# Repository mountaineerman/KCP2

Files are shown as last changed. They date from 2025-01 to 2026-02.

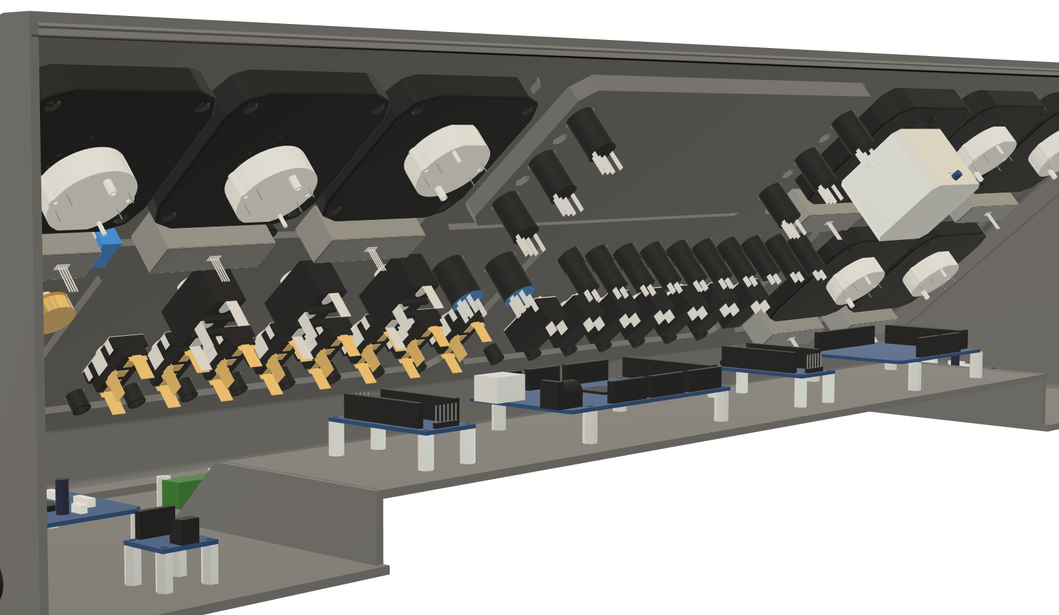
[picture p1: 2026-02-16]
KCP2-physical/Photos/ElectronicsMounted.PNG

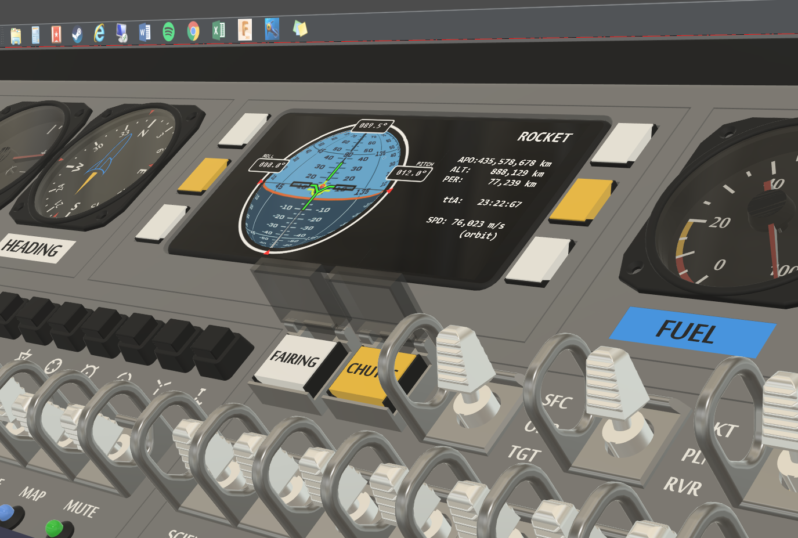
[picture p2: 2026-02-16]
KCP2-physical/Photos/ModuleHredesign.PNG

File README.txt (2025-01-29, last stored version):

Fly:
1. Connect Control Panel to 12V power.
2. Power on Control Panel.
3. Connect Control Panel to computer.
4. Run uber_launch_KCP2_play.cmd (or uber_launch_KCP2_dev.cmd)
5. Launch Flight.
6. Start RPC Server (do once):
	Open kRPC settings
	Select "Add server"
	Keep default settings (TBC)
	Select "Start"
7. If doing development, launch KKIM via F5 from VS Code.

If Control Panel (KMega/KNano) is not correctly programmed, run: re-program_control_panel.cmd

Re-generate KKIM JAR file:
1. Open KKIM in VS Code.
2. Check branch is correct in Git Bash.
3. In the Explorer on the left side, expand JAVA PROJECTS.
4. Beside JAVA PROJECTS, select "Export Jar..." button.
	a. Select main class: Main (mountaineerman.kcp2.kkim.main.Main).
	b. Leave default elements selected.
5. Move/rename: C:\dev\KCP2\KCP2.jar to C:\dev\KCP2\KKIM\KKIM.jar

Graceful shutdown: (center-right glass cockpit button)

Optional: Open ckan.exe & apply mod updates

Logging in to GitHub: use Personal Access Token

KMega Diagnostic Mode (KKIM not used):
1. Connect Control Panel to 12V power.
2. Power on Control Panel.
3. Connect Control Panel to computer.
4. Open Arduino IDE.
5. Open Tools > Serial Monitor.
6. On Control Panel, select Diagnostic Mode button (center-left).

(1) TROUBLESHOOTING ===================================================================================================================================================================================

(A) DEVELOPMENT =======================================================================================================================================================================================

Symptoms:
When trying to program the Arduino board, get message: "the selected serial port does not exist or your board is not connected"
Fix:
In Arduino IDE, select the port to activate it.

Symptoms:
1. When trying to program the Arduino board, get errors: "stk500v2_ReceiveMessage(): timeout"
2. Inspecting Arduino IDE > Tools > Port only shows COM1, instead of COM3.
Fix:
Check USB cable connecting KMega to computer is plugged in and in "ON" position.

Symptoms:
1. When trying to program the Arduino board, get errors: "stk500v2_ReceiveMessage(): timeout"
2. Inspecting Arduino IDE > Tools > Port shows "COM3 (Arduino Mega or Mega 2560)".
Cause 1:
The code is caught in a tight loop, which is preventing the bootloader from connecting.
Fix 1:
Select the "Upload" button. Right before bootloader gets to orange text, hit the RST (reset) mom switch.
Cause 2:
https://forum.arduino.cc/t/avrdude-stk500v2_receivemessage-timeout-sometimes-random/586515
It is necessary to reset the ATmega2560 microcontroller on the Arduino Mega in order to activate the bootloader, which handles the upload. The bootloader only runs for a short time waiting for the computer to start the upload. Since the Arduino IDE spends some time compiling the sketch before actually starting the upload, you have to get the timing right, otherwise the bootloader will have already timed out and exited to the sketch previously loaded on the board before the computer even starts the upload. There is a circuit on the Mega that causes this reset to happen automatically at just the right time. What is connected to the Reset pin can disrupt the automatic circuit.
Fix 2a (temporary):
Disconnected the reset wire to Arduino Mega. The Mega started being programmable reliably.
Fix 2b (TBC):
Remove the 5V and Blue LED from the Reset circuit.

Symptoms: (Delete after settingsFilename absolute path is replaced with relative path)
Changes to config.properties are not being seen by the system
Fix:
Check KKIMProp:settingsFilename is pointing to the correct file.

(B) RUNTIME: ==========================================================================================================================================================================================

Symptoms:
-COMMS LED is flashing
-KKIM ok.
-Control Panel not displaying any information from KSP
-Control Panel not able to control any values in KSP
Cause:
KMega is not receiving control packets from KKIM.
Fix:
Double-check the COM port in KMega configuration.h and KKIM config.properties, and they match what Arduino IDE is detecting.

Symptoms:
Control Panel can control the in-game controls, but there is "jitter". For example, if brake is active on the panel, it flickers between on/off in-game. Similar for throttle.
Fix:
Perhaps some garbage coming through on a port that was not properly closed. Restarting Eclipse and KSP, plus power cycling the panel resolved it.

Symptoms:
-Most lights on.
-Arduino Mega does not "start up".
-Arduino Mega does not respond to Reset signal.
-Programming via Arduino IDE succeeds, but Arduino does not restart.
Cause:
A prototyping sketch was loaded. Everything was working as it should have.

Symptoms:
During "full sweep" of a stepper motor, it "bounces" off an edge and stops in the middle instead of in the CCW position.
Cause:
Initial miscalibration combined with "resonant speed".
Fix:
Do full sweep of motor at a slower speed (300 steps/second) using KMega diagnostic mode.

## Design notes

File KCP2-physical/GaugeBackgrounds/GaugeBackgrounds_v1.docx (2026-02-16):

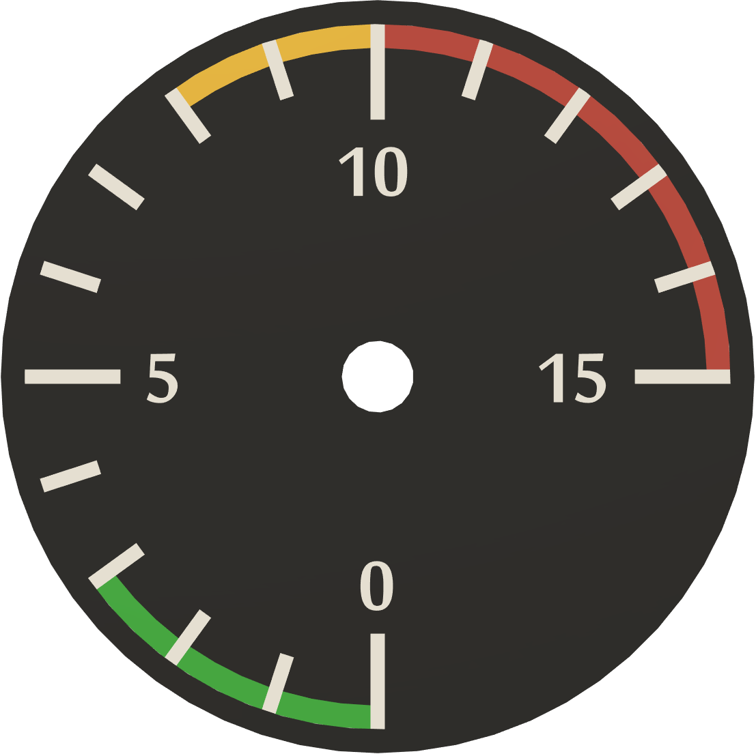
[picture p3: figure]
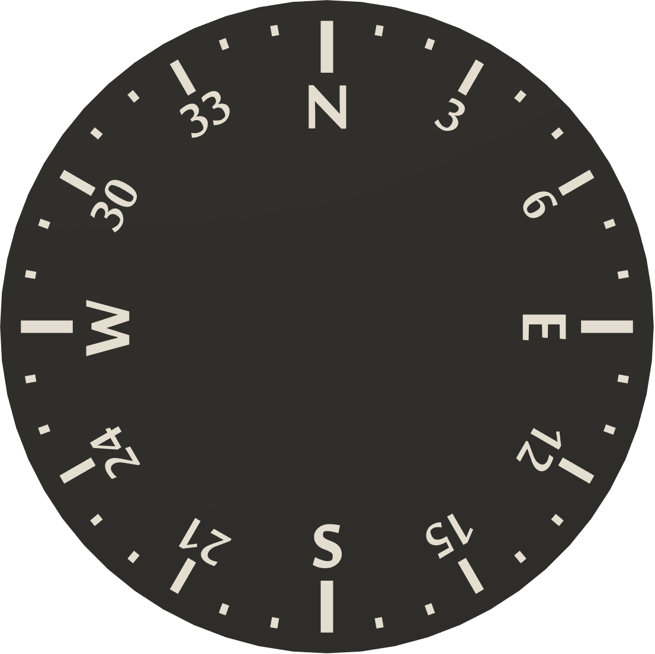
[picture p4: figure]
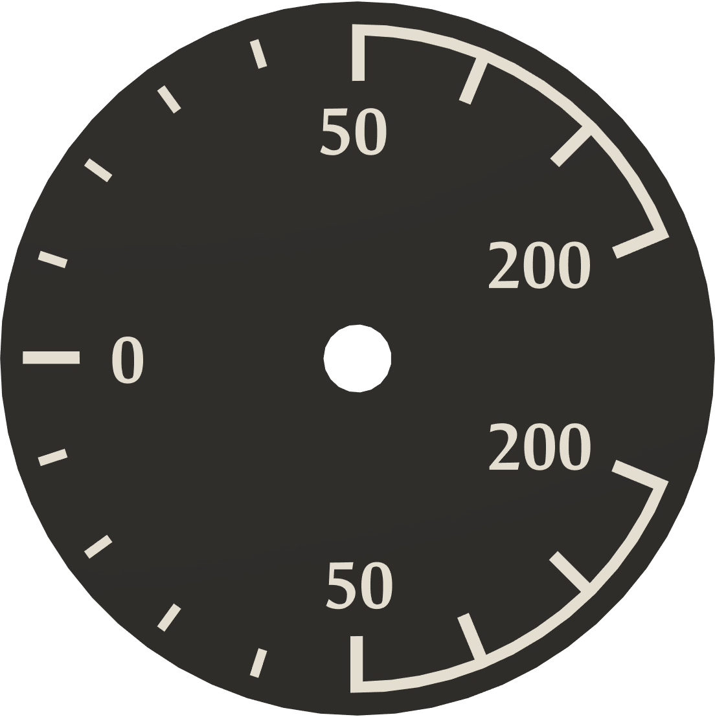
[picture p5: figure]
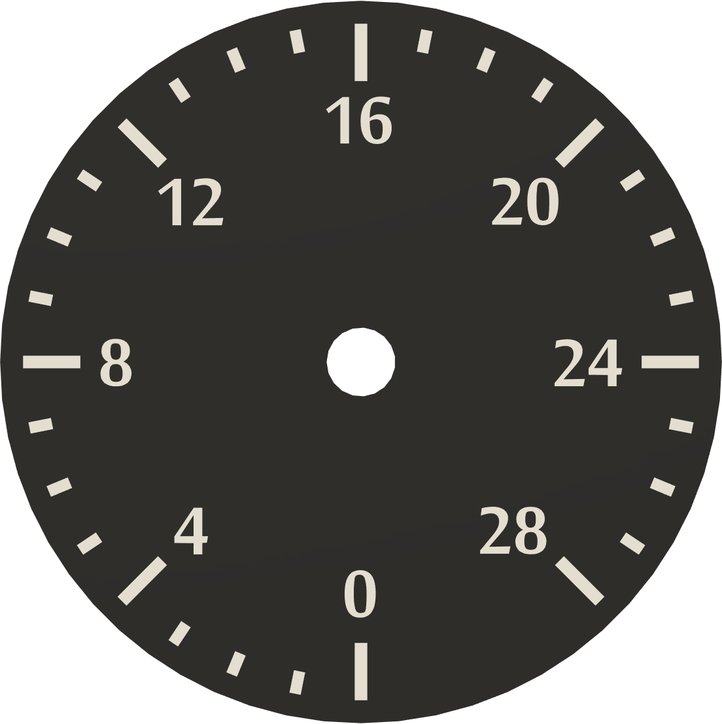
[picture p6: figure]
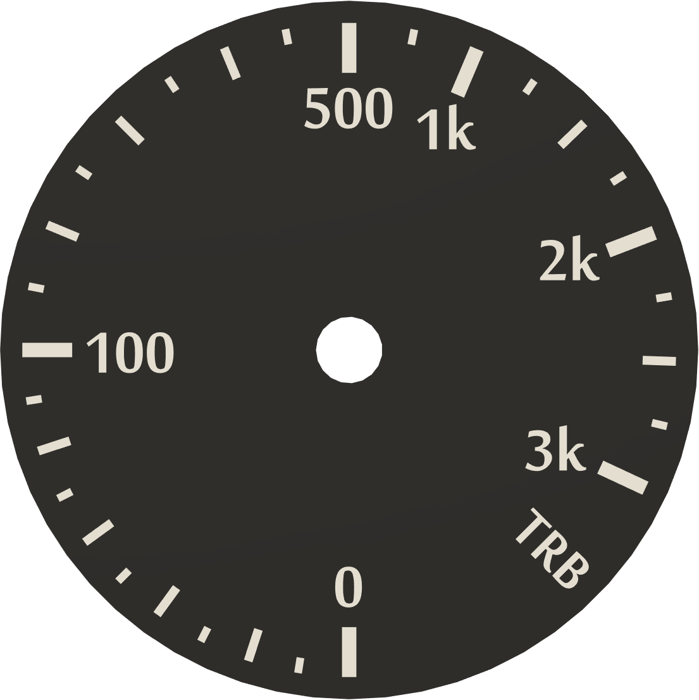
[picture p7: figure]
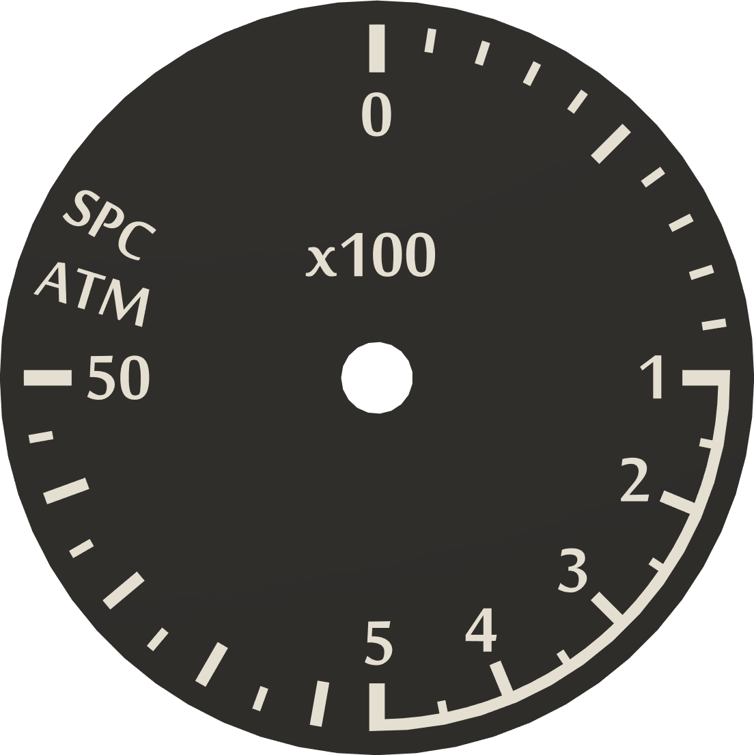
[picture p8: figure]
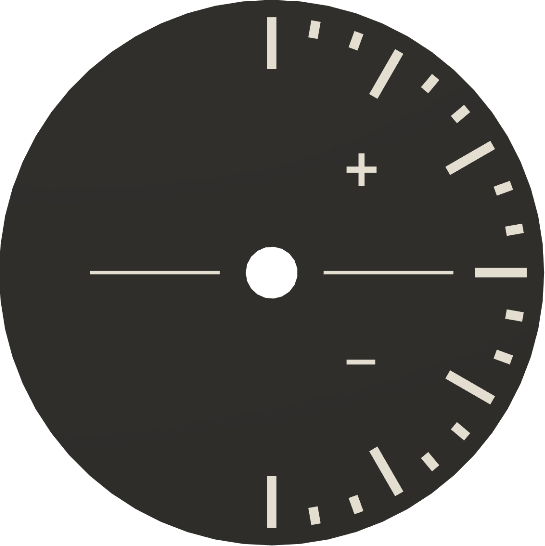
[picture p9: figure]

Note: hole 6mm* Backplate diameter: 63 mm Optimum viewing size: 95%

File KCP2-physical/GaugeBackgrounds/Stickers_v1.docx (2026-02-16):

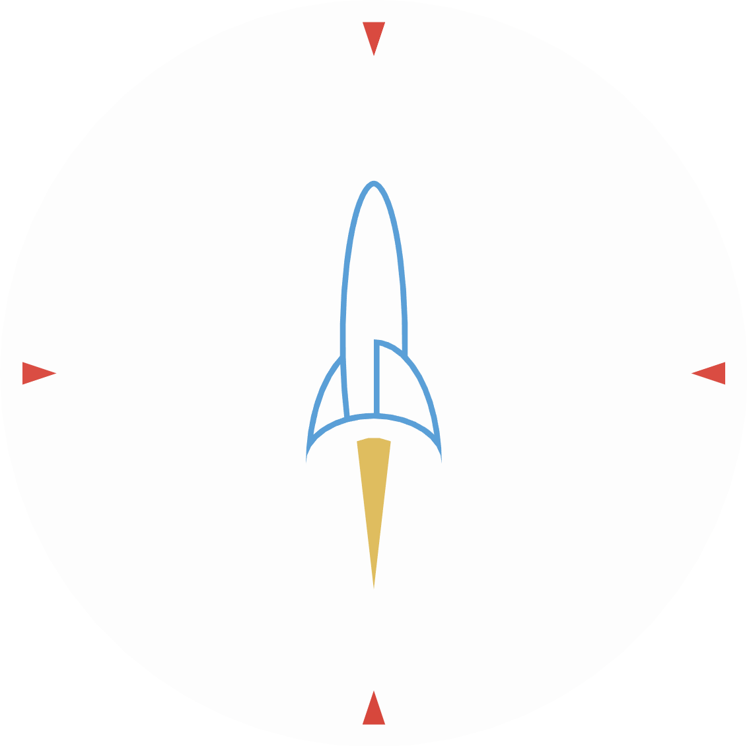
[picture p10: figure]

CHUTE

20x14

FRNG

21x15

CHUTE

FRNG

22x16

CHUTE

FRNG

EasyDriver

LED1

LED2

LED3

LED4

Mega

MUX

Nano

vid6606-1

vid6606-2

vid6606-3

Rocket sticker diameter: 66 mm (v9) Button dimensions: 21 x 15 mm

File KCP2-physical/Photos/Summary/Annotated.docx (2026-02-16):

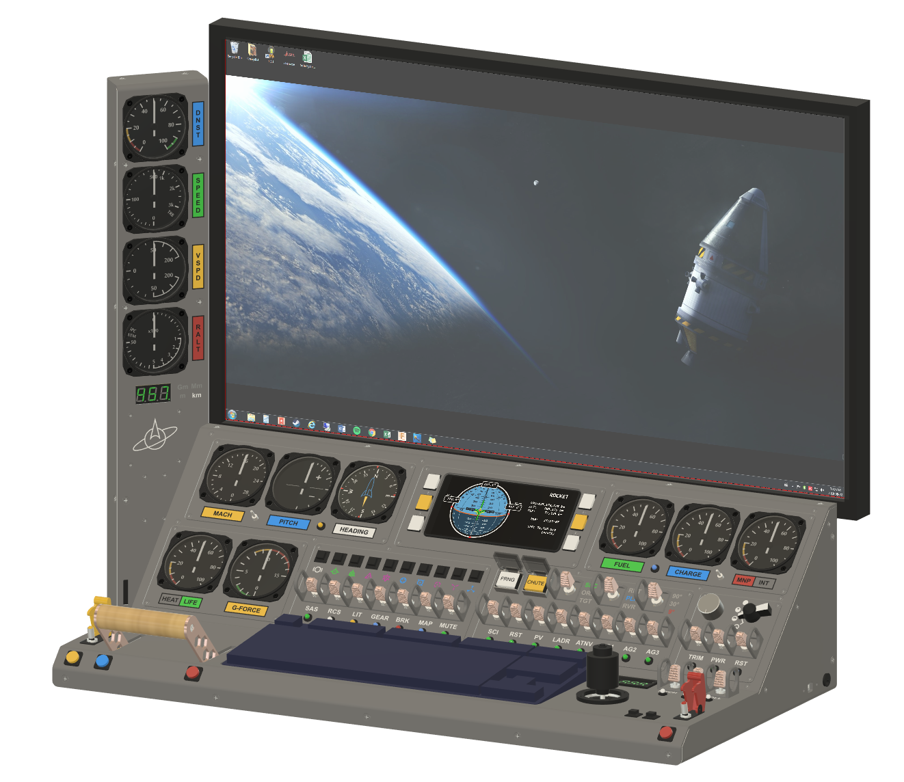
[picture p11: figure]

Gauge Tower

Panel Casing

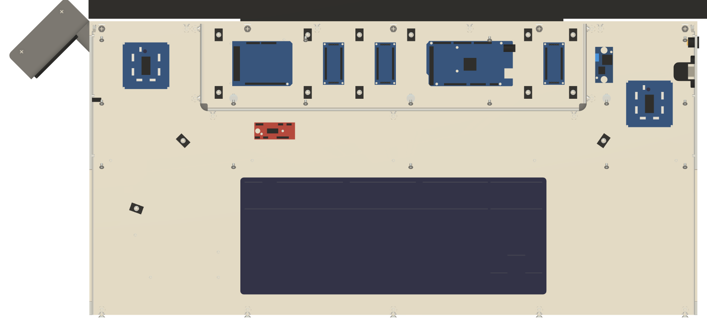
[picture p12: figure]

Arduino Mega

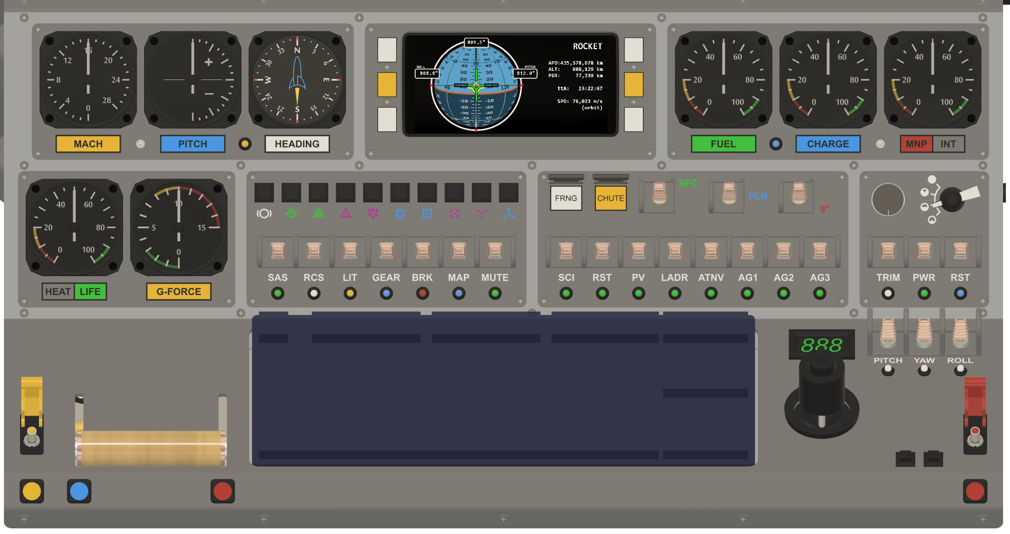
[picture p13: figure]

Module F

Module E

Module D

Module C

Module B

Module A

Module G

Module H

Module I

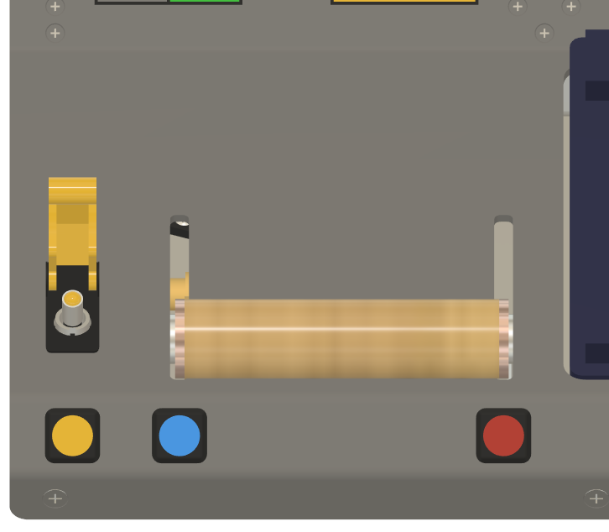
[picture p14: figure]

Brake Momentary Pushbutton

Throttle Toggle Pushbutton

Staging Momentary Pushbutton

Throttle Handlebar

Staging Missile Switch

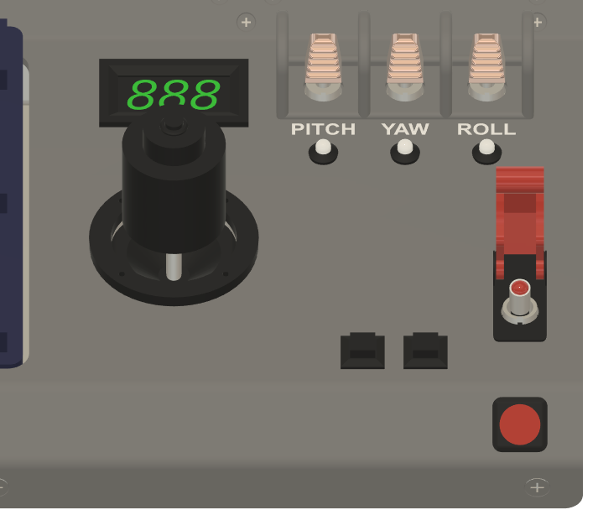
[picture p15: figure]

Trim Controls
(toggle switches)

Abort Missile Switch

Abort Momentary Pushbutton

Time Warp >>

Voltmeter

Time Warp <<

Joystick
(3 axis
+ button)

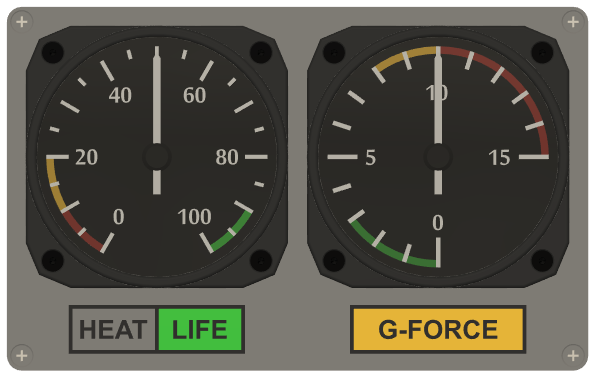
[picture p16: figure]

Geared Analog Stepper Gauges (315° range)

Backlit Lightboxes

(Life Support)

(Max Heat)

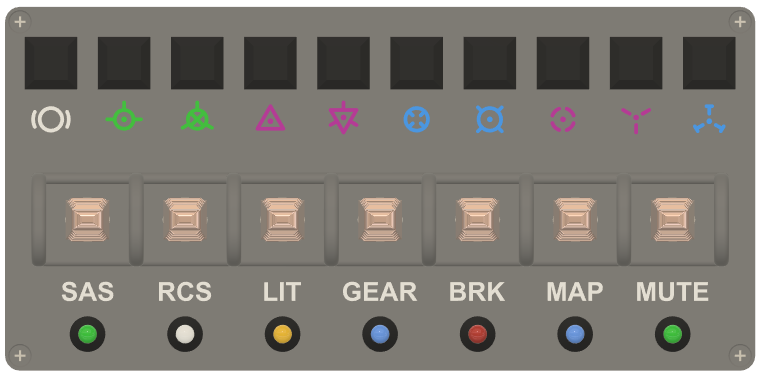
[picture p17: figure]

Backlit

(Hold) (Retrograde) (Anti-normal) (Radial Out) (Anti-Target)

(Prograde) (Normal) (Radial In) (Target) (Maneuver)

Auto-pilot

Toggle Switches

(Stability (Reaction (Lights) (Landing (Brake) (Ship/Map (Phone
Assist Control Gear) view) Speaker)
System) System)

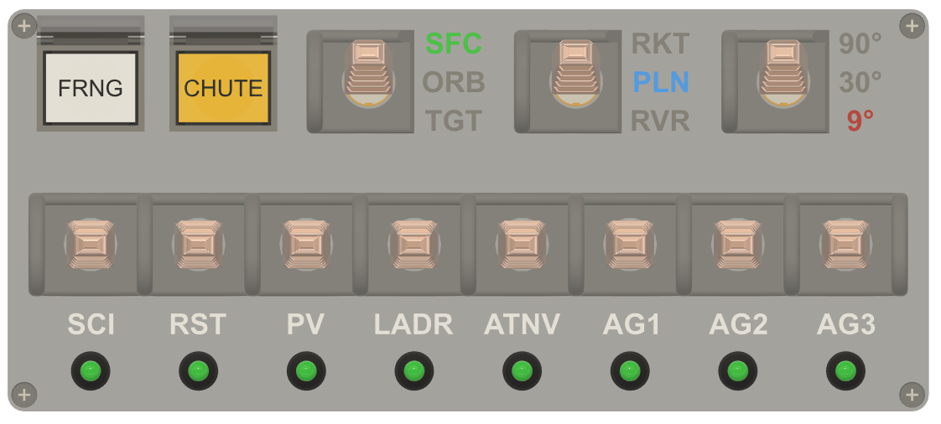
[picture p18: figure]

Covered
Push
Buttons

(Science (Reset (Solar (Ladder) (Auto- (Action (Action (Action
Experiments) Sci.) Panels) Navigation) Group1) Group2) Group3)

Momentary Toggle Switches

3-position Toggle Switches

Speed Reference Maneuver Mode
(Surface) (Rocket)
(Orbit) (Plane)
(Target) (Rover) Pitch Precision

Fairing

Parachute

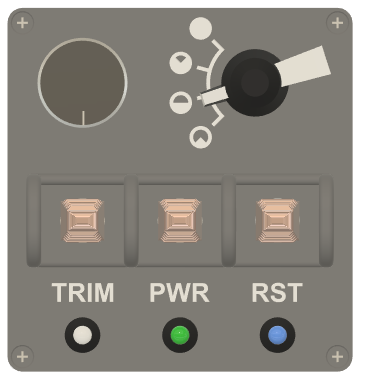
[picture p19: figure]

Trim
Master
Control

Control Panel Master Power
Switch

Arduino Mega Reset

Control Sensitivity
(4-position)

Multi-purpose Potentiometer

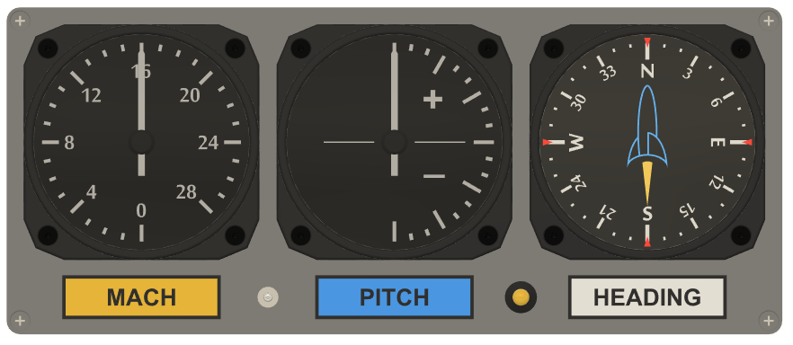
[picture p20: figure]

HEAT/LIFE Toggle Switch

Vehicle Pitch
(90°/30°/9°)

Vehicle Compass Heading

Panel-Computer Communications LED

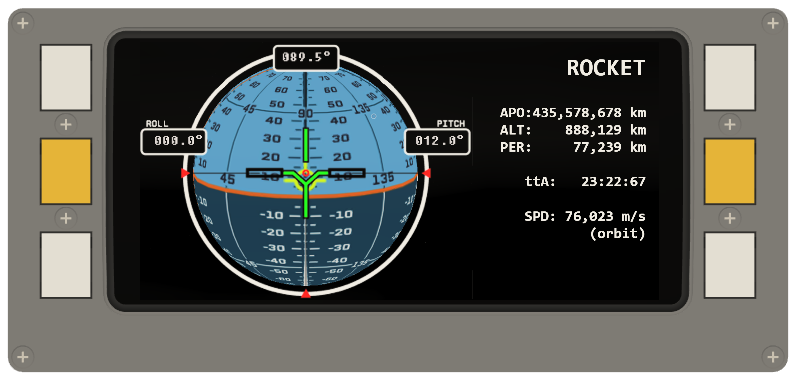
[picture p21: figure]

TR: Top Right

CR: Center Right

BR: Bottom Right

TL: Top Left

CL: Center Left

BL: Bottom Left

Glass Cockpit Momentary Pushbuttons

Phone

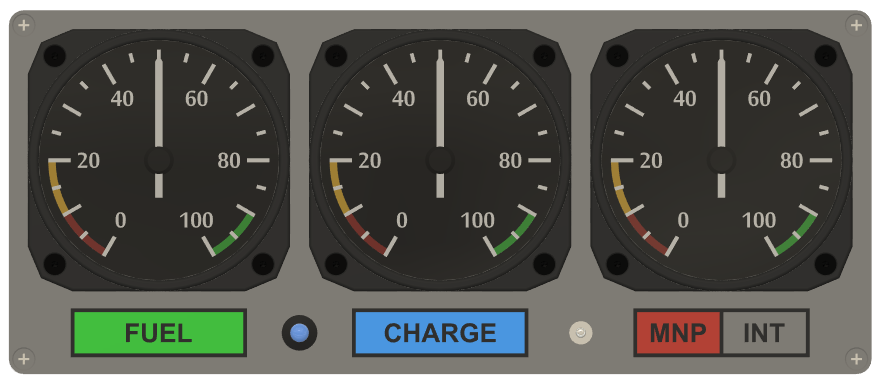
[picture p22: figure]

MNP/INT
Toggle Switch

Intake Air

Monopropellant

Electricity Reserve

Charge
Rate-Of-Change RGB LED

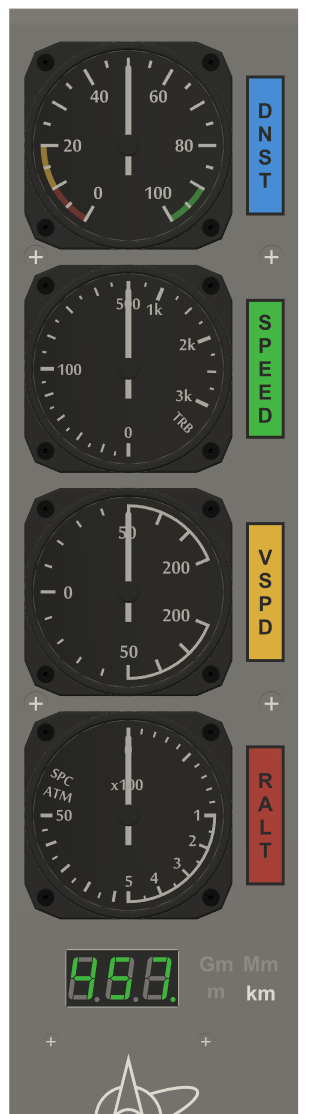
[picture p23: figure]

Altitude

Vehicle Radar Altitude (m)

Vehicle Vertical Speed (m/s)

Vehicle Speed (m/s)

Air
Density

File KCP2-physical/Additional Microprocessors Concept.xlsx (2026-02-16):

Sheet: Pin updates
Driver Board | Gauge | Module | Pin | Mega Pin (old) | Mega Pin (new) | NGH A Pin | NGH B Pin
EasyDriver | Heading | G | SLP | 44 | - | D2 | -
 |  |  | MS1 | 45 | - | D3 | -
 |  |  | MS2 | 46 | - | D4 | -
 |  |  | STEP | 47 | - | D5 | -
 |  |  | DIR | 48 | - | D6 | -
VID6606 #1 (Main Left?) | Heat/Life Support | C | Frequency | 22 | - | D7 | -
 |  |  | Direction | 23 | - | D8 | -
 | G-Force | C | Frequency | 24 | - | D9 | -
 |  |  | Direction | 25 | - | D10 | -
 | Mach | G | Frequency | 26 | - | D11 | -
 |  |  | Direction | 27 | - | D12 | -
 | Pitch | G | Frequency | 28 | - | A0 (D14) | -
 |  |  | Direction | 29 | - | A1 (D15) | -
VID6606 #2 (Main Right?) | Fuel | I | Frequency | 30 | - | A2 (D16) | -
 |  |  | Direction | 31 | - | A3 (D17) | -
 | Charge | I | Frequency | 32 | - | - | D2
 |  |  | Direction | 33 | - | - | D3
 | Monopropellant /Intake | I | Frequency | 34 | - | - | D4
 |  |  | Direction | 35 | - | - | D5
VID6606 #3 (Gauge Tower) | Air Density | GT | Frequency | 36 | - | - | D6
 |  |  | Direction | 37 | - | - | D7
 | Speed | GT | Frequency | 38 | - | - | D8
 |  |  | Direction | 39 | - | - | D9
 | Vertical Speed | GT | Frequency | 40 | - | - | D10
 |  |  | Direction | 41 | - | - | D11
 | Radar Altitude | GT | Frequency | 42 | - | - | A0 (D14)
 |  |  | Direction | 43 | - | - | A1 (D15)
 |  | H | PIN_GLASS_COCKPIT_CR_SWITCH | 16 (TX2) | 22 | - | -
 |  | H | PIN_GLASS_COCKPIT_BR_SWITCH | 17 (RX2) | 23 | - | -
 |  | H | PIN_GLASS_COCKPIT_BL_SWITCH | 14 (TX3) | 24 | - | -
 |  | H | PIN_GLASS_COCKPIT_TR_SWITCH | 15 (RX3) | 25 | - | -
 |  | Case | "NGH A" - RX | - | 16 (TX2) | RX0 | -
 |  | Case | "NGH A" - TX | - | 17 (RX2) | TX1 | -
 |  | Case | "NGH B" - RX | - | 14 (TX3) | - | RX0
 |  | Case | "NGH B" - TX | - | 15 (RX3) | - | TX1
 |  |  |  |  | Pins Required: | 0 | 0 | Nano has 22 pins!

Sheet: Timing Budgets
Arduino Mega: standardOperatingMode | 0
 | Send input packet (periodic) | 0
 |  | refreshInputStatus
 |  | assembleInputRefreshPacket
 |  | sendInputRefreshPacket
 | ingestDataFromSerialBufferToPacketBuffer (regular)
 | ingestOutputRefreshPacket (periodic) | 0
 |  | getOutputRefreshPacket
 |  | unpackOutputRefreshPacketIntoModel
 |  | writeLEDStatusToLEDDriverBoards
 |  | assembleAltitudePacket
 |  | sendAltitudePacket
 |  | assembleGaugePacket1
 |  | sendGaugePacket1
 |  | assembleGaugePacket2
 |  | sendGaugePacket2
 | runStepperIfNecessary (Heading only)
Gauge Arduino #1 (& #2): standardOperatingMode | 0
 | ingestDataFromSerialBufferToPacketBuffer (regular)
 | ingestGaugePacket (periodic) | 0
 |  | getOutputRefreshPacket
 |  | unpackOutputRefreshPacketIntoModel

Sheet: Mega vs Nano
 | Mega (2560 rev3) | Nano
Pins | 54 | 22
PWM Pins | 15 | 6
Analong Input Pins | 16 | 8
SRAM | 8 kB | 2 kB
EEPROM | 4 kB | 1 kB
Clock Speed | 16 MHz | 16 MHz

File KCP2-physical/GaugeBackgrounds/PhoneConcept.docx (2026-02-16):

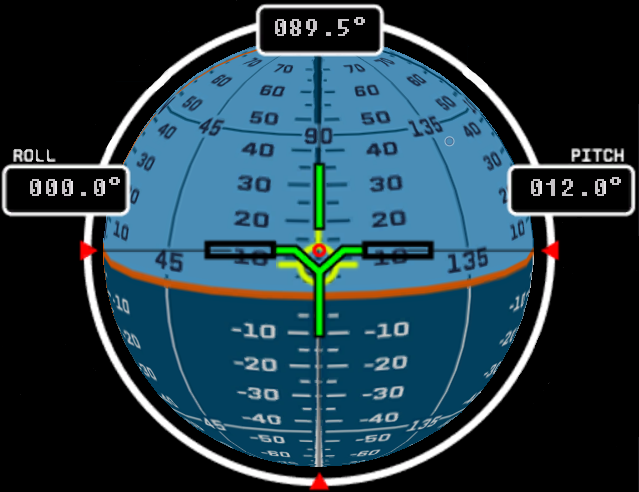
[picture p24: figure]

ROCKET

APO:435,578,678 km

ALT: 888,129 km

PER: 77,239 km

ttA: 23:22:67

SPD: 76,023 m/s

(orbit)

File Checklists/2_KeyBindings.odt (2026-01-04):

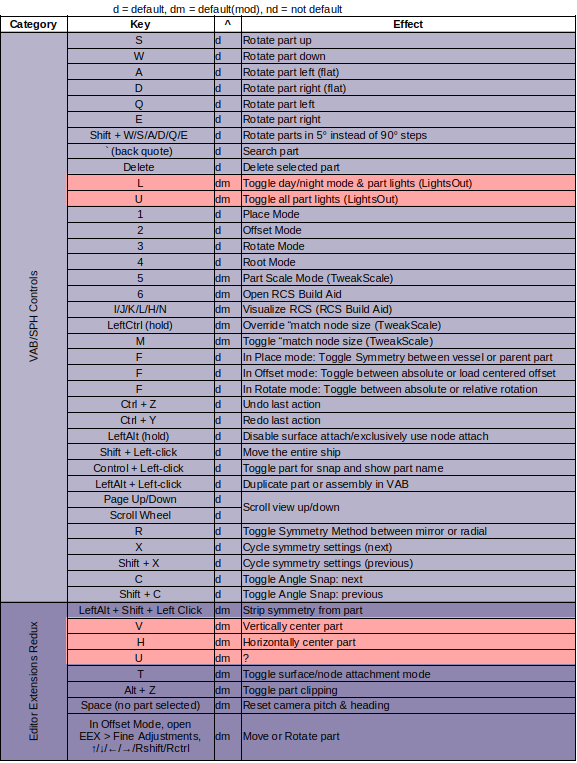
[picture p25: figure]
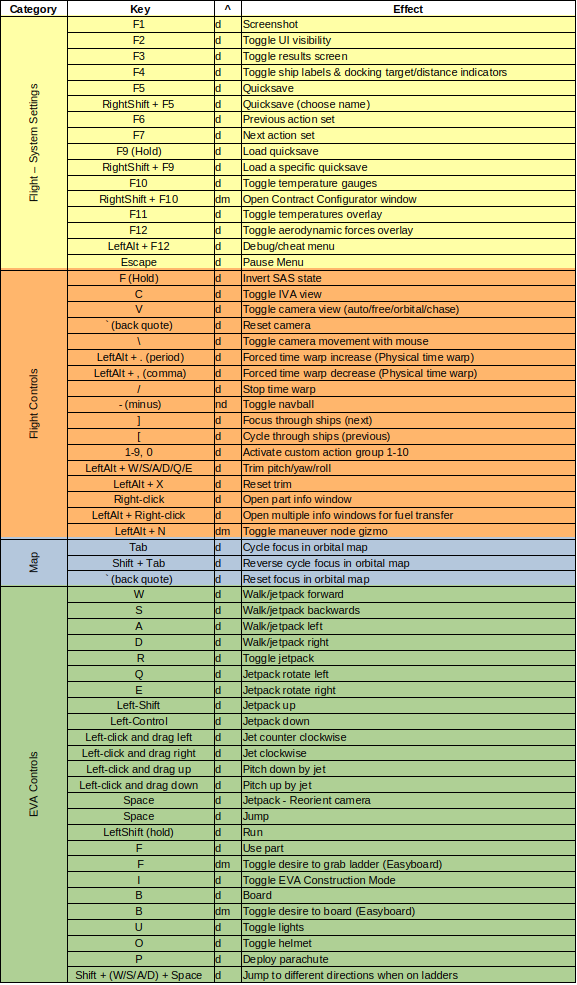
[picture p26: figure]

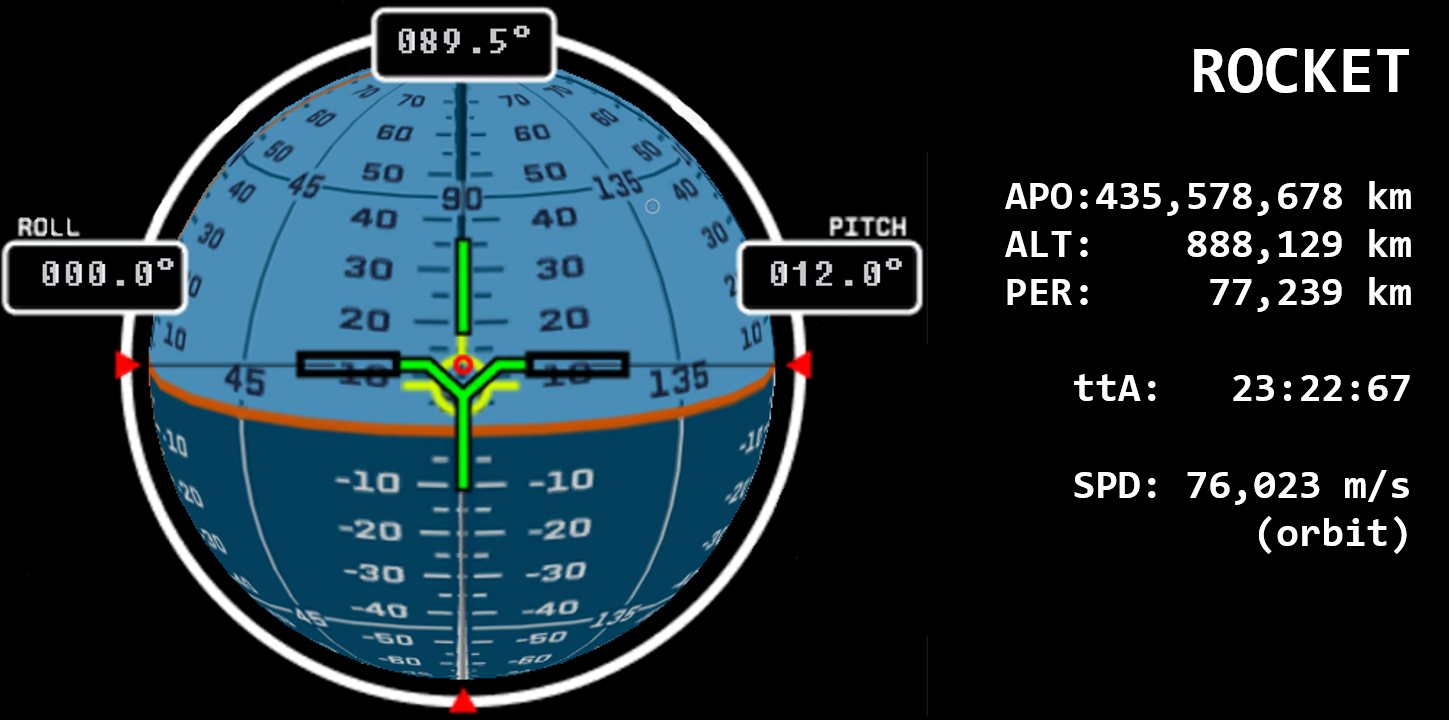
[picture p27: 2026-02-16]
KCP2-physical/GaugeBackgrounds/NavballPhoneConcept.PNG

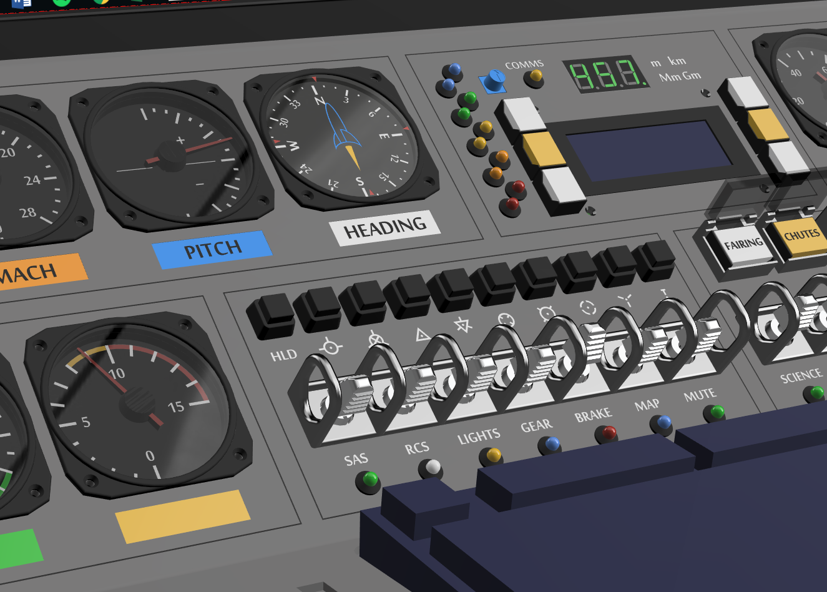
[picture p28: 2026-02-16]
KCP2-physical/Photos/Capture.PNG

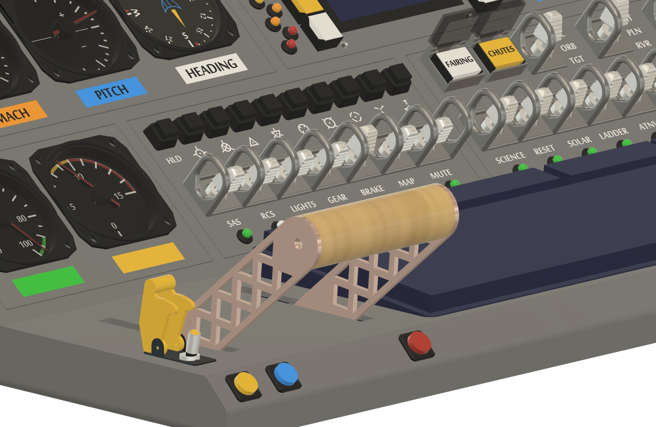
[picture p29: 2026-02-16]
KCP2-physical/Photos/PrelimThrottleHandle.PNG

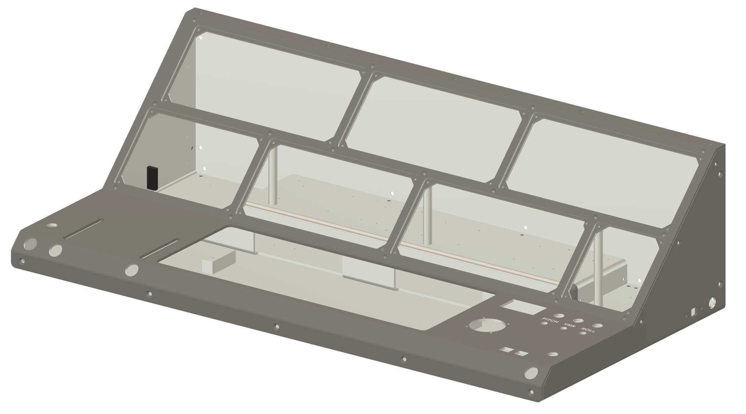
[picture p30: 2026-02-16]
KCP2-physical/Photos/PanelCasing.PNG

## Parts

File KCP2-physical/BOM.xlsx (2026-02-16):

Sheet: Bill of Materials
Module | Part | # | CA | US | CAD | USD | Total (CAD) | Note
All | Panel Casing & Module Plates | 0 | Metal Alloy Fabrication |  | $1881.94 |  | $0.00 | (For Sum)
A | Small Gear (16T, 1/4" bore) | 1 |  | Sparkfun (https://www.sparkfun.com/products/12158) |  | $12.99 | $17.02
A | Large Gear (32T, 1/4" bore) | 1 |  | Sparkfun (https://www.sparkfun.com/products/12476) |  | $12.99 | $17.02
A | Missile Switch (lit, yellow) | 1 | Elmwood (https://elmwoodelectronics.ca/products/illuminated-toggle-switch-with-cover-yellow) | Adafruit (https://www.adafruit.com/product/3219) | $4.99 |  | $4.99 | Staging
A | Pushbutton (lit, yellow, mom) | 1 | Elmwood (https://elmwoodelectronics.ca/products/16mm-illuminated-pushbutton-yellow-momentary) | Adafruit (https://www.adafruit.com/product/1441) | $3.79 |  | $3.79 | Staging
A | Potentiometer (10 kohm) | 1 | Elmwood (https://elmwoodelectronics.ca/products/panel-mount-10k-potentiometer-breadboard-friendly) | Adafruit (https://www.adafruit.com/product/562) | $3.49 |  | $3.49
A | Pushbutton (lit, blue, latching) | 1 | Elmwood (https://elmwoodelectronics.ca/products/16mm-illuminated-pushbutton-blue-latching-on-off-switch) | Adafruit (https://www.adafruit.com/product/1476) | $4.59 |  | $4.59 | Throttle
A | Pushbutton (lit, red, mom) | 1 | Elmwood (https://elmwoodelectronics.ca/products/16mm-illuminated-pushbutton-red-momentary) | Adafruit (https://www.adafruit.com/product/1439) | $3.79 |  | $3.79 | Brake
A | Rubber washers | 4 | Lowes |  | $1.31 |  | $5.23 | Throttle
A | 1" x 48" wooden dowel | 1 | Lowes |  | $7.34 |  | $7.34 | Throttle
A | Throttle Handlebar | 2 | Metal Alloy Fabrication |  | $23.84 |  | $47.67
A | Throttle Mounting Bracket | 1 | Metal Alloy Fabrication |  | $57.54 |  | $57.54
B | Missile Switch (lit, red) | 1 | Elmwood (https://elmwoodelectronics.ca/products/illuminated-toggle-switch-with-cover-red) | Adafruit (https://www.adafruit.com/product/3218) | $4.99 |  | $4.99 | Abort
B | Pushbutton (lit, red, mom) | 1 | Elmwood (https://elmwoodelectronics.ca/products/16mm-illuminated-pushbutton-red-momentary) | Adafruit (https://www.adafruit.com/product/1439) | $3.79 |  | $3.79 | Abort
B | 4-Axis Joystick | 1 |  | Ebay (https://www.ebay.ca/itm/282456733701) |  | $13.59 | $17.80
B | Panel Voltmeter | 1 | Elmwood (https://elmwoodelectronics.ca/products/panel-volt-meter) | Adafruit (https://www.adafruit.com/product/575) | $11.99 |  | $11.99
B | Pushbutton (black, mom) | 2 | Digikey (https://www.digikey.ca/en/products/detail/e-switch/PS1057ABLK/46305) |  | $2.44 |  | $4.88 | Time Warp
B | Toggle Switch | 3 | Elmwood (https://elmwoodelectronics.ca/products/9276) | Sparkfun (https://www.sparkfun.com/products/9276) | $2.99 |  | $8.97 | Pitch/Yaw/Roll
B | 5mm LED (white) | 3 | Elmwood (https://elmwoodelectronics.ca/products/100-led-assortment) |  | $0.09 |  | $0.27 | Pitch/Yaw/Roll
B | 5mm LED Holder | 3 |  | Adafruit (https://www.adafruit.com/product/2174) | $0.19 |  | $0.57
C | x27.168 stepper motor | 2 | Elmwood (https://elmwoodelectronics.ca/products/automotive-gauge-stepper-motor) | Adafruit (https://www.adafruit.com/product/2424) | $13.19 |  | $26.38
C | Rectangular RGB LED | 3 | Elmwood (https://elmwoodelectronics.ca/products/diffused-rectangular-5mm-rgb-leds-pack-of-10) | Adafruit (https://www.adafruit.com/product/2739) | $0.90 |  | $2.70
C | Module C Acrylic Plate | 1 | Metal Alloy Fabrication |  | $74.39 |  | $74.39
D | 5mm LED (yellow) | 1 | Elmwood (https://elmwoodelectronics.ca/products/100-led-assortment) |  | $0.09 |  | $0.09 | Lights
D | 5mm LED (green) | 2 | Elmwood (https://elmwoodelectronics.ca/products/100-led-assortment) |  | $0.09 |  | $0.18 | SAS, Mute
D | 5mm LED (white) | 2 | Elmwood (https://elmwoodelectronics.ca/products/100-led-assortment) |  | $0.09 |  | $0.18 | RCS, AUTOPILOT-HOLD
D | 5mm LED (red) | 1 | Elmwood (https://elmwoodelectronics.ca/products/100-led-assortment) |  | $0.09 |  | $0.09 | Brake
D | 5mm LED (blue) | 2 | Elmwood (https://elmwoodelectronics.ca/products/100-led-assortment) |  | $0.09 |  | $0.18 | Gear, Map
D | 5mm LED Holder | 7 |  | Adafruit (https://www.adafruit.com/product/2174) | $0.19 |  | $1.33
D | Toggle Switch | 7 | Elmwood (https://elmwoodelectronics.ca/products/9276) | Sparkfun (https://www.sparkfun.com/products/9276) | $2.99 |  | $20.93
D | Pushbutton (black, mom) | 10 | Digikey (https://www.digikey.ca/en/products/detail/e-switch/PS1057ABLK/46305) |  | $2.44 |  | $24.40 | Autopilot
D | Rectangular RGB LED | 9 | Elmwood (https://elmwoodelectronics.ca/products/diffused-rectangular-5mm-rgb-leds-pack-of-10) | Adafruit (https://www.adafruit.com/product/2739) | $0.90 |  | $8.09 | Autopilot Reticules (Hold, Prograde, Retrograde, Normal, Anti-Normal, Radial In, Radial Out, Target Prograde, Target Retrograde, Maneuver)
D | Module D Acrylic Plate | 1 | Metal Alloy Fabrication |  | $88.08 |  | $88.08
E | 5mm LED (blue) | 3 | Elmwood (https://elmwoodelectronics.ca/products/100-led-assortment) |  | $0.09 |  | $0.27 | 3POS Lights
E | 5mm LED (red) | 3 | Elmwood (https://elmwoodelectronics.ca/products/100-led-assortment) |  | $0.09 |  | $0.27 | 3POS Lights
E | 5mm LED (green) | 11 | Elmwood (https://elmwoodelectronics.ca/products/100-led-assortment) |  | $0.09 |  | $0.99 | 3POS Lights, Action Groups
E | 5mm LED Holder | 11 |  | Adafruit (https://www.adafruit.com/product/2174) | $0.19 |  | $2.09
E | Toggle Switch - Momentary | 8 | Digikey (https://www.digikey.ca/product-detail/en/electroswitch/7162C/451-1166-ND/2679549) |  | $6.01 |  | $48.06
E | Toggle Switch - SP3T | 3 | Ebay (https://www.ebay.ca/itm/12V-Metal-Toggle-Flick-Switch-ON-OFF-ON-Car-Boat-Dash-Light-3-Position-SP3T-/361502103461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) |  | $1.79 |  | $5.37
E | Pushbutton Cover | 2 | Ebay (https://www.ebay.ca/itm/310827399171) |  | $1.09 |  | $2.17
E | Pushbutton (lit, yellow, rectangular-large) | 1 | Ebay (https://vod.ebay.ca/vod/FetchOrderDetails?transid=885606284025&itemid=382086328207&qu=2&ul_noapp=true) |  | $3.04 |  | $3.04 | Chute
E | Pushbutton (lit, white, rectangular-large) | 1 | Ebay (https://vod.ebay.ca/vod/FetchOrderDetails?transid=885606284025&itemid=382086328207&qu=2&ul_noapp=true) |  | $3.04 |  | $3.04 | Fairing
E | Module E Acrylic Plate | 1 | Metal Alloy Fabrication |  | $88.59 |  | $88.59
F | 5mm LED (green) | 1 | Elmwood (https://elmwoodelectronics.ca/products/100-led-assortment) |  | $0.09 |  | $0.09 | Power
F | 5mm LED (blue) | 1 | Elmwood (https://elmwoodelectronics.ca/products/100-led-assortment) |  | $0.09 |  | $0.09 | Reset
F | 5mm LED (white) | 1 | Elmwood (https://elmwoodelectronics.ca/products/100-led-assortment) |  | $0.09 |  | $0.09
F | 5mm LED Holder | 3 |  | Adafruit (https://www.adafruit.com/product/2174) | $0.19 |  | $0.57
F | 3mm LED (white) | 4 |  |  | $0.00 |  | $0.00 | 4POS Twist Switch Lights
F | Toggle Switch | 2 | Elmwood (https://elmwoodelectronics.ca/products/9276) | Sparkfun (https://www.sparkfun.com/products/9276) | $2.99 |  | $5.98 | Power
F | Toggle Switch - Momentary | 1 | Digikey (https://www.digikey.ca/product-detail/en/electroswitch/7162C/451-1166-ND/2679549) |  | $6.01 |  | $6.01 | Reset
F | Potentiometer (10 kohm) | 1 | Elmwood (https://elmwoodelectronics.ca/products/panel-mount-10k-potentiometer-breadboard-friendly) | Adafruit (https://www.adafruit.com/product/562) | $3.49 |  | $3.49
F | Potentiometer Knob | 1 | Elmwood (https://elmwoodelectronics.ca/products/10002) |  | $3.99 |  | $3.99 | Fits 1/4" shaft
F | INA169 DC Current Sensor | 1 | Elmwood (https://elmwoodelectronics.ca/products/ina169-analog-dc-current-sensor-breakout-60v-5a-max) | Adafruit (https://www.adafruit.com/product/1164) | $13.99 |  | $13.99
F | 4POS Twist Switch | 1 |  |  | $0.00 |  | $0.00
F | Module F Acrylic Plate | 1 | Metal Alloy Fabrication |  | $70.99 |  | $70.99
G | x27.168 stepper motor | 2 | Elmwood (https://elmwoodelectronics.ca/products/automotive-gauge-stepper-motor) | Adafruit (https://www.adafruit.com/product/2424) | $13.19 |  | $26.38
G | 5mm LED (yellow) | 1 | Elmwood (https://elmwoodelectronics.ca/products/100-led-assortment) |  | $0.09 |  | $0.09 | COMMS
G | 5mm LED Holder | 1 |  | Adafruit (https://www.adafruit.com/product/2174) | $0.19 |  | $0.19
G | Toggle Switch - Mini | 1 |  |  | $0.00 |  | $0.00 | HEAT/LIFE
G | Rectangular RGB LED | 3 | Elmwood (https://elmwoodelectronics.ca/products/diffused-rectangular-5mm-rgb-leds-pack-of-10) | Adafruit (https://www.adafruit.com/product/2739) | $0.90 |  | $2.70
G | NEMA17 Motor | 1 | Elmwood (https://elmwoodelectronics.ca/products/9238) | Sparkfun (https://www.sparkfun.com/products/9238) | $22.99 |  | $22.99 | Heading Motor (360° rotation)
G | Module G Acrylic Plate | 1 | Metal Alloy Fabrication |  | $76.30 |  | $76.30
H | Pushbutton (lit, yellow, rectangular-small) | 2 | Ebay (https://www.ebay.ca/myb/PurchaseHistory?_trksid=p2055359.m2034.l3391) |  | $2.75 |  | $5.49 | Glass Cockpit Button
H | Pushbutton (lit, white, rectangular-small) | 4 | Ebay (https://www.ebay.ca/myb/PurchaseHistory?_trksid=p2055359.m2034.l3391) |  | $2.75 |  | $10.98 | Glass Cockpit Button
H | Module H Acrylic Plate | 1 | Metal Alloy Fabrication |  | $75.82 |  | $75.82
I | Toggle Switch - Mini | 1 |  |  | $0.00 |  | $0.00 | MNPR/INTK
I | 5mm RGB LED | 1 |  | Adafruit (https://www.adafruit.com/product/159) | $2.00 |  | $2.00 | FUEL rate-of-change
I | 5mm LED Holder | 1 |  | Adafruit (https://www.adafruit.com/product/2174) | $0.19 |  | $0.19
I | x27.168 stepper motor | 3 | Elmwood (https://elmwoodelectronics.ca/products/automotive-gauge-stepper-motor) | Adafruit (https://www.adafruit.com/product/2424) | $13.19 |  | $39.57
I | Rectangular RGB LED | 4 | Elmwood (https://elmwoodelectronics.ca/products/diffused-rectangular-5mm-rgb-leds-pack-of-10) | Adafruit (https://www.adafruit.com/product/2739) | $0.90 |  | $3.60
I | Module I Acrylic Plate | 1 | Metal Alloy Fabrication |  | $77.88 |  | $77.88
U | Panel Mount 2.1mm Barrel Jack | 1 | Elmwood (https://elmwoodelectronics.ca/products/panel-mount-2-1mm-dc-barrel-jack) | Adafruit (https://www.adafruit.com/product/610) | $4.99 |  | $4.99
U | 2.1mm Barrel Connector | 1 | Elmwood (https://elmwoodelectronics.ca/products/5_5-2_1mm-barrel-connector-dc-power-plug) | Adafruit (https://www.adafruit.com/product/3310) | $2.99 |  | $2.99
U | Panel Mount USB Type B | 1 | Elmwood (https://elmwoodelectronics.ca/products/panel-mount-usb-cable-b-male-to-b-female) | Adafruit (https://www.adafruit.com/product/907) | $5.99 |  | $5.99
U | VID6606 stepper driver board | 2 |  | Tindie (https://www.tindie.com/products/propwashsim/vid6606-4x-stepper-driver-board/) |  | $19.50 | $51.09
U | EasyDriver Stepper Driver | 1 | Elmwood (https://elmwoodelectronics.ca/products/12779) | Sparkfun (https://www.sparkfun.com/products/12779) | $21.99 |  | $21.99
U | Arduino Mega 2560 R3 |  |  | Sparkfun (https://www.sparkfun.com/products/11061) |  |  | $0.00
U | Arduino Nano | 3 |  | Sparkfun (https://www.sparkfun.com/arduino-nano-every.html) |  | $13.70 | $53.84
U | Mini Heat Sink (10 pack, with thermal tape) | 1 | Elmwood (https://elmwoodelectronics.ca/products/aluminum-smt-heat-sinks-10-pack-0-25x0-25-x-0-15-tall) | Adafruit (https://www.adafruit.com/product/1515) | $7.99 |  | $7.99
U | DC-DC Converter (12V to 5V) | 1 | Amazon (https://www.amazon.ca/Erayco-LM2596-Converter-3-0-40V-1-5-35V/dp/B07JNQFV7F?rnid=5690384011&rps=1) |  | $2.00 |  | $2.00 | 12 Vdc > 5Vdc, 3A
U | Mux Shield II | 1 | Elmwood (https://elmwoodelectronics.ca/products/11723) |  | $44.89 |  | $44.89
U | 24 LED driver board | 3 | Elmwood (https://elmwoodelectronics.ca/products/adafruit-24-channel-12-bit-pwm-led-driver-spi-interface) | Adafruit (https://www.adafruit.com/product/1429) | $20.99 |  | $62.97
U | 3A Fuse | 1 | Digikey (https://www.digikey.ca/en/products/detail/bel-fuse-inc/5MF-3-R/1009038) |  | $0.30 |  | $0.30
U | Fuse Holder | 1 | Digikey (https://www.digikey.ca/en/products/detail/würth-elektronik/696211001102/7244564) |  | $2.33 |  | $2.33
U | Keyboard Pillar | 4 |  | Shapeways |  | $7.91 | $41.45
GT | x27.168 stepper motor | 4 | Elmwood (https://elmwoodelectronics.ca/products/automotive-gauge-stepper-motor) | Adafruit (https://www.adafruit.com/product/2424) | $13.19 |  | $52.76
GT | Rectangular RGB LED | 4 | Elmwood (https://elmwoodelectronics.ca/products/diffused-rectangular-5mm-rgb-leds-pack-of-10) | Adafruit (https://www.adafruit.com/product/2739) | $0.90 |  | $3.60
GT | VID6606 stepper driver board | 1 |  | Tindie (https://www.tindie.com/products/propwashsim/vid6606-4x-stepper-driver-board/) |  | $19.50 | $25.55
GT | 3 Digit 7-SEG Display | 1 | Digikey (https://www.digikey.ca/product-detail/en/kingbright/BA56-12GWA/754-1656-5-ND/3084327) |  | $7.24 |  | $7.24
GT | 5mm LED (white) | 4 | Elmwood (https://elmwoodelectronics.ca/products/100-led-assortment) |  | $0.09 |  | $0.36
GT | 24 LED driver board | 1 | Elmwood (https://elmwoodelectronics.ca/products/adafruit-24-channel-12-bit-pwm-led-driver-spi-interface) | Adafruit (https://www.adafruit.com/product/1429) | $20.99 |  | $20.99
GT | Magnet | 4 | Elmwood (https://elmwoodelectronics.ca/products/8890) |  | $1.99 |  | $7.96
GT | Gauge Tower - Front Panel | 1 | Metal Alloy Fabrication |  | $148.45 |  | $148.45
GT | Gauge Tower - Back Panel | 1 | Metal Alloy Fabrication |  | $70.51 |  | $70.51
GT | Gauge Tower - Acrylic Panel | 1 | Metal Alloy Fabrication |  | $75.51 |  | $75.51
All | Analog Gauge - Needle | 12 |  | Shapeways |  | $5.30 | $83.32
All | Computer-Arduino Cable (Standard USB A-B) | 1 |  |  |  |  | $0.00
All | AC-DC Wall Plug Converter/Power Supply | 1 | Digikey (https://www.digikey.ca/product-detail/en/globtek-inc/WR9HE3000CCP-F(R6B)/1939-1464-ND/8598267) |  | $23.09 |  | $23.09 | 120Vac > 12Vdc, 3A
All | Hookup Wire (22AWG, solid core) | 1 | Elmwood (https://elmwoodelectronics.ca/products/11367) |  | $25.99 |  | $25.99
All | Hookup Wire (22AWG, solid core) | 2 | Digikey (https://www.digikey.ca/en/products/detail/sparkfun-electronics/PRT-11367/5956251) |  | $22.57 |  | $45.14
All | Connectors (large single row) | 3 | Elmwood (https://elmwoodelectronics.ca/products/large-single-row-housing-pack-for-diy-jumper-cables) | Adafruit (https://www.adafruit.com/product/3146) | $4.99 |  | $14.97
All | Connectors (small double row) | 3 | Elmwood (https://elmwoodelectronics.ca/products/small-dual-row-wire-housing-pack-for-diy-jumper-cables) | Adafruit (https://www.adafruit.com/product/3143) | $3.99 |  | $11.97
All | Connectors (large double row) | 2 | Elmwood (https://elmwoodelectronics.ca/products/large-dual-row-wire-housing-pack-for-diy-jumper-cables) | Adafruit (https://www.adafruit.com/product/3144) | $5.99 |  | $11.98
All | Ribbon Cable (10 wire, 15ft, 28AWG) | 2 | Elmwood (https://elmwoodelectronics.ca/products/10647) | Sparkfun | $7.99 |  | $15.98
All | Ribbon Cable (6 wire, 15ft, 28AWG) | 2 | Elmwood (https://elmwoodelectronics.ca/products/10646) | Sparkfun | $4.99 |  | $9.98
All | Raw Male-Female Jumper Wires | 8 | Elmwood (https://elmwoodelectronics.ca/products/premium-male-female-raw-jumper-wires-40-x-6) |  | $4.99 |  | $39.92
All | Stranded Wire: 24 AWG, Red,Black,Green | 4 |  | Pololu (https://www.pololu.com/account/view_salesorder/1J335359?s=fa90adff) |  | $4.75 | $24.89
All | Stranded Wire: 24 AWG, Blue,White,Yellow | 3 |  |  |  | $5.75 | $22.60
All | Male Crimp Pins (x100) | 6 |  | Pololu (https://www.pololu.com/product/1931) |  | $7.95 | $62.49
All | Female Crimp Pins (x100) | 6 |  | Pololu (https://www.pololu.com/product/1930) |  | $5.95 | $46.77
All | 1x4 Crimp Connector Housing (x10) | 6 |  | Pololu (https://www.pololu.com/account/view_salesorder/1J335359?s=fa90adff) |  | $0.59 | $4.64
All | 1x1 Crimp Connector Housing (x25) | 10 |  | Pololu (https://www.pololu.com/account/view_salesorder/1J335359?s=fa90adff) |  | $0.53 | $6.94
All | 1x2 Crimp Connector Housing (x25) | 2 |  | Pololu (https://www.pololu.com/account/view_salesorder/1J335359?s=fa90adff) |  | $0.69 | $1.81
All | Crimping Tool | 1 |  | Pololu (https://www.pololu.com/product/1929) |  | $29.95 | $39.23
All | 3x8 Female Header | 2 |  | Pololu (https://www.pololu.com/account/view_salesorder/1J335359?s=fa90adff) |  | $1.49 | $3.90
All | Female/Male Headers | 1 | Amazon |  | $23.86 |  | $23.86
All | Wire Strippers | 1 | Amazon |  | $11.74 |  | $11.74
All | Paint (matte grey) | 2 | Home Depot |  | $10.05 |  | $20.09
All | Paint (frosted glass) | 1 | Home Depot |  | $12.29 |  | $12.29
All | Short Column | 2 | Metal Alloy Fabrication |  | $43.00 |  | $86.00
All | Long Column | 1 | Metal Alloy Fabrication |  | $77.02 |  | $77.02
All | Casing - Top Plate | 1 | Metal Alloy Fabrication |  | $210.56 |  | $210.56
All | Casing - Mounting Plate | 1 | Metal Alloy Fabrication |  | $144.26 |  | $144.26
All | Casing - Dodge Plate | 1 | Metal Alloy Fabrication |  | $94.92 |  | $94.92
All | Casing - Bottom Plate | 1 | Metal Alloy Fabrication |  | $142.76 |  | $142.76
All | Casing - Back Plate | 1 | Metal Alloy Fabrication |  | $67.12 |  | $67.12
All | Analog Gauge - Screen | 12 | Metal Alloy Fabrication |  | $7.17 |  | $86.06
Ship | Tindie | 1 |  |  |  | $22.00 | $28.82 | (Ship+Tax)
Ship | Pololu | 1 |  | Pololu |  | $58.31 | $76.39 | (Ship+Tax)
Ship | Fastenal | 1 |  |  | $171.46 |  | $171.46 | (Ship+Tax+Parts)
Ship | Elmwood | 1 |  |  | $26.55 |  | $26.55 | (Ship+Tax)
Ship | Adafruit (2020-10-31) | 1 |  |  |  | $21.40 | $28.03
Ship | Sparkfun (2020-10-31) | 1 |  |  |  | $5.42 | $7.10 | (Ship+Tax)
Ship | Digikey (2021-05-17) | 1 |  |  | $9.00 |  | $9.00
Ship | Shapeways (2021-05-09) | 0 |  |  |  | $14.99 | $0.00 | (Promo code waived shipping)
Ship | Digikey (2021-11-17) | 1 |  |  | $10.26 |  | $10.26
Ship | Pololu (2021-11-23) | 1 |  |  | $53.20 |  | $53.20
Misc | Fusion 360 Subscription | 1 |  |  | $89.60 |  | $89.60
Misc | 3D Printing | 1 |  |  | $100.00 |  | $100.00
Misc | Analog Gauge Backgrounds - Printing | 1 |  |  | $5.60 |  | $5.60
Misc | Stickers - Printing | 1 |  |  | $16.80 |  | $16.80
Misc | Home Depot - Paint, Brushes, Filler | 1 |  |  | $60.05 |  | $60.05
Misc | Filler spray paint | 1 | Home Depot |  | $15.00 |  | $15.00
Misc | Fast Drying Urethane Spray Paint (3D printing smoothing agent) | 1 | Lowes |  | $16.26 |  | $16.26
 |  |  |  |  |  |  | $3978.22
1.31 | Exchange Rate (1 USD = X CAD)

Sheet: Fasteners
 |  |  |  |  |  |  |  |  | mm |  |  | Inches
Description | SKU | Head | Price/100 | Min # | Quantity | Cost | Thread | Head Angle | A | B | C | A2 | B2 | C2
Fastenal:
Stepper gauge assembly screw (https://www.fastenal.com/products/details/24160) | 24160 |  | 4.88 | 48 | 100 | 4.88 | #3-48 | 80-84° | 5.05 | 2.51 | 15.88 | 0.199 | 0.099 | 0.625
Stepper gauge assembly nut (https://www.fastenal.com/products/details/36008) | 36008 |  | 8.12 | 48 | 100 | 8.12 | #3-48 |  | - | 4.57 | 1.68 | - | 0.18 | 0.066
Stepper motor mounting screw (https://www.fastenal.com/products/details/0170305) | 0170305 |  | 54.99 | 22 | 35 | 19.25 | #0-80 | flat | 2.87 | 1.35 | 19.05 | 0.113 | 0.053 | 0.75
NEMA17 motor mounting screw (https://www.fastenal.com/products/details/XM2510010A20000) | XM2510010A20000 |  | 6.42 | 4 | 6 | 0.39 | M3x0.5 | 90-92° | 5.50 |  | 10.00
Standoff (https://www.fastenal.com/products/details/0145976) | 0145976 |  | 34 | 38 | 60 | 20.40 | #4-40 |  | 4.76 | - | 12.70 | 0.1875 | - | 0.5
Standoff top screw (https://www.fastenal.com/products/details/83041) | 83041 |  | 4.46 | 38 | 100 | 4.46 | #4-40 | flat | 4.65 |  | 4.76 | 0.183 |  | 0.1875
Standoff under screw (https://www.fastenal.com/products/details/29375) | 29375 |  | 4.23 | 38 | 100 | 4.23 | #4-40 | 80-82° | 5.38 |  | 9.65 | 0.212 |  | 0.38
Shipping + Tax |  |  |  |  |  | 9.18
Fastenal:
Handle Screw (https://www.fastenal.ca/sku/29446) | 29446 | Cross | 7 | 2 | 40 | 2.80 | #8-32 | 80-82° |  |  | 25.40 |  |  | 1
Throttle threaded rod (https://www.fastenal.ca/sku/47057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) | 47057 |  | 299 | 1 | 1 | 2.99 | 1/4"-20 |  |  | 6.35 | 3 ft |  | 0.25
1/4" Jam Nut (https://www.fastenal.ca/sku/36201?attributeName_0=Dia%2FThread+Size&attributeValue_0=1%2F4%22-20) | 36201 |  | 7 | 8 | 30 | 2.10 | 1/4"-20 |  |  |  | 3.96 |  |  | 0.156
1/4" Washer (https://www.fastenal.ca/sku/33078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) | 33078 |  | 6 | 12 | 30 | 1.80 | 1/4"
Cable tie mount screw (https://www.fastenal.ca/sku/91185?attributeName_0=Head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) | 91185 | Cross | 8 | 16 | 50 | 4.00 | M3x0.5 | flat |  |  | 4
#8-32 Nut (https://www.fastenal.ca/sku/0148194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) | 0148194 |  | 6 | 37 | 100 | 6.00 | #8-32 |  |  |  | 3.30 |  |  | 0.13
"Bracket" Screw (1/4") (https://www.fastenal.ca/sku/72640?attributeName_0=Length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) | 72640 | Cross | 6 | 37 | 100 | 6.00 | #8-32 | 80-82° |  |  | 6.35 |  |  | 0.25
"Bracket" Screw (5/16") (https://www.fastenal.ca/sku/72637?attributeName_0=Length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) | 72637 | Cross | 6 | 37 | 100 | 6.00 | #8-32 | 80-82° |  |  | 7.94 |  |  | 0.31
Plate-plate assembly screw (https://www.fastenal.ca/sku/91285?attributeName_0=Length&attributeValue_0=6mm&showAll=__Dia%2FThread+Size__) | 91285 | Cross | 2 | 60 | 150 | 3.00 | M3x0.5 | 90-92° |  |  | 6.00
Long M3 Screw (https://www.fastenal.ca/sku/XM2510016A20000?attributeName_0=Length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) | XM2510016A20000 | Cross | 6 | 18 | 100 | 6.00 | M3x0.5 | 90-92° |  |  | 16
M3 Nut (https://www.fastenal.ca/sku/MN2510000A40000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) | MN2510000A40000 |  | 3 | 4 | 100 | 3.00 | M3x0.5 |  |  |  | 2.4
Shipping + Tax |  |  |  |  |  | 5.48
Digikey:
Zip tie mount (https://www.digikey.ca/product-detail/en/phoenix-contact/3240703/277-16294-ND/4461928) | n/a |  | 9.69 | 15 | 100 | 9.69
611 Right Angle Bracket (https://www.digikey.ca/product-detail/en/keystone-electronics/611/36-611-ND/631427) |  |  | 50.08 | 35 | 50 | 25.04 | #8-32
Shipping + Tax |  |  |  |  |  | 16.66
Total (USD) |  |  |  |  |  | 171.46
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

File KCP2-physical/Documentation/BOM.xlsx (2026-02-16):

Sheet: Bill of Materials
Module | Part | # | CA | US | CAD | USD | Total (CAD) | Note
All | Panel Casing & Module Plates | 0 | Metal Alloy Fabrication |  | $1881.94 |  | $0.00 | (For Sum)
A | Small Gear (16T, 1/4" bore) | 1 |  | Sparkfun (https://www.sparkfun.com/products/12158) |  | $12.99 | $17.02
A | Large Gear (32T, 1/4" bore) | 1 |  | Sparkfun (https://www.sparkfun.com/products/12476) |  | $12.99 | $17.02
A | Missile Switch (lit, yellow) | 1 | Elmwood (https://elmwoodelectronics.ca/products/illuminated-toggle-switch-with-cover-yellow) | Adafruit (https://www.adafruit.com/product/3219) | $4.99 |  | $4.99 | Staging
A | Pushbutton (lit, yellow, mom) | 1 | Elmwood (https://elmwoodelectronics.ca/products/16mm-illuminated-pushbutton-yellow-momentary) | Adafruit (https://www.adafruit.com/product/1441) | $3.79 |  | $3.79 | Staging
A | Potentiometer (10 kohm) | 1 | Elmwood (https://elmwoodelectronics.ca/products/panel-mount-10k-potentiometer-breadboard-friendly) | Adafruit (https://www.adafruit.com/product/562) | $3.49 |  | $3.49
A | Pushbutton (lit, blue, latching) | 1 | Elmwood (https://elmwoodelectronics.ca/products/16mm-illuminated-pushbutton-blue-latching-on-off-switch) | Adafruit (https://www.adafruit.com/product/1476) | $4.59 |  | $4.59 | Throttle
A | Pushbutton (lit, red, mom) | 1 | Elmwood (https://elmwoodelectronics.ca/products/16mm-illuminated-pushbutton-red-momentary) | Adafruit (https://www.adafruit.com/product/1439) | $3.79 |  | $3.79 | Brake
A | Rubber washers | 4 | Lowes |  | $1.31 |  | $5.23 | Throttle
A | 1" x 48" wooden dowel | 1 | Lowes |  | $7.34 |  | $7.34 | Throttle
A | Throttle Handlebar | 2 | Metal Alloy Fabrication |  | $23.84 |  | $47.67
A | Throttle Mounting Bracket | 1 | Metal Alloy Fabrication |  | $57.54 |  | $57.54
B | Missile Switch (lit, red) | 1 | Elmwood (https://elmwoodelectronics.ca/products/illuminated-toggle-switch-with-cover-red) | Adafruit (https://www.adafruit.com/product/3218) | $4.99 |  | $4.99 | Abort
B | Pushbutton (lit, red, mom) | 1 | Elmwood (https://elmwoodelectronics.ca/products/16mm-illuminated-pushbutton-red-momentary) | Adafruit (https://www.adafruit.com/product/1439) | $3.79 |  | $3.79 | Abort
B | 4-Axis Joystick | 1 |  | Ebay (https://www.ebay.ca/itm/282456733701) |  | $13.59 | $17.80
B | Panel Voltmeter | 1 | Elmwood (https://elmwoodelectronics.ca/products/panel-volt-meter) | Adafruit (https://www.adafruit.com/product/575) | $11.99 |  | $11.99
B | Pushbutton (black, mom) | 2 | Digikey (https://www.digikey.ca/en/products/detail/e-switch/PS1057ABLK/46305) |  | $2.44 |  | $4.88 | Time Warp
B | Toggle Switch | 3 | Elmwood (https://elmwoodelectronics.ca/products/9276) | Sparkfun (https://www.sparkfun.com/products/9276) | $2.99 |  | $8.97 | Pitch/Yaw/Roll
B | 5mm LED (white) | 3 | Elmwood (https://elmwoodelectronics.ca/products/100-led-assortment) |  | $0.09 |  | $0.27 | Pitch/Yaw/Roll
B | 5mm LED Holder | 3 |  | Adafruit (https://www.adafruit.com/product/2174) | $0.19 |  | $0.57
C | x27.168 stepper motor | 2 | Elmwood (https://elmwoodelectronics.ca/products/automotive-gauge-stepper-motor) | Adafruit (https://www.adafruit.com/product/2424) | $13.19 |  | $26.38
C | Rectangular RGB LED | 3 | Elmwood (https://elmwoodelectronics.ca/products/diffused-rectangular-5mm-rgb-leds-pack-of-10) | Adafruit (https://www.adafruit.com/product/2739) | $0.90 |  | $2.70
C | Module C Acrylic Plate | 1 | Metal Alloy Fabrication |  | $74.39 |  | $74.39
D | 5mm LED (yellow) | 1 | Elmwood (https://elmwoodelectronics.ca/products/100-led-assortment) |  | $0.09 |  | $0.09 | Lights
D | 5mm LED (green) | 2 | Elmwood (https://elmwoodelectronics.ca/products/100-led-assortment) |  | $0.09 |  | $0.18 | SAS, Mute
D | 5mm LED (white) | 2 | Elmwood (https://elmwoodelectronics.ca/products/100-led-assortment) |  | $0.09 |  | $0.18 | RCS, AUTOPILOT-HOLD
D | 5mm LED (red) | 1 | Elmwood (https://elmwoodelectronics.ca/products/100-led-assortment) |  | $0.09 |  | $0.09 | Brake
D | 5mm LED (blue) | 2 | Elmwood (https://elmwoodelectronics.ca/products/100-led-assortment) |  | $0.09 |  | $0.18 | Gear, Map
D | 5mm LED Holder | 7 |  | Adafruit (https://www.adafruit.com/product/2174) | $0.19 |  | $1.33
D | Toggle Switch | 7 | Elmwood (https://elmwoodelectronics.ca/products/9276) | Sparkfun (https://www.sparkfun.com/products/9276) | $2.99 |  | $20.93
D | Pushbutton (black, mom) | 10 | Digikey (https://www.digikey.ca/en/products/detail/e-switch/PS1057ABLK/46305) |  | $2.44 |  | $24.40 | Autopilot
D | Rectangular RGB LED | 9 | Elmwood (https://elmwoodelectronics.ca/products/diffused-rectangular-5mm-rgb-leds-pack-of-10) | Adafruit (https://www.adafruit.com/product/2739) | $0.90 |  | $8.09 | Autopilot Reticules (Hold, Prograde, Retrograde, Normal, Anti-Normal, Radial In, Radial Out, Target Prograde, Target Retrograde, Maneuver)
D | Module D Acrylic Plate | 1 | Metal Alloy Fabrication |  | $88.08 |  | $88.08
E | 5mm LED (blue) | 3 | Elmwood (https://elmwoodelectronics.ca/products/100-led-assortment) |  | $0.09 |  | $0.27 | 3POS Lights
E | 5mm LED (red) | 3 | Elmwood (https://elmwoodelectronics.ca/products/100-led-assortment) |  | $0.09 |  | $0.27 | 3POS Lights
E | 5mm LED (green) | 11 | Elmwood (https://elmwoodelectronics.ca/products/100-led-assortment) |  | $0.09 |  | $0.99 | 3POS Lights, Action Groups
E | 5mm LED Holder | 11 |  | Adafruit (https://www.adafruit.com/product/2174) | $0.19 |  | $2.09
E | Toggle Switch - Momentary | 8 | Digikey (https://www.digikey.ca/product-detail/en/electroswitch/7162C/451-1166-ND/2679549) |  | $6.01 |  | $48.06
E | Toggle Switch - SP3T | 3 | Ebay (https://www.ebay.ca/itm/12V-Metal-Toggle-Flick-Switch-ON-OFF-ON-Car-Boat-Dash-Light-3-Position-SP3T-/361502103461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) |  | $1.79 |  | $5.37
E | Pushbutton Cover | 2 | Ebay (https://www.ebay.ca/itm/310827399171) |  | $1.09 |  | $2.17
E | Pushbutton (lit, yellow, rectangular-large) | 1 | Ebay (https://vod.ebay.ca/vod/FetchOrderDetails?transid=885606284025&itemid=382086328207&qu=2&ul_noapp=true) |  | $3.04 |  | $3.04 | Chute
E | Pushbutton (lit, white, rectangular-large) | 1 | Ebay (https://vod.ebay.ca/vod/FetchOrderDetails?transid=885606284025&itemid=382086328207&qu=2&ul_noapp=true) |  | $3.04 |  | $3.04 | Fairing
E | Module E Acrylic Plate | 1 | Metal Alloy Fabrication |  | $88.59 |  | $88.59
F | 5mm LED (green) | 1 | Elmwood (https://elmwoodelectronics.ca/products/100-led-assortment) |  | $0.09 |  | $0.09 | Power
F | 5mm LED (blue) | 1 | Elmwood (https://elmwoodelectronics.ca/products/100-led-assortment) |  | $0.09 |  | $0.09 | Reset
F | 5mm LED (white) | 1 | Elmwood (https://elmwoodelectronics.ca/products/100-led-assortment) |  | $0.09 |  | $0.09
F | 5mm LED Holder | 3 |  | Adafruit (https://www.adafruit.com/product/2174) | $0.19 |  | $0.57
F | 3mm LED (white) | 4 |  |  | $0.00 |  | $0.00 | 4POS Twist Switch Lights
F | Toggle Switch | 2 | Elmwood (https://elmwoodelectronics.ca/products/9276) | Sparkfun (https://www.sparkfun.com/products/9276) | $2.99 |  | $5.98 | Power
F | Toggle Switch - Momentary | 1 | Digikey (https://www.digikey.ca/product-detail/en/electroswitch/7162C/451-1166-ND/2679549) |  | $6.01 |  | $6.01 | Reset
F | Potentiometer (10 kohm) | 1 | Elmwood (https://elmwoodelectronics.ca/products/panel-mount-10k-potentiometer-breadboard-friendly) | Adafruit (https://www.adafruit.com/product/562) | $3.49 |  | $3.49
F | Potentiometer Knob | 1 | Elmwood (https://elmwoodelectronics.ca/products/10002) |  | $3.99 |  | $3.99 | Fits 1/4" shaft
F | INA169 DC Current Sensor | 1 | Elmwood (https://elmwoodelectronics.ca/products/ina169-analog-dc-current-sensor-breakout-60v-5a-max) | Adafruit (https://www.adafruit.com/product/1164) | $13.99 |  | $13.99
F | 4POS Twist Switch | 1 |  |  | $0.00 |  | $0.00
F | Module F Acrylic Plate | 1 | Metal Alloy Fabrication |  | $70.99 |  | $70.99
G | x27.168 stepper motor | 2 | Elmwood (https://elmwoodelectronics.ca/products/automotive-gauge-stepper-motor) | Adafruit (https://www.adafruit.com/product/2424) | $13.19 |  | $26.38
G | 5mm LED (yellow) | 1 | Elmwood (https://elmwoodelectronics.ca/products/100-led-assortment) |  | $0.09 |  | $0.09 | COMMS
G | 5mm LED Holder | 1 |  | Adafruit (https://www.adafruit.com/product/2174) | $0.19 |  | $0.19
G | Toggle Switch - Mini | 1 |  |  | $0.00 |  | $0.00 | HEAT/LIFE
G | Rectangular RGB LED | 3 | Elmwood (https://elmwoodelectronics.ca/products/diffused-rectangular-5mm-rgb-leds-pack-of-10) | Adafruit (https://www.adafruit.com/product/2739) | $0.90 |  | $2.70
G | NEMA17 Motor | 1 | Elmwood (https://elmwoodelectronics.ca/products/9238) | Sparkfun (https://www.sparkfun.com/products/9238) | $22.99 |  | $22.99 | Heading Motor (360° rotation)
G | Module G Acrylic Plate | 1 | Metal Alloy Fabrication |  | $76.30 |  | $76.30
H | Pushbutton (lit, yellow, rectangular-small) | 2 | Ebay (https://www.ebay.ca/myb/PurchaseHistory?_trksid=p2055359.m2034.l3391) |  | $2.75 |  | $5.49 | Glass Cockpit Button
H | Pushbutton (lit, white, rectangular-small) | 4 | Ebay (https://www.ebay.ca/myb/PurchaseHistory?_trksid=p2055359.m2034.l3391) |  | $2.75 |  | $10.98 | Glass Cockpit Button
H | Module H Acrylic Plate | 1 | Metal Alloy Fabrication |  | $75.82 |  | $75.82
I | Toggle Switch - Mini | 1 |  |  | $0.00 |  | $0.00 | MNPR/INTK
I | 5mm RGB LED | 1 |  | Adafruit (https://www.adafruit.com/product/159) | $2.00 |  | $2.00 | FUEL rate-of-change
I | 5mm LED Holder | 1 |  | Adafruit (https://www.adafruit.com/product/2174) | $0.19 |  | $0.19
I | x27.168 stepper motor | 3 | Elmwood (https://elmwoodelectronics.ca/products/automotive-gauge-stepper-motor) | Adafruit (https://www.adafruit.com/product/2424) | $13.19 |  | $39.57
I | Rectangular RGB LED | 4 | Elmwood (https://elmwoodelectronics.ca/products/diffused-rectangular-5mm-rgb-leds-pack-of-10) | Adafruit (https://www.adafruit.com/product/2739) | $0.90 |  | $3.60
I | Module I Acrylic Plate | 1 | Metal Alloy Fabrication |  | $77.88 |  | $77.88
U | Panel Mount 2.1mm Barrel Jack | 1 | Elmwood (https://elmwoodelectronics.ca/products/panel-mount-2-1mm-dc-barrel-jack) | Adafruit (https://www.adafruit.com/product/610) | $4.99 |  | $4.99
U | 2.1mm Barrel Connector | 1 | Elmwood (https://elmwoodelectronics.ca/products/5_5-2_1mm-barrel-connector-dc-power-plug) | Adafruit (https://www.adafruit.com/product/3310) | $2.99 |  | $2.99
U | Panel Mount USB Type B | 1 | Elmwood (https://elmwoodelectronics.ca/products/panel-mount-usb-cable-b-male-to-b-female) | Adafruit (https://www.adafruit.com/product/907) | $5.99 |  | $5.99
U | VID6606 stepper driver board | 2 |  | Tindie (https://www.tindie.com/products/propwashsim/vid6606-4x-stepper-driver-board/) |  | $19.50 | $51.09
U | EasyDriver Stepper Driver | 1 | Elmwood (https://elmwoodelectronics.ca/products/12779) | Sparkfun (https://www.sparkfun.com/products/12779) | $21.99 |  | $21.99
U | Arduino Mega 2560 R3 |  |  | Sparkfun (https://www.sparkfun.com/products/11061) |  |  | $0.00
U | Arduino Nano | 3 |  | Sparkfun (https://www.sparkfun.com/arduino-nano-every.html) |  | $13.70 | $53.84
U | Mini Heat Sink (10 pack, with thermal tape) | 1 | Elmwood (https://elmwoodelectronics.ca/products/aluminum-smt-heat-sinks-10-pack-0-25x0-25-x-0-15-tall) | Adafruit (https://www.adafruit.com/product/1515) | $7.99 |  | $7.99
U | DC-DC Converter (12V to 5V) | 1 | Amazon (https://www.amazon.ca/Erayco-LM2596-Converter-3-0-40V-1-5-35V/dp/B07JNQFV7F?rnid=5690384011&rps=1) |  | $2.00 |  | $2.00 | 12 Vdc > 5Vdc, 3A
U | Mux Shield II | 1 | Elmwood (https://elmwoodelectronics.ca/products/11723) |  | $44.89 |  | $44.89
U | 24 LED driver board | 3 | Elmwood (https://elmwoodelectronics.ca/products/adafruit-24-channel-12-bit-pwm-led-driver-spi-interface) | Adafruit (https://www.adafruit.com/product/1429) | $20.99 |  | $62.97
U | 3A Fuse | 1 | Digikey (https://www.digikey.ca/en/products/detail/bel-fuse-inc/5MF-3-R/1009038) |  | $0.30 |  | $0.30
U | Fuse Holder | 1 | Digikey (https://www.digikey.ca/en/products/detail/w%C3%BCrth-elektronik/696211001102/7244564) |  | $2.33 |  | $2.33
U | Keyboard Pillar | 4 |  | Shapeways |  | $7.91 | $41.45
GT | x27.168 stepper motor | 4 | Elmwood (https://elmwoodelectronics.ca/products/automotive-gauge-stepper-motor) | Adafruit (https://www.adafruit.com/product/2424) | $13.19 |  | $52.76
GT | Rectangular RGB LED | 4 | Elmwood (https://elmwoodelectronics.ca/products/diffused-rectangular-5mm-rgb-leds-pack-of-10) | Adafruit (https://www.adafruit.com/product/2739) | $0.90 |  | $3.60
GT | VID6606 stepper driver board | 1 |  | Tindie (https://www.tindie.com/products/propwashsim/vid6606-4x-stepper-driver-board/) |  | $19.50 | $25.55
GT | 3 Digit 7-SEG Display | 1 | Digikey (https://www.digikey.ca/product-detail/en/kingbright/BA56-12GWA/754-1656-5-ND/3084327) |  | $7.24 |  | $7.24
GT | 5mm LED (white) | 4 | Elmwood (https://elmwoodelectronics.ca/products/100-led-assortment) |  | $0.09 |  | $0.36
GT | 24 LED driver board | 1 | Elmwood (https://elmwoodelectronics.ca/products/adafruit-24-channel-12-bit-pwm-led-driver-spi-interface) | Adafruit (https://www.adafruit.com/product/1429) | $20.99 |  | $20.99
GT | Magnet | 4 | Elmwood (https://elmwoodelectronics.ca/products/8890) |  | $1.99 |  | $7.96
GT | Gauge Tower - Front Panel | 1 | Metal Alloy Fabrication |  | $148.45 |  | $148.45
GT | Gauge Tower - Back Panel | 1 | Metal Alloy Fabrication |  | $70.51 |  | $70.51
GT | Gauge Tower - Acrylic Panel | 1 | Metal Alloy Fabrication |  | $75.51 |  | $75.51
All | Analog Gauge - Needle | 12 |  | Shapeways |  | $5.30 | $83.32
All | Computer-Arduino Cable (Standard USB A-B) | 1 |  |  |  |  | $0.00
All | AC-DC Wall Plug Converter/Power Supply | 1 | Digikey (https://www.digikey.ca/product-detail/en/globtek-inc/WR9HE3000CCP-F(R6B)/1939-1464-ND/8598267) |  | $23.09 |  | $23.09 | 120Vac > 12Vdc, 3A
All | Hookup Wire (22AWG, solid core) | 1 | Elmwood (https://elmwoodelectronics.ca/products/11367) |  | $25.99 |  | $25.99
All | Hookup Wire (22AWG, solid core) | 2 | Digikey (https://www.digikey.ca/en/products/detail/sparkfun-electronics/PRT-11367/5956251) |  | $22.57 |  | $45.14
All | Connectors (large single row) | 3 | Elmwood (https://elmwoodelectronics.ca/products/large-single-row-housing-pack-for-diy-jumper-cables) | Adafruit (https://www.adafruit.com/product/3146) | $4.99 |  | $14.97
All | Connectors (small double row) | 3 | Elmwood (https://elmwoodelectronics.ca/products/small-dual-row-wire-housing-pack-for-diy-jumper-cables) | Adafruit (https://www.adafruit.com/product/3143) | $3.99 |  | $11.97
All | Connectors (large double row) | 2 | Elmwood (https://elmwoodelectronics.ca/products/large-dual-row-wire-housing-pack-for-diy-jumper-cables) | Adafruit (https://www.adafruit.com/product/3144) | $5.99 |  | $11.98
All | Ribbon Cable (10 wire, 15ft, 28AWG) | 2 | Elmwood (https://elmwoodelectronics.ca/products/10647) | Sparkfun | $7.99 |  | $15.98
All | Ribbon Cable (6 wire, 15ft, 28AWG) | 2 | Elmwood (https://elmwoodelectronics.ca/products/10646) | Sparkfun | $4.99 |  | $9.98
All | Raw Male-Female Jumper Wires | 8 | Elmwood (https://elmwoodelectronics.ca/products/premium-male-female-raw-jumper-wires-40-x-6) |  | $4.99 |  | $39.92
All | Stranded Wire: 24 AWG, Red,Black,Green | 4 |  | Pololu (https://www.pololu.com/account/view_salesorder/1J335359?s=fa90adff) |  | $4.75 | $24.89
All | Stranded Wire: 24 AWG, Blue,White,Yellow | 3 |  |  |  | $5.75 | $22.60
All | Male Crimp Pins (x100) | 6 |  | Pololu (https://www.pololu.com/product/1931) |  | $7.95 | $62.49
All | Female Crimp Pins (x100) | 6 |  | Pololu (https://www.pololu.com/product/1930) |  | $5.95 | $46.77
All | 1x4 Crimp Connector Housing (x10) | 6 |  | Pololu |  | $0.59 | $4.64
All | 1x1 Crimp Connector Housing (x25) | 10 |  | Pololu |  | $0.53 | $6.94
All | 1x2 Crimp Connector Housing (x25) | 2 |  | Pololu |  | $0.69 | $1.81
All | Crimping Tool | 1 |  | Pololu (https://www.pololu.com/product/1929) |  | $29.95 | $39.23
All | 3x8 Female Header | 2 |  | Pololu |  | $1.49 | $3.90
All | Female/Male Headers | 1 | Amazon |  | $23.86 |  | $23.86
All | Wire Strippers | 1 | Amazon |  | $11.74 |  | $11.74
All | Paint (matte grey) | 2 | Home Depot |  | $10.05 |  | $20.09
All | Paint (frosted glass) | 1 | Home Depot |  | $12.29 |  | $12.29
All | Short Column | 2 | Metal Alloy Fabrication |  | $43.00 |  | $86.00
All | Long Column | 1 | Metal Alloy Fabrication |  | $77.02 |  | $77.02
All | Casing - Top Plate | 1 | Metal Alloy Fabrication |  | $210.56 |  | $210.56
All | Casing - Mounting Plate | 1 | Metal Alloy Fabrication |  | $144.26 |  | $144.26
All | Casing - Dodge Plate | 1 | Metal Alloy Fabrication |  | $94.92 |  | $94.92
All | Casing - Bottom Plate | 1 | Metal Alloy Fabrication |  | $142.76 |  | $142.76
All | Casing - Back Plate | 1 | Metal Alloy Fabrication |  | $67.12 |  | $67.12
All | Analog Gauge - Screen | 12 | Metal Alloy Fabrication |  | $7.17 |  | $86.06
Ship | Tindie | 1 |  |  |  | $22.00 | $28.82 | (Ship+Tax)
Ship | Pololu | 1 |  | Pololu |  | $58.31 | $76.39 | (Ship+Tax)
Ship | Fastenal | 1 |  |  | $171.46 |  | $171.46 | (Ship+Tax+Parts)
Ship | Elmwood | 1 |  |  | $26.55 |  | $26.55 | (Ship+Tax)
Ship | Adafruit (2020-10-31) | 1 |  |  |  | $21.40 | $28.03
Ship | Sparkfun (2020-10-31) | 1 |  |  |  | $5.42 | $7.10 | (Ship+Tax)
Ship | Digikey (2021-05-17) | 1 |  |  | $9.00 |  | $9.00
Ship | Shapeways (2021-05-09) | 0 |  |  |  | $14.99 | $0.00 | (Promo code waived shipping)
Ship | Digikey (2021-11-17) | 1 |  |  | $10.26 |  | $10.26
Ship | Pololu (2021-11-23) | 1 |  |  | $53.20 |  | $53.20
Misc | Fusion 360 Subscription | 1 |  |  | $89.60 |  | $89.60
Misc | 3D Printing | 1 |  |  | $100.00 |  | $100.00
Misc | Analog Gauge Backgrounds - Printing | 1 |  |  | $5.60 |  | $5.60
Misc | Stickers - Printing | 1 |  |  | $16.80 |  | $16.80
Misc | Home Depot - Paint, Brushes, Filler | 1 |  |  | $60.05 |  | $60.05
Misc | Filler spray paint | 1 | Home Depot |  | $15.00 |  | $15.00
Misc | Fast Drying Urethane Spray Paint (3D printing smoothing agent) | 1 | Lowes |  | $16.26 |  | $16.26
 |  |  |  |  |  |  | $3978.22
1.31 | Exchange Rate (1 USD = X CAD)

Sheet: Fasteners
 |  |  |  |  |  |  |  |  | mm |  |  | Inches
Description | SKU | Head | Price/100 | Min # | Quantity | Cost | Thread | Head Angle | A | B | C | A2 | B2 | C2
Fastenal:
Stepper gauge assembly screw (https://www.fastenal.com/products/details/24160) | 24160 |  | 4.88 | 48 | 100 | 4.88 | #3-48 | 80-84° | 5.05 | 2.51 | 15.88 | 0.199 | 0.099 | 0.625
Stepper gauge assembly nut (https://www.fastenal.com/products/details/36008) | 36008 |  | 8.12 | 48 | 100 | 8.12 | #3-48 |  | - | 4.57 | 1.68 | - | 0.18 | 0.066
Stepper motor mounting screw (https://www.fastenal.com/products/details/0170305) | 0170305 |  | 54.99 | 22 | 35 | 19.25 | #0-80 | flat | 2.87 | 1.35 | 19.05 | 0.113 | 0.053 | 0.75
NEMA17 motor mounting screw (https://www.fastenal.com/products/details/XM2510010A20000) | XM2510010A20000 |  | 6.42 | 4 | 6 | 0.39 | M3x0.5 | 90-92° | 5.50 |  | 10.00
Standoff (https://www.fastenal.com/products/details/0145976) | 0145976 |  | 34 | 38 | 60 | 20.40 | #4-40 |  | 4.76 | - | 12.70 | 0.1875 | - | 0.5
Standoff top screw (https://www.fastenal.com/products/details/83041) | 83041 |  | 4.46 | 38 | 100 | 4.46 | #4-40 | flat | 4.65 |  | 4.76 | 0.183 |  | 0.1875
Standoff under screw (https://www.fastenal.com/products/details/29375) | 29375 |  | 4.23 | 38 | 100 | 4.23 | #4-40 | 80-82° | 5.38 |  | 9.65 | 0.212 |  | 0.38
Shipping + Tax |  |  |  |  |  | 9.18
Fastenal:
Handle Screw (https://www.fastenal.ca/sku/29446) | 29446 | Cross | 7 | 2 | 40 | 2.80 | #8-32 | 80-82° |  |  | 25.40 |  |  | 1
Throttle threaded rod (https://www.fastenal.ca/sku/47057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) | 47057 |  | 299 | 1 | 1 | 2.99 | 1/4"-20 |  |  | 6.35 | 3 ft |  | 0.25
1/4" Jam Nut (https://www.fastenal.ca/sku/36201?attributeName_0=Dia%2FThread+Size&attributeValue_0=1%2F4%22-20) | 36201 |  | 7 | 8 | 30 | 2.10 | 1/4"-20 |  |  |  | 3.96 |  |  | 0.156
1/4" Washer (https://www.fastenal.ca/sku/33078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) | 33078 |  | 6 | 12 | 30 | 1.80 | 1/4"
Cable tie mount screw (https://www.fastenal.ca/sku/91185?attributeName_0=Head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) | 91185 | Cross | 8 | 16 | 50 | 4.00 | M3x0.5 | flat |  |  | 4
#8-32 Nut (https://www.fastenal.ca/sku/0148194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) | 0148194 |  | 6 | 37 | 100 | 6.00 | #8-32 |  |  |  | 3.30 |  |  | 0.13
"Bracket" Screw (1/4") (https://www.fastenal.ca/sku/72640?attributeName_0=Length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) | 72640 | Cross | 6 | 37 | 100 | 6.00 | #8-32 | 80-82° |  |  | 6.35 |  |  | 0.25
"Bracket" Screw (5/16") (https://www.fastenal.ca/sku/72637?attributeName_0=Length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) | 72637 | Cross | 6 | 37 | 100 | 6.00 | #8-32 | 80-82° |  |  | 7.94 |  |  | 0.31
Plate-plate assembly screw (https://www.fastenal.ca/sku/91285?attributeName_0=Length&attributeValue_0=6mm&showAll=__Dia%2FThread+Size__) | 91285 | Cross | 2 | 60 | 150 | 3.00 | M3x0.5 | 90-92° |  |  | 6.00
Long M3 Screw (https://www.fastenal.ca/sku/XM2510016A20000?attributeName_0=Length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) | XM2510016A20000 | Cross | 6 | 18 | 100 | 6.00 | M3x0.5 | 90-92° |  |  | 16
M3 Nut (https://www.fastenal.ca/sku/MN2510000A40000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) | MN2510000A40000 |  | 3 | 4 | 100 | 3.00 | M3x0.5 |  |  |  | 2.4
Shipping + Tax |  |  |  |  |  | 5.48
Digikey:
Zip tie mount (https://www.digikey.ca/product-detail/en/phoenix-contact/3240703/277-16294-ND/4461928) | n/a |  | 9.69 | 15 | 100 | 9.69
611 Right Angle Bracket (https://www.digikey.ca/product-detail/en/keystone-electronics/611/36-611-ND/631427) |  |  | 50.08 | 35 | 50 | 25.04 | #8-32
Shipping + Tax |  |  |  |  |  | 16.66
Total (USD) |  |  |  |  |  | 171.46
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

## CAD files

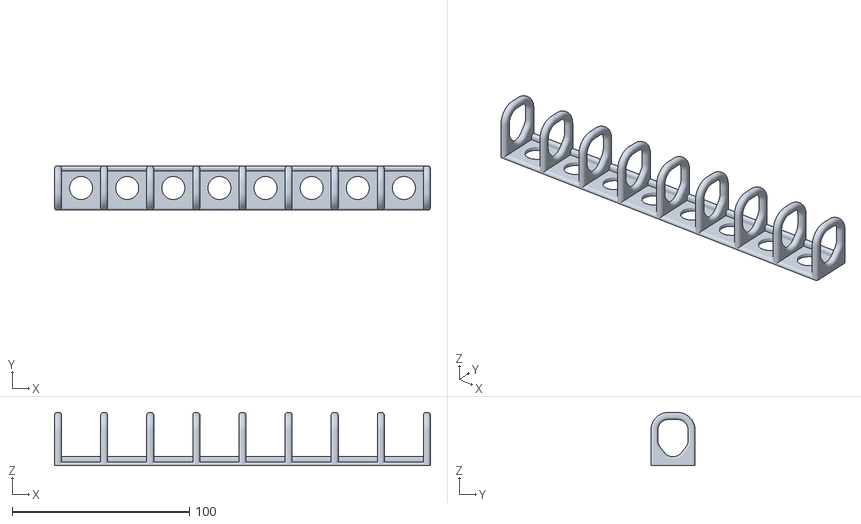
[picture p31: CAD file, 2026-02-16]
KCP2-physical/3DPrint/2020-02-05/Switch Guard - 8 v2.stl
212.0 x 25.0 x 30.0

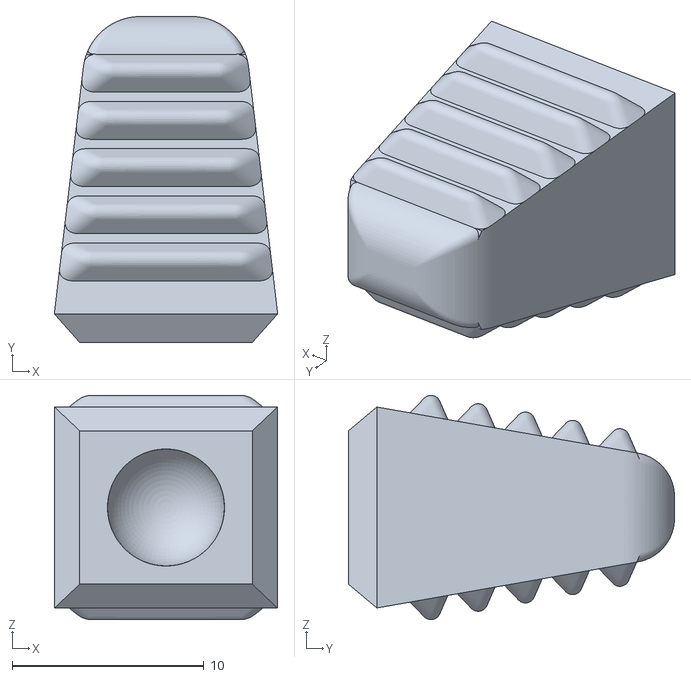
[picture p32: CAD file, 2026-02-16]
KCP2-physical/3DPrint/2020-02-06/Switch Tip (M).stl
11.6 x 17.0 x 11.7

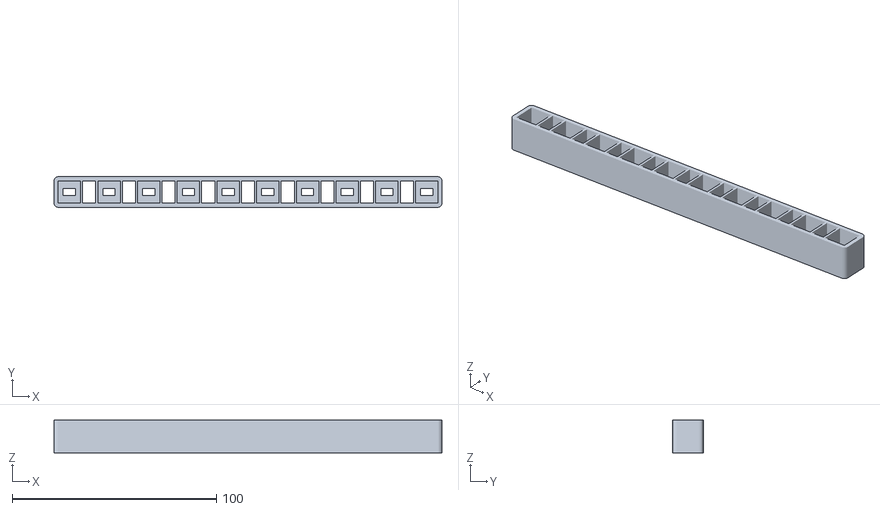
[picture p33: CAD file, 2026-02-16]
KCP2-physical/3DPrint/2020-03-28/SASLightbox_v4.stl
190.0 x 15.0 x 16.0

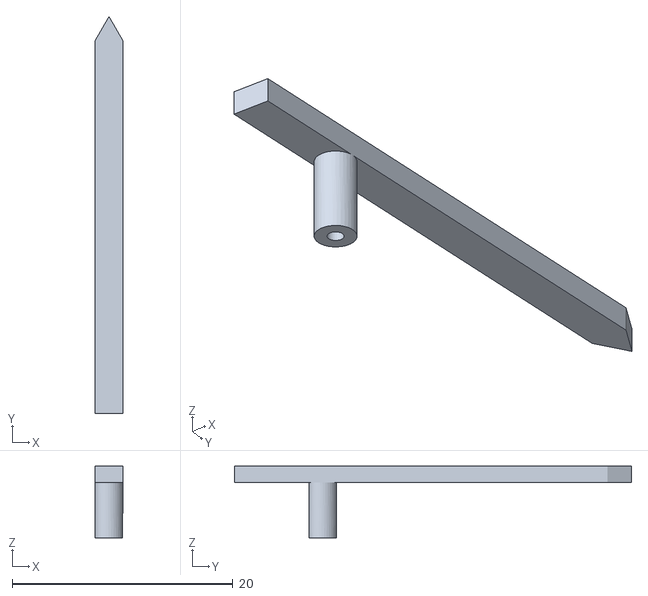
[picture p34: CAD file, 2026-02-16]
KCP2-physical/3DPrint/2020-10-25/CustomNeedle_v6_Proto3.stl
2.50 x 36.0 x 6.50

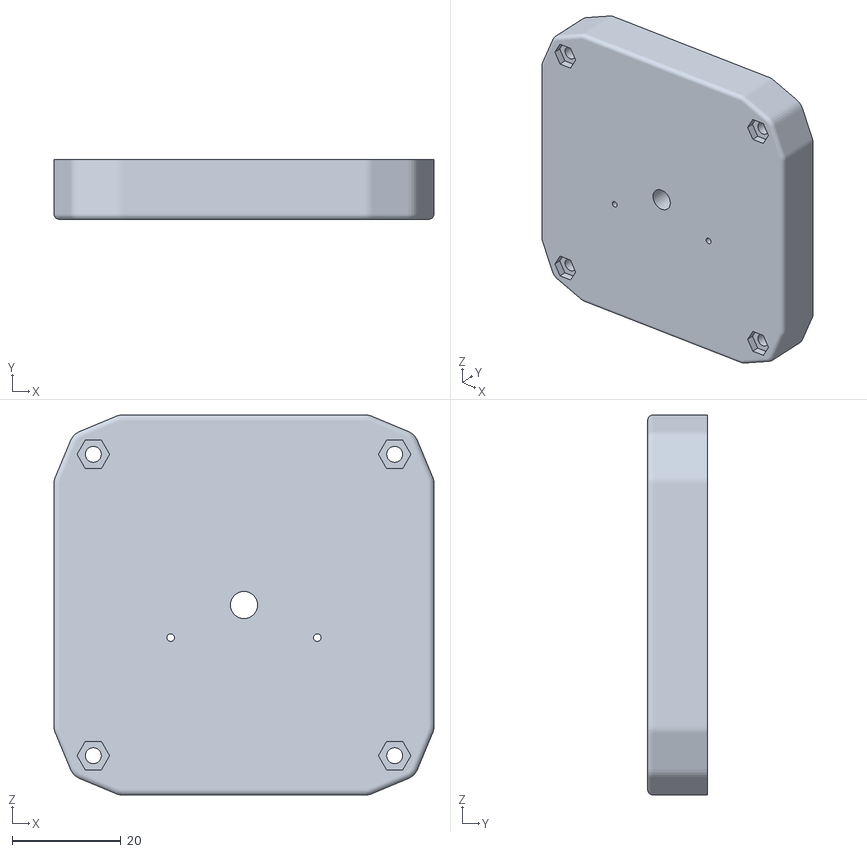
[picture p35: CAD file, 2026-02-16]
KCP2-physical/3DPrint/2020-10-26/AnalogGaugeCluster_v13-Adapter.stl
70.0 x 11.0 x 70.0

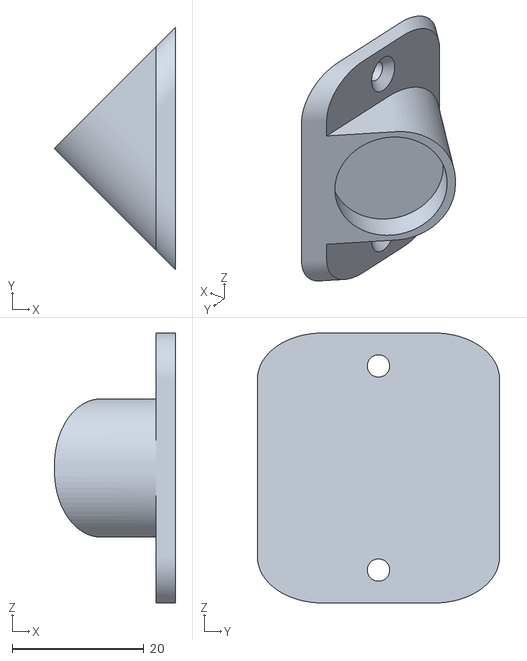
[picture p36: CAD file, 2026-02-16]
KCP2-physical/3DPrint/2020-11-01/GaugeTowerAdapter_v6.stl
18.4 x 36.8 x 41.0

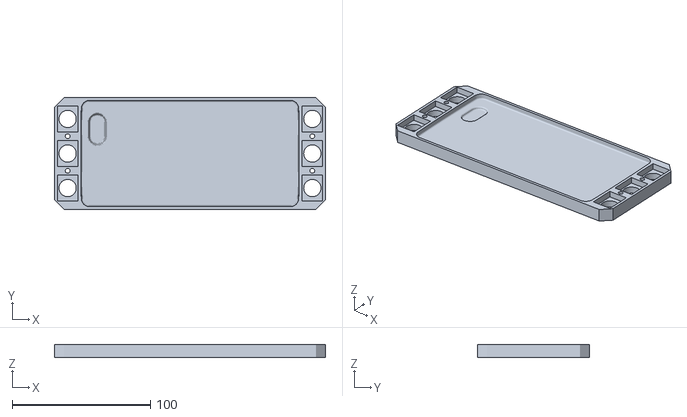
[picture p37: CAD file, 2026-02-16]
KCP2-physical/3DPrint/2020-11-12/PhoneAdapter_v22.stl
196.0 x 81.0 x 9.50

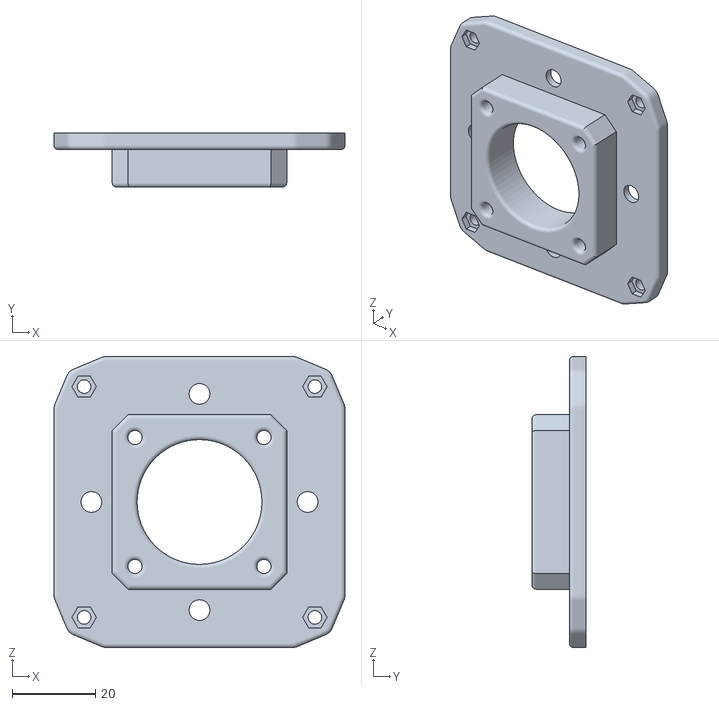
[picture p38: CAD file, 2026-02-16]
KCP2-physical/3DPrint/2020-11-14/HeadingGaugeAdapter_v7.stl
70.0 x 13.0 x 70.0

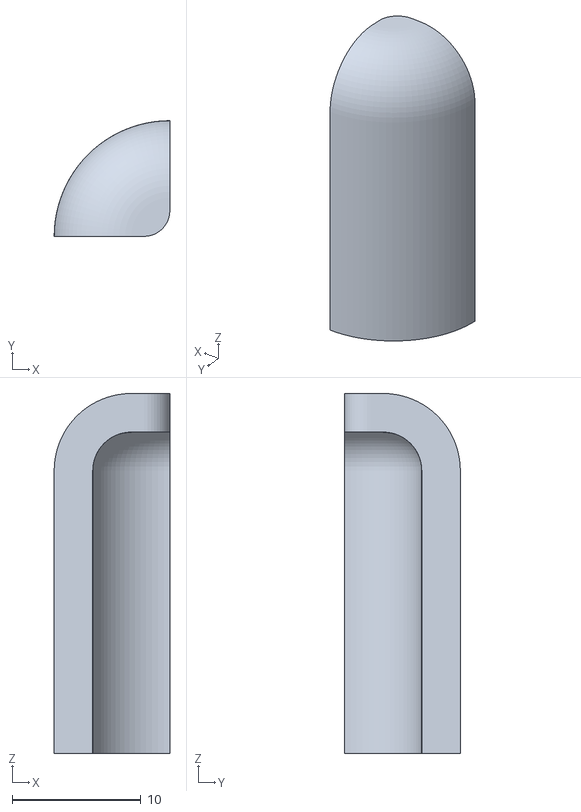
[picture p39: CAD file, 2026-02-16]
KCP2-physical/3DPrint/2020-12-15/Corner_v2.stl
9.00 x 9.00 x 28.0

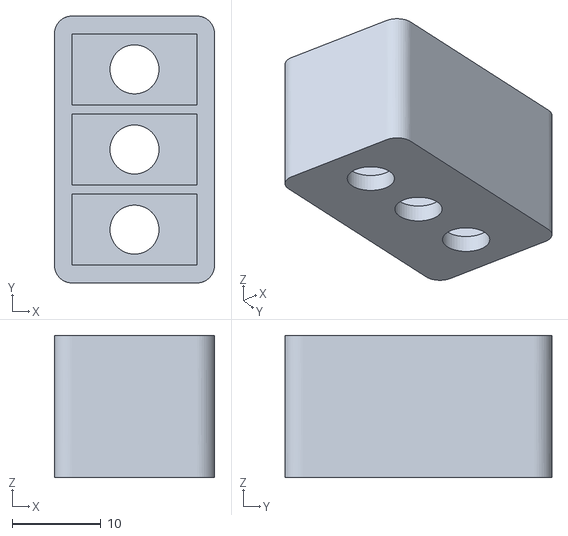
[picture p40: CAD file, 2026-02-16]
KCP2-physical/3DPrint/2021-01-11/2x_Lightbox3POSWide_v2.stl
18.0 x 30.0 x 16.0

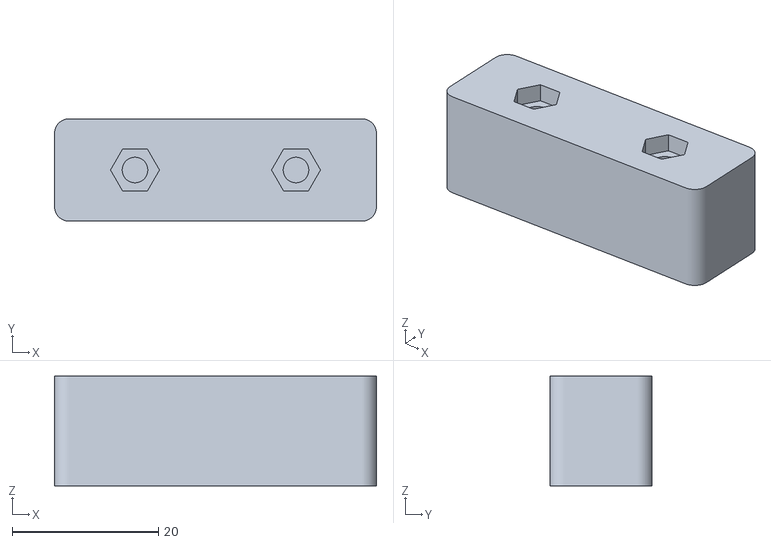
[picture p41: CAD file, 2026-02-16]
KCP2-physical/3DPrint/TBD/4xKeyboardPillar.stl
44.0 x 14.0 x 15.0

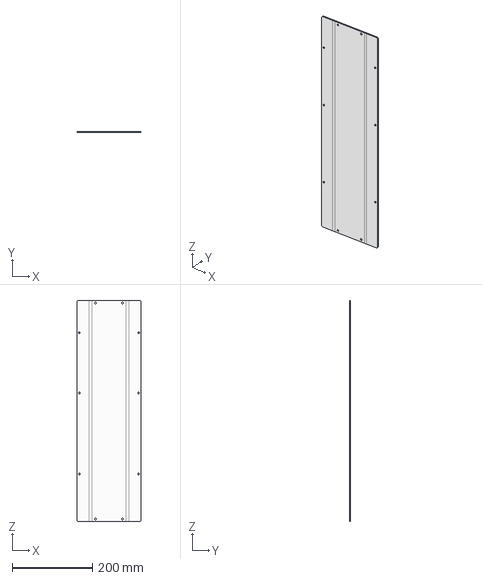
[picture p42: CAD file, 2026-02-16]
KCP2-physical/CAD/ForManufacture/Aluminum/Gauge Tower Back Panel/GaugeTower_BackPanel_v20_FlatPattern.step
160.6 x 3.00 x 551.0 mm

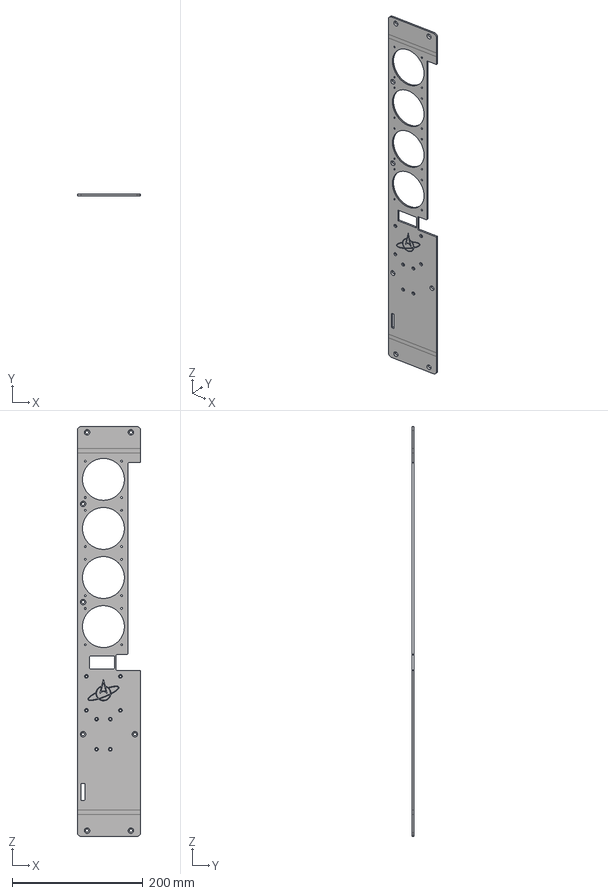
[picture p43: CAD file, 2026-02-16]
KCP2-physical/CAD/ForManufacture/Aluminum/Gauge Tower Front Panel/GaugeTower_FrontPanel_v21_FlatPattern.step
97.0 x 3.02 x 626.6 mm

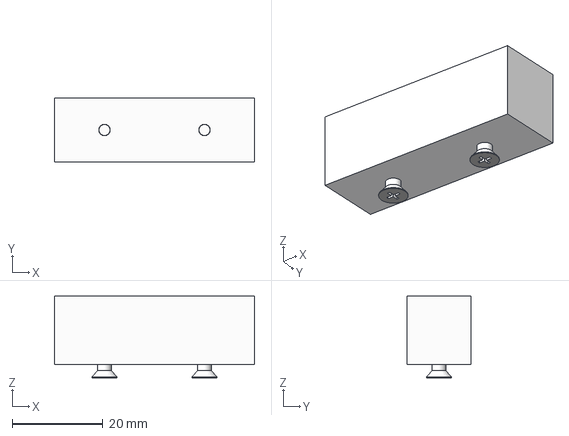
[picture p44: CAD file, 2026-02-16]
KCP2-physical/CAD/ForManufacture/Aluminum/Keyboard Pillar/KeyboardPillar_v91.step
44.0 x 14.0 x 18.0 mm
M3x16mm Screw x 2

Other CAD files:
KCP2-physical/CAD/ForManufacture/Aluminum/Long Column/LongColumn_v91.step
KCP2-physical/CAD/ForManufacture/Aluminum/Panel Dodge Plate/Panel_DodgePlate_v95_Folded.step
KCP2-physical/CAD/ForManufacture/Aluminum/Panel Mounting Plate/Panel_MountingPlate_v96_FlatPattern.step
KCP2-physical/CAD/ForManufacture/Aluminum/Panel Top Plate/Panel_TopPlate_v96.dxf
KCP2-physical/3DPrint/2020-02-05/Switch Guard - 3 v5.stl
KCP2-physical/3DPrint/2020-02-05/Switch Guard - 7 v3.stl
KCP2-physical/3DPrint/2020-02-05/Switch Guard - Single v3.stl
KCP2-physical/3DPrint/2020-02-06/Switch Tip (L).stl
KCP2-physical/3DPrint/2020-02-06/Switch Tip (S).stl
KCP2-physical/3DPrint/2020-02-06/v2_AnalogGaugeAdapter.stl
KCP2-physical/3DPrint/2020-02-06/v2_Handle_3.9mmHole_OldWas3.5mm.stl
KCP2-physical/3DPrint/2020-02-06/v2_HeadingGaugeAdapter.stl
KCP2-physical/3DPrint/2020-02-06/v2_HeadingGaugeBackplate.stl
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

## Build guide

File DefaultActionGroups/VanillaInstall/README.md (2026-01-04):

# DefaultActionGroups
KSP mod for setting default action groups for parts (e.g. cockpit lights in Light group)

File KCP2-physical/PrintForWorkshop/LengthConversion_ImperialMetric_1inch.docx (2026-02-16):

| 16ths | 32nds | 64ths | SAE Decimal | Millimeters
| | | 1/64 | .016 | 0.397
| | 1/32 | | .031 | 0.794
| | | 3/64 | .047 | 1.191
| 1/16 | | | .062 | 1.588
| | | 5/64 | .078 | 1.984
| | 3/32 | | .094 | 2.381
| | | 7/64 | .109 | 2.778
1/8 | | | | .125 | 3.175
| | | 9/64 | .141 | 3.572
| | 5/32 | | .156 | 3.969
| | | 11/64 | .172 | 4.366
| 3/16 | | | .188 | 4.763
| | | 13/64 | .203 | 5.159
| | 7/32 | | .219 | 5.556
| | | 15/64 | .234 | 5.953
1/4 | | | | .250 | 6.350
| | | 17/64 | .266 | 6.747
| | 9/32 | | .281 | 7.144
| | | 19/64 | .297 | 7.541
| 5/16 | | | .312 | 7.938
| | | 21/64 | .328 | 8.334
| | 11/32 | | .344 | 8.731
| | | 23/64 | .359 | 9.128
3/8 | | | | .375 | 9.525
| | | 25/64 | .391 | 9.922
| | 13/32 | | .406 | 10.319
| | | 27/64 | .422 | 10.716
| 7/16 | | | .438 | 11.113
| | | 29/64 | .453 | 11.509
| | 15/32 | | .469 | 11.906
| | | 31/64 | .484 | 12.303
1/2 | | | | .500 | 12.700
| | | 33/64 | .516 | 13.097
| | 17/32 | | .531 | 13.494
| | | 35/64 | .547 | 13.891
| 9/16 | | | .562 | 14.288
| | | 37/64 | .578 | 14.684
| | 19/32 | | .594 | 15.081
| | | 39/64 | .609 | 15.478
5/8 | | | | .625 | 15.875
| | | 41/64 | .641 | 16.272
| | 21/32 | | .656 | 16.669
| | | 43/64 | .672 | 17.066
| 11/16 | | | .688 | 17.463
| | | 45/64 | .703 | 17.859
| | 23/32 | | .719 | 18.256
| | | 47/64 | .734 | 18.653
3/4 | | | | .750 | 19.050
| | | 49/64 | .766 | 19.447
| | 25/32 | | .781 | 19.844
| | | 51/64 | .797 | 20.241
| 13/16 | | | .812 | 20.638
| | | 53/64 | .828 | 21.034
| | 27/32 | | .844 | 21.431
| | | 55/64 | .859 | 21.828
7/8 | | | | .875 | 22.225
| | | 57/64 | .891 | 22.622
| | 29/32 | | .906 | 23.019
| | | 59/64 | .922 | 23.416
| 15/16 | | | .938 | 23.813
| | | 61/64 | .953 | 24.209
| | 31/32 | | .969 | 24.606
| | | 63/64 | .984 | 25.003
1 | | | | 1.000 | 25.400

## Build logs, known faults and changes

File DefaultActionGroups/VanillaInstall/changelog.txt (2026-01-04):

Version 1.4  (2021-06-27)
* Added feature to use NON-localized names of actions in config files (more stable & robust).
* Updated handling of ModuleAnimateGeneric. You can specify actionName as "ToggleAction" or as the value of animationName.
* The old system, based on localized action names, is deprecated but still works.
* Caveat: any usage with ModuleColorChanger needs to switch to the new, non-localized method.
* Updated most of the optional configs to use the new, non-localized config option.
* Update to ModuleManager 4.1.4.

Version 1.3  (2019-10-16)
* Update for KSP 1.8 compatibility.
* Includes update to ModuleManager 4.1.0.

Version 1.2.4  (2018-03-15)
* Update to ModuleManager 3.0.6 for KSP 1.4.1 compatibility
* Add optional config for "gather science" via action group Custom08.

Version 1.2.3  (2017-05-29)
* Fix optional config for solar panels to handle recent Kopernicus update. (Thanks to Errol from KSP forums for catching!)

Version 1.2.2  (2017-05-28)
* Update to ModuleManager 2.8.0 for KSP 1.3 compatibility
* Update to target .NET 3.5, as a KSP mod is supposed to (it was targeting 4.5.2 before)

Version 1.2.1  (2016-12-01)
* Add optional config file for toggling deployable antennas via action group Custom03.
* Update to ModuleManager 2.7.5.

Version 1.2  (2016-10-11)
* Changed to CC-BY-NC-ND license (was previously MIT).
* Update for KSP 1.2.
* Update to ModuleManager 2.7.1 (required for compatibility with KSP 1.2).

Version 1.1.2  (2016-04-30)
* Update to ModuleManager 2.6.24 (required for compatibility with KSP 1.1.2)

Version 1.1.1  (2016-04-22)
* Update to newest ModuleManager version
* Add more optional config files to do various things

Version 1.1  (2016-03-31)
* Required update for KSP 1.1. Older versions of BetterBurnTime won't work on 1.1.
* No new features; this is a compatibility update only.

----- Everything above this line will run ONLY on KSP 1.1 and newer -----

----- Everything below this line will run ONLY on KSP 1.0.5 and older -----

Version 1.0  (2015-11-18)
* Initial release.

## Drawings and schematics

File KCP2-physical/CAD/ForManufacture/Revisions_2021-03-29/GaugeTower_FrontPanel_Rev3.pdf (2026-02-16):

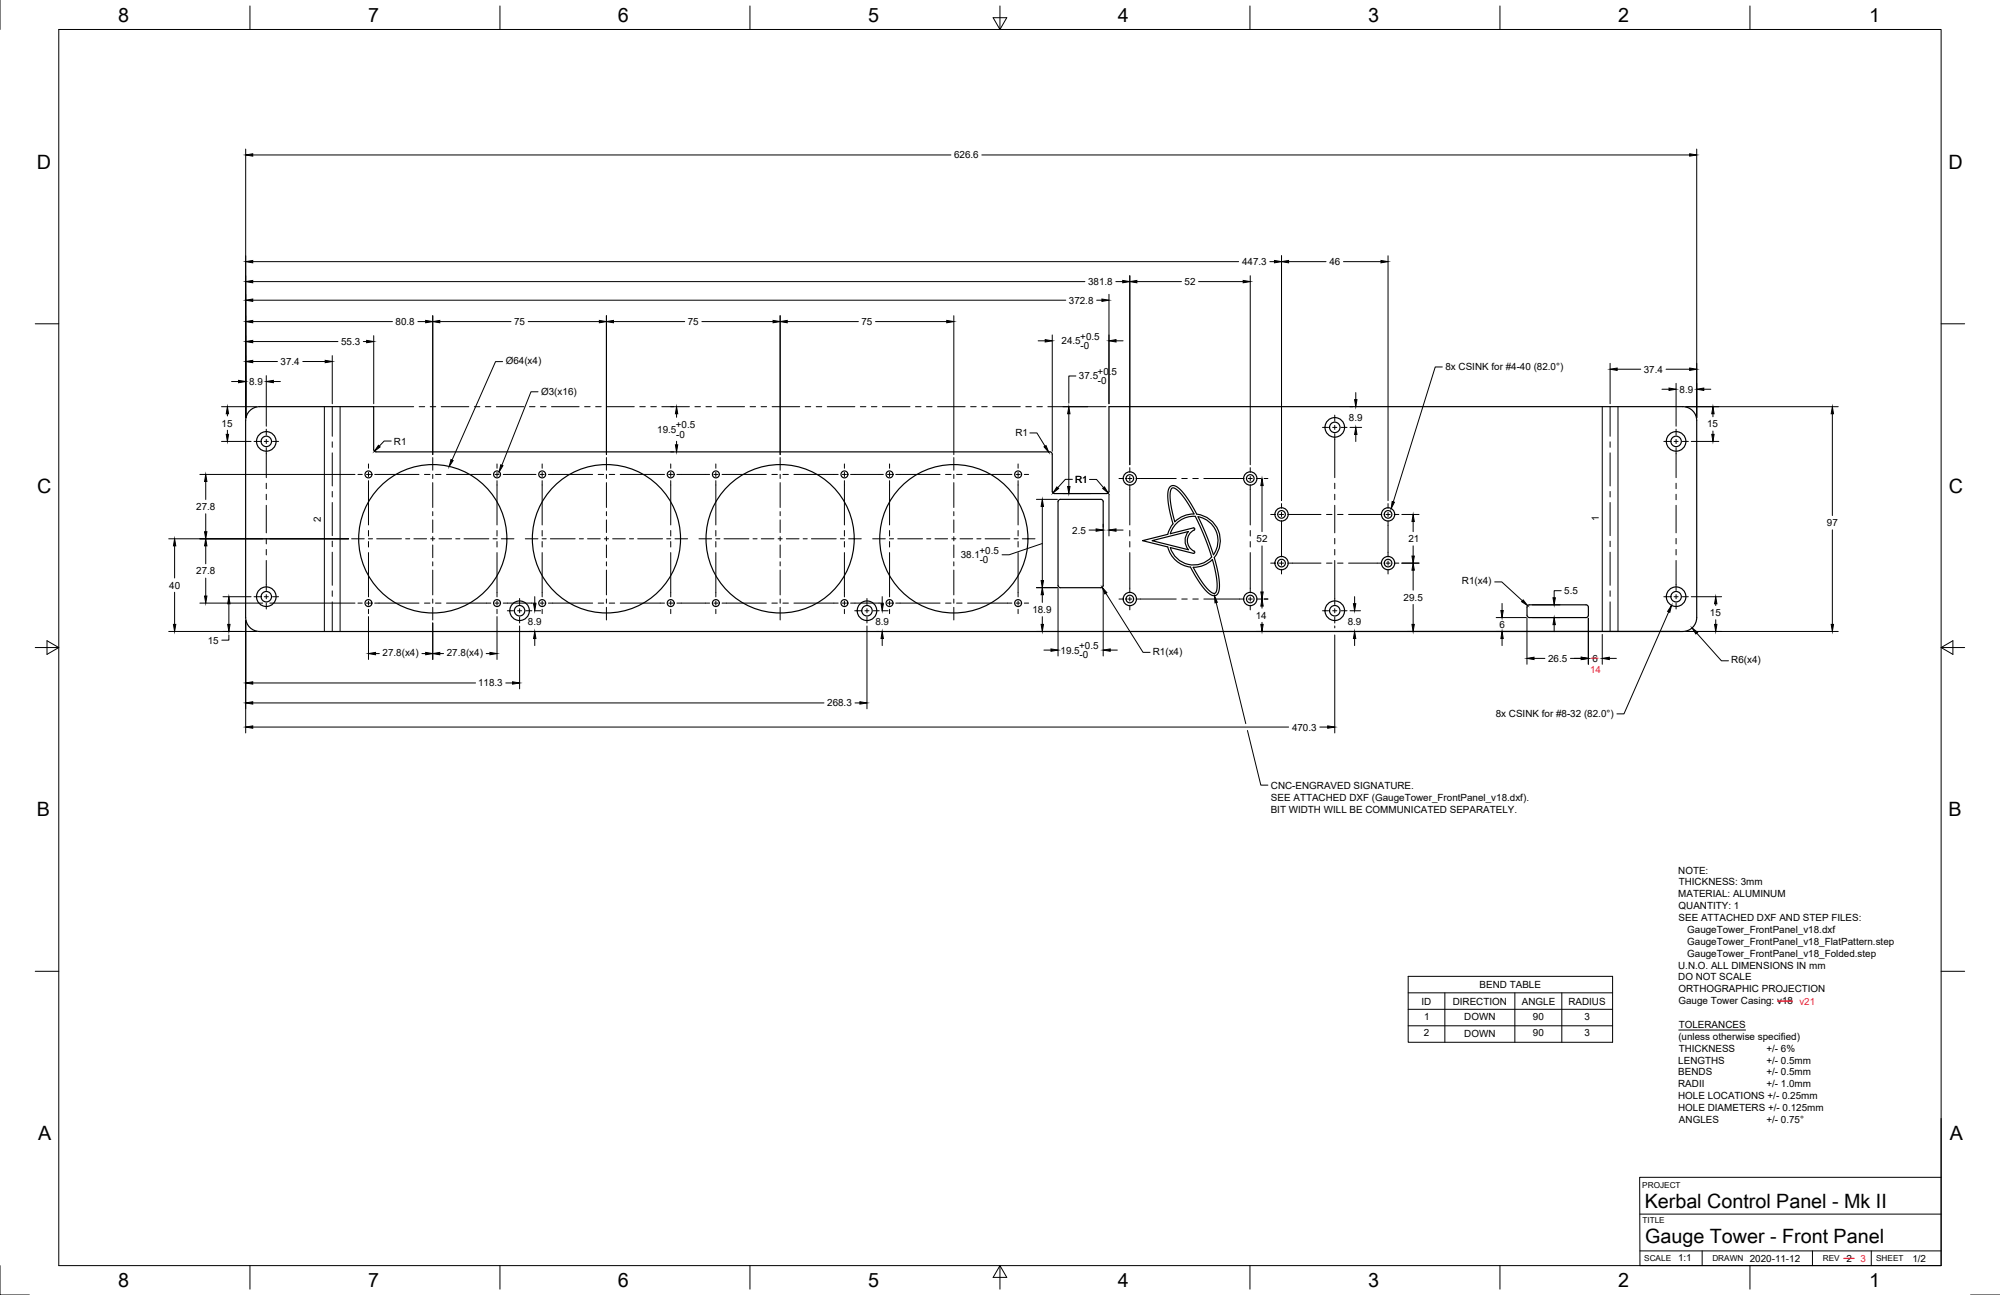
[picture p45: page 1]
SCALE 1:1; DRAWN 2020-11-12; REV 2; SHEET 1/2; BEND TABLE; THICKNESS; LENGTHS; BENDS; RADII; ANGLES; 8x CSINK for #4-40 (82.0°); 8x CSINK for #8-32 (82.0°)

CNC-ENGRAVED SIGNATURE.
SEE ATTACHED DXF (GaugeTower_FrontPanel_v18.dxf).
BIT WIDTH WILL BE COMMUNICATED SEPARATELY.

NOTE:
THICKNESS: 3mm
MATERIAL: ALUMINUM
QUANTITY: 1
SEE ATTACHED DXF AND STEP FILES:
GaugeTower_FrontPanel_v18.dxf
GaugeTower_FrontPanel_v18_FlatPattern.step
GaugeTower_FrontPanel_v18_Folded.step
U.N.O. ALL DIMENSIONS IN mm
DO NOT SCALE
ORTHOGRAPHIC PROJECTION
Gauge Tower Casing: v18

ID | DIRECTION | ANGLE | RADIUS
1 | DOWN | 90 | 3
2 | DOWN | 90 | 3

TOLERANCES
(unless otherwise specified)
HOLE LOCATIONS +/- 0.25mm
HOLE DIAMETERS +/- 0.125mm

PROJECT
Kerbal Control Panel - Mk II

TITLE
Gauge Tower - Front Panel

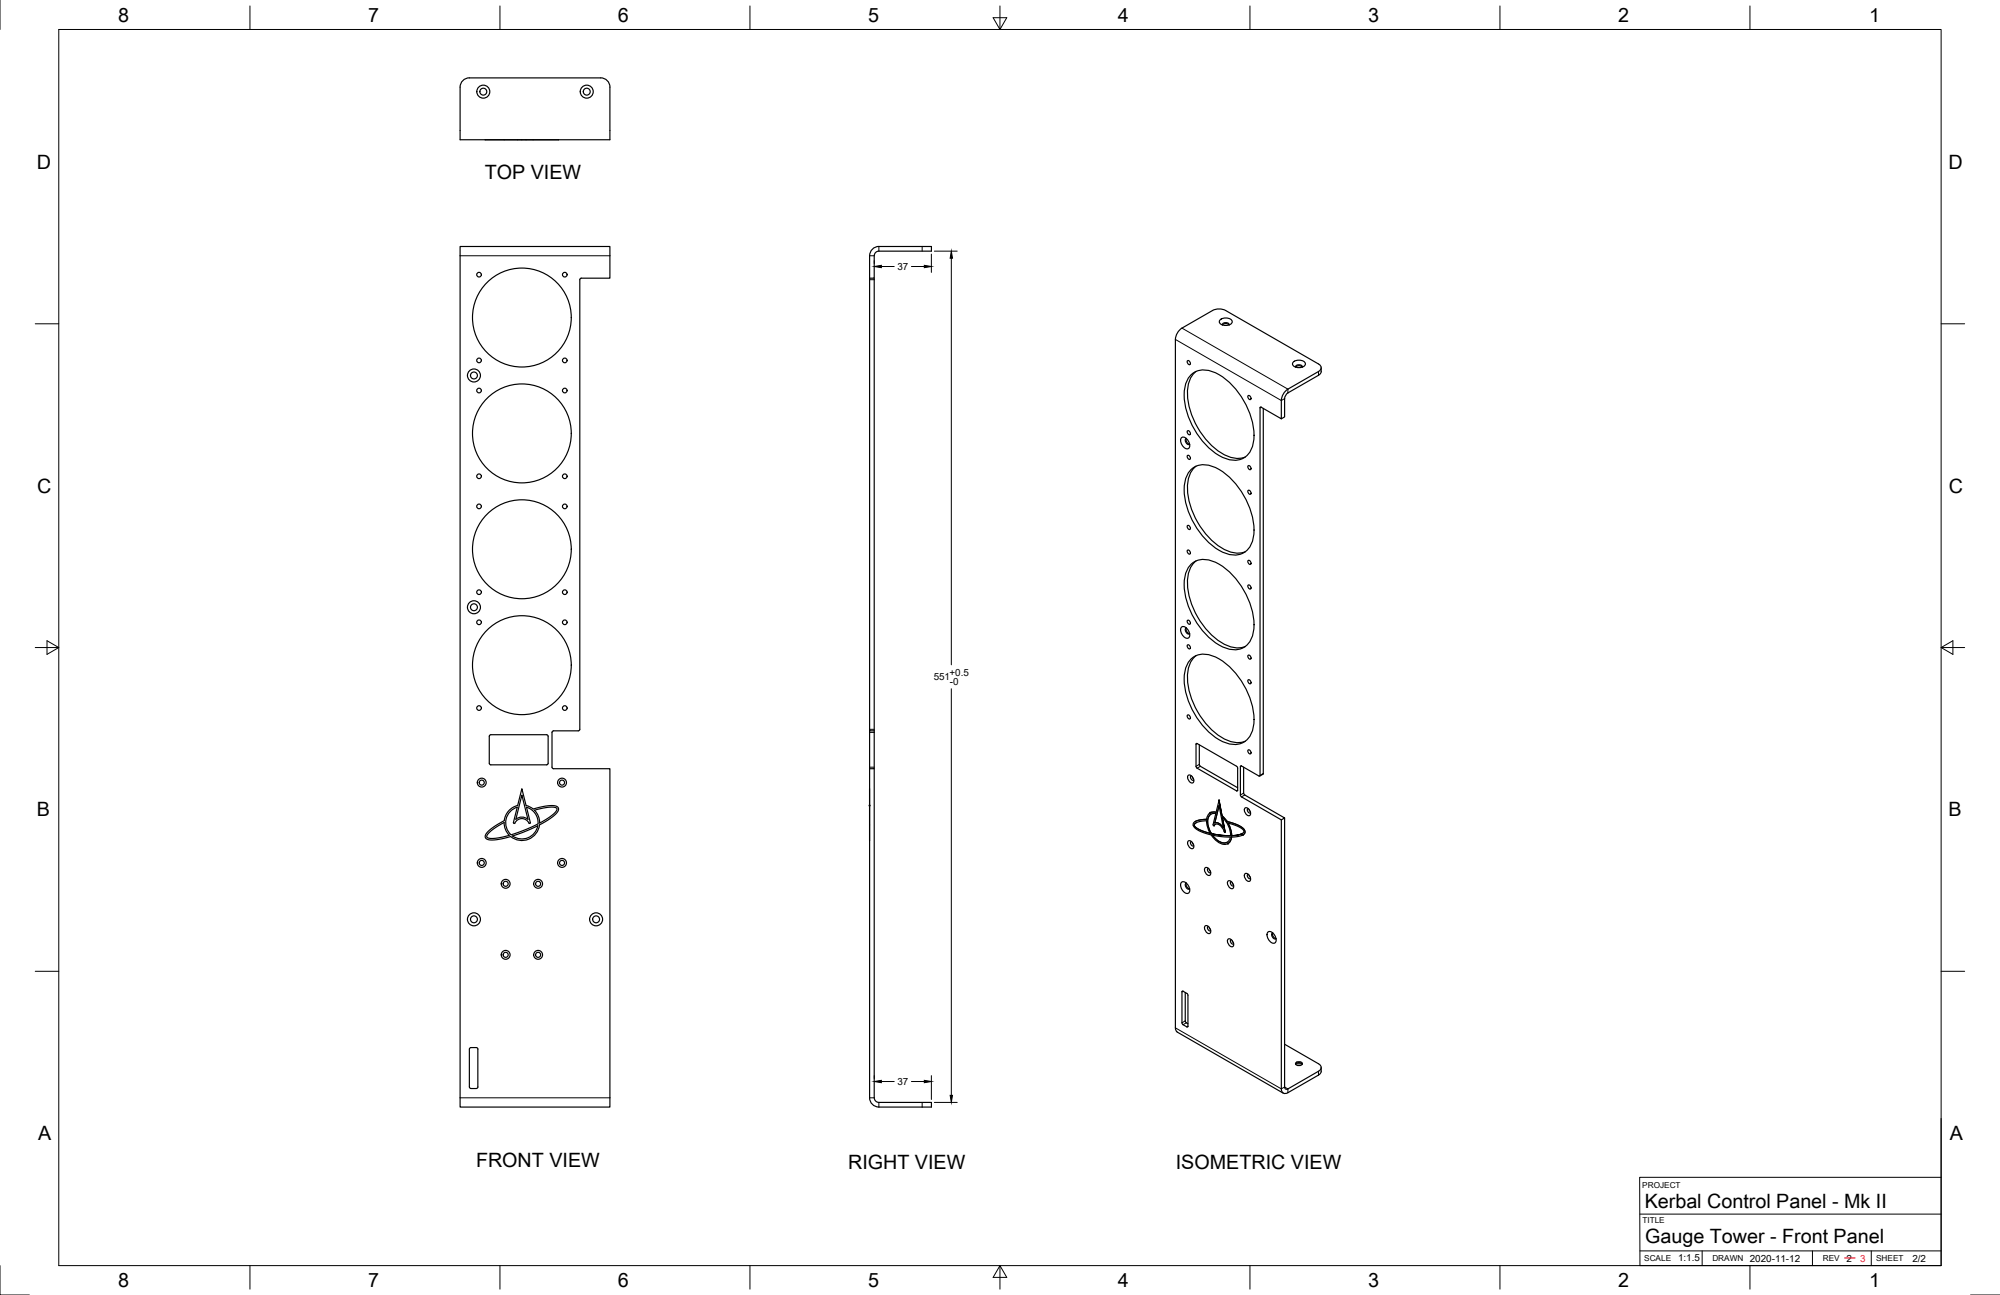
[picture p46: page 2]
SCALE 1:1.5; DRAWN 2020-11-12; REV 2; SHEET 2/2; FRONT VIEW; TOP VIEW; RIGHT VIEW; ISOMETRIC VIEW

PROJECT
Kerbal Control Panel - Mk II

TITLE
Gauge Tower - Front Panel

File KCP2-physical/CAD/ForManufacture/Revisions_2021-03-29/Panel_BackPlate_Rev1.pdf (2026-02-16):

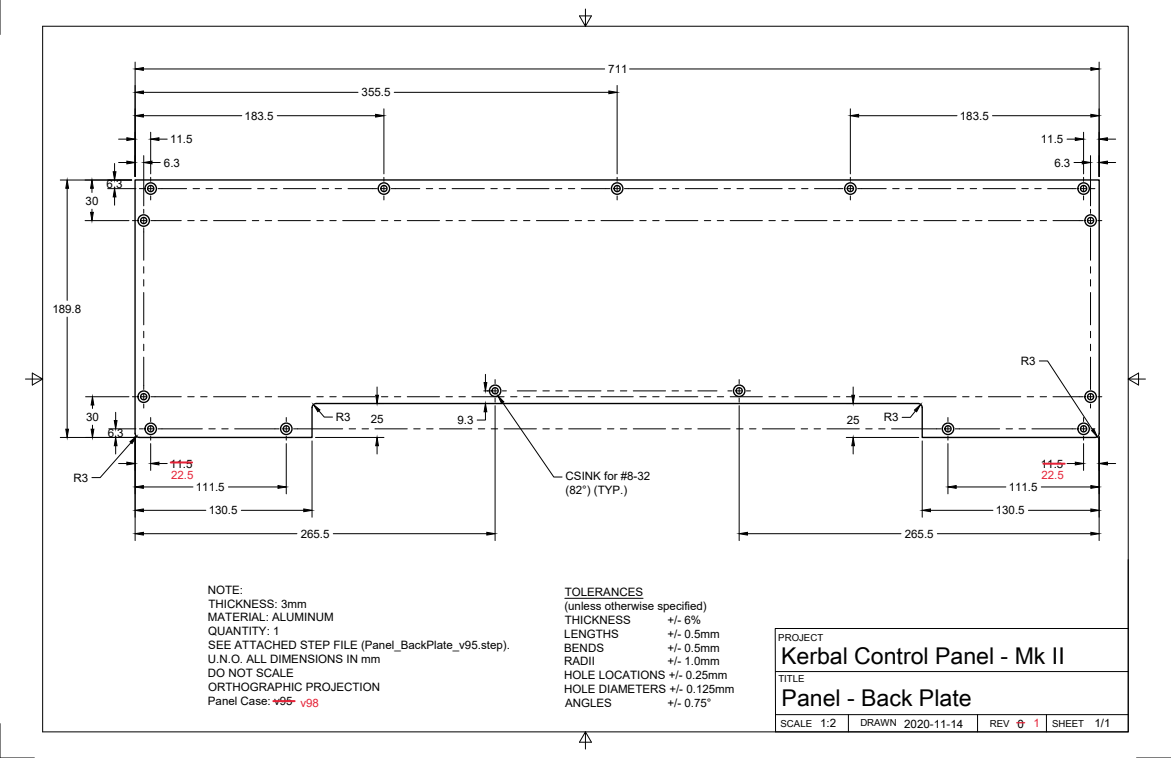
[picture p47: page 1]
SCALE 1:2; DRAWN 2020-11-14; REV 0; SHEET 1/1; THICKNESS; LENGTHS; BENDS; RADII; ANGLES; CSINK for #8-32 (82°) (TYP.)

NOTE:
THICKNESS: 3mm
MATERIAL: ALUMINUM
QUANTITY: 1
SEE ATTACHED STEP FILE (Panel_BackPlate_v95.step).
U.N.O. ALL DIMENSIONS IN mm
DO NOT SCALE
ORTHOGRAPHIC PROJECTION
Panel Case: v95

TOLERANCES
(unless otherwise specified)
HOLE LOCATIONS +/- 0.25mm
HOLE DIAMETERS +/- 0.125mm

PROJECT
Kerbal Control Panel - Mk II

TITLE
Panel - Back Plate

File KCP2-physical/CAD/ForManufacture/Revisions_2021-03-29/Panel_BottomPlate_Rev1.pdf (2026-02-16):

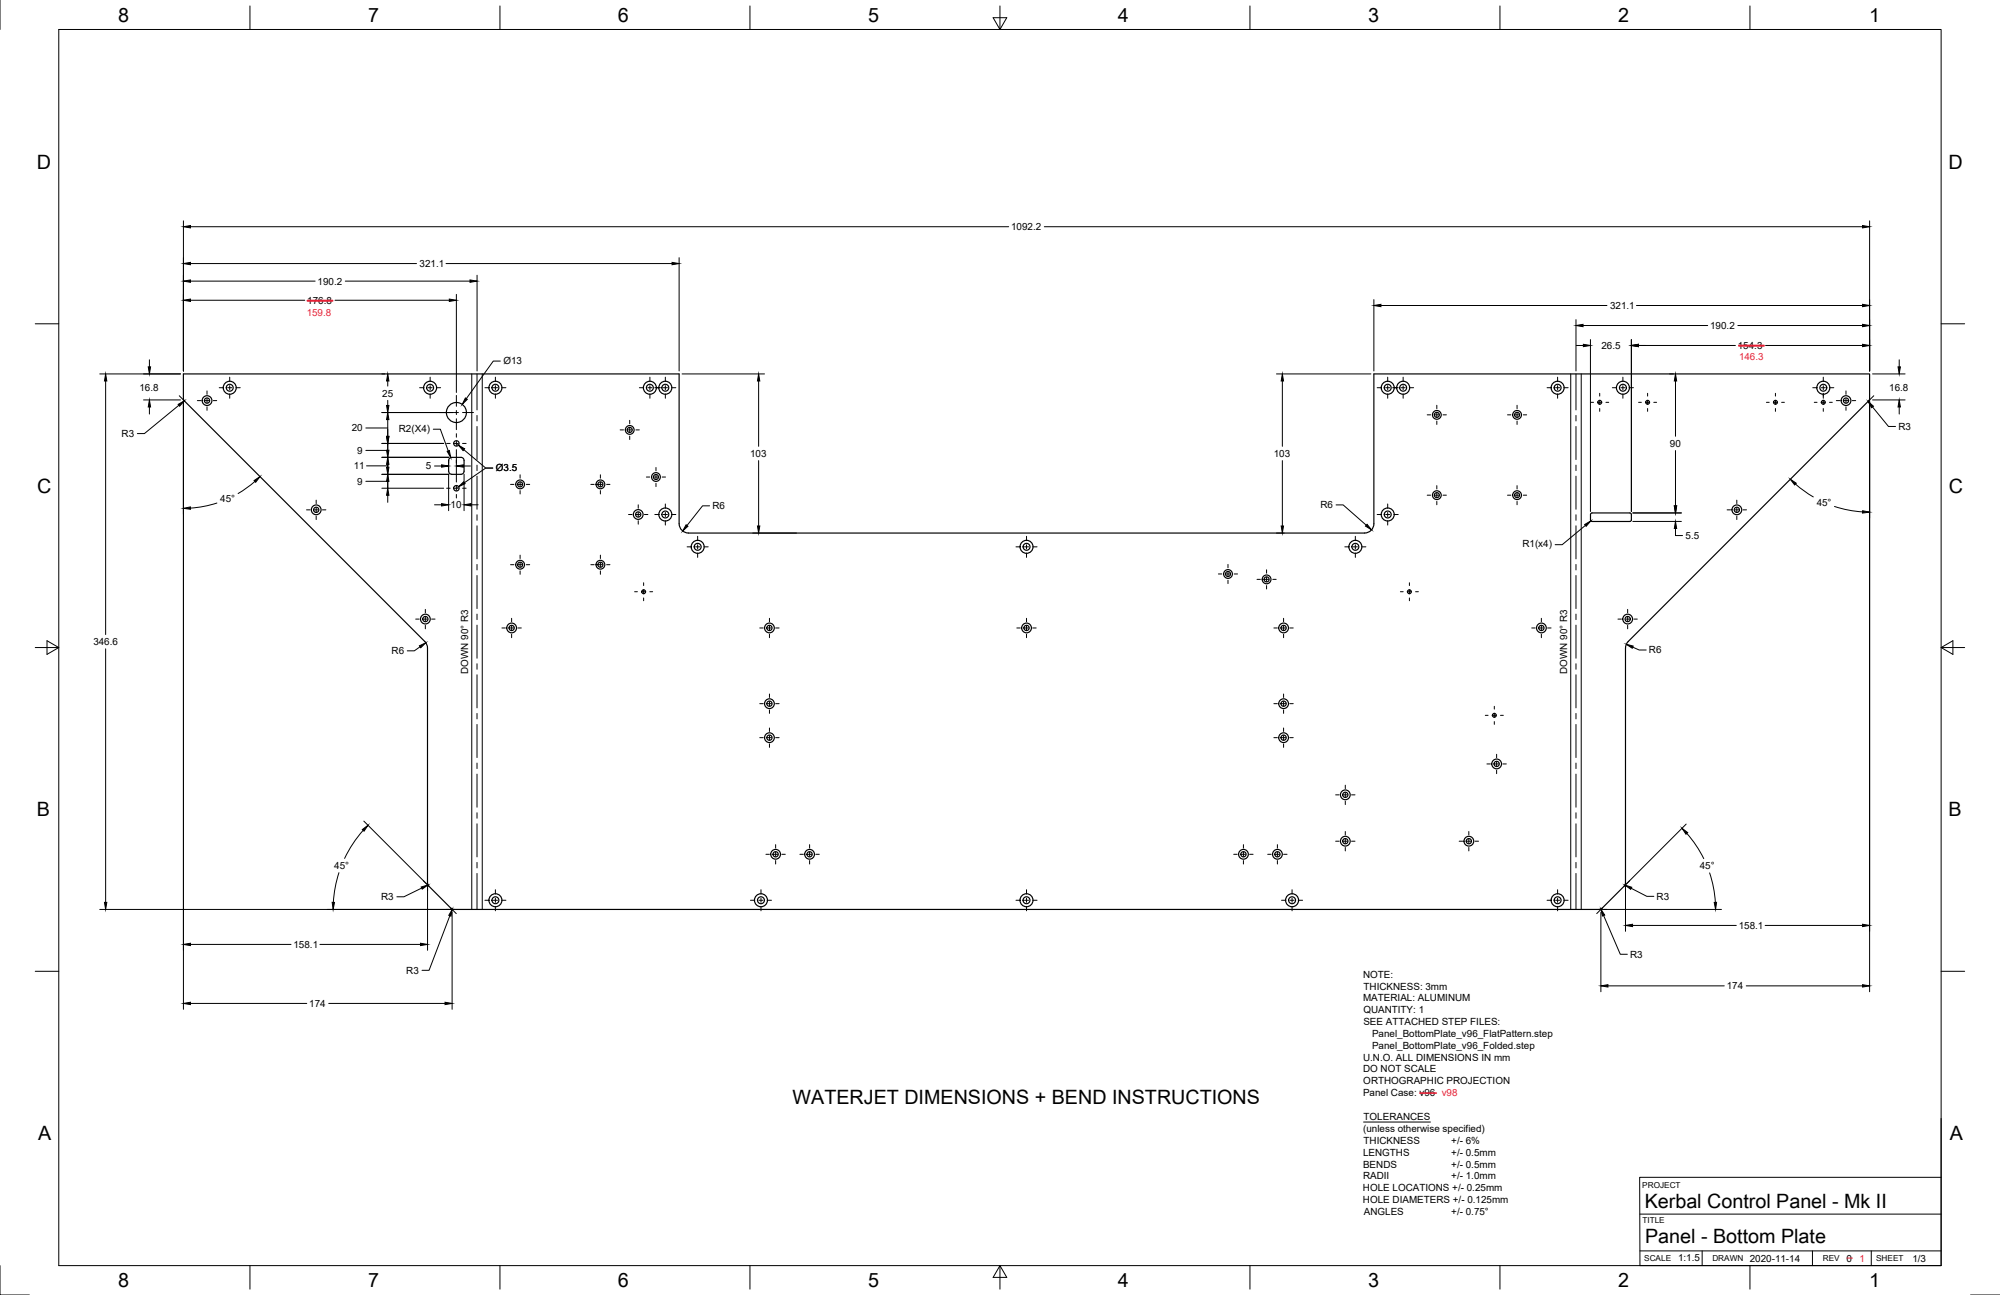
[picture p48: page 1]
SCALE 1:1.5; DRAWN 2020-11-14; REV 0; SHEET 1/3; THICKNESS; LENGTHS; BENDS; RADII; ANGLES; +/- 0.75° DOWN 90° R3; DOWN 90° R3

NOTE:
THICKNESS: 3mm
MATERIAL: ALUMINUM
QUANTITY: 1
SEE ATTACHED STEP FILES:
Panel_BottomPlate_v96_FlatPattern.step
Panel_BottomPlate_v96_Folded.step
U.N.O. ALL DIMENSIONS IN mm
DO NOT SCALE
ORTHOGRAPHIC PROJECTION
Panel Case: v96

WATERJET DIMENSIONS + BEND INSTRUCTIONS

TOLERANCES
(unless otherwise specified)
HOLE LOCATIONS +/- 0.25mm
HOLE DIAMETERS +/- 0.125mm

PROJECT
Kerbal Control Panel - Mk II

TITLE
Panel - Bottom Plate

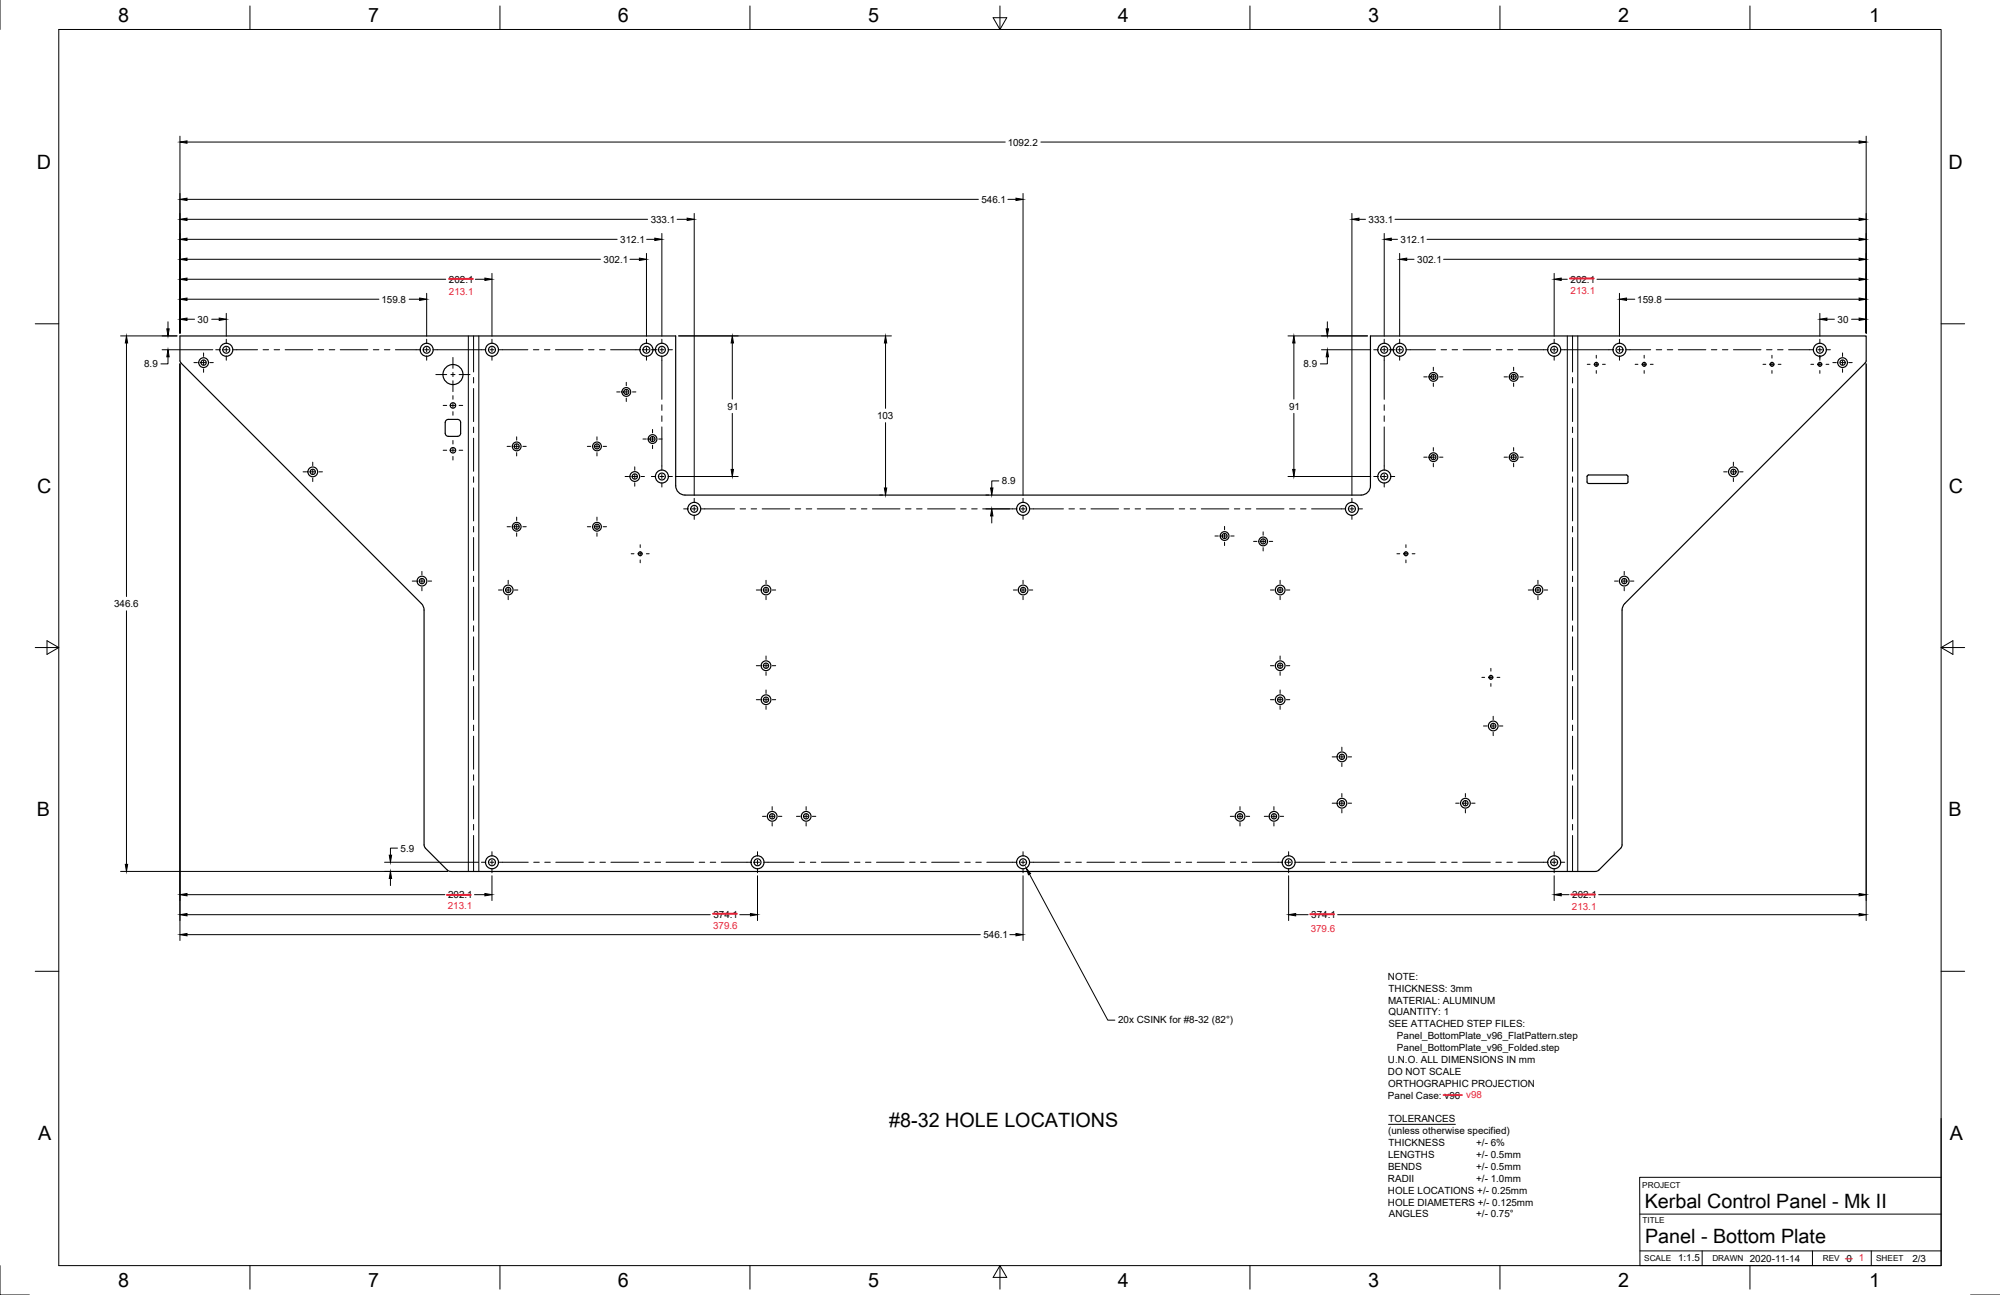
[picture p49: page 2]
SCALE 1:1.5; DRAWN 2020-11-14; REV 0; SHEET 2/3; #8-32 HOLE LOCATIONS; 20x CSINK for #8-32 (82°); THICKNESS; LENGTHS; BENDS; RADII; ANGLES

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

TOLERANCES
(unless otherwise specified)

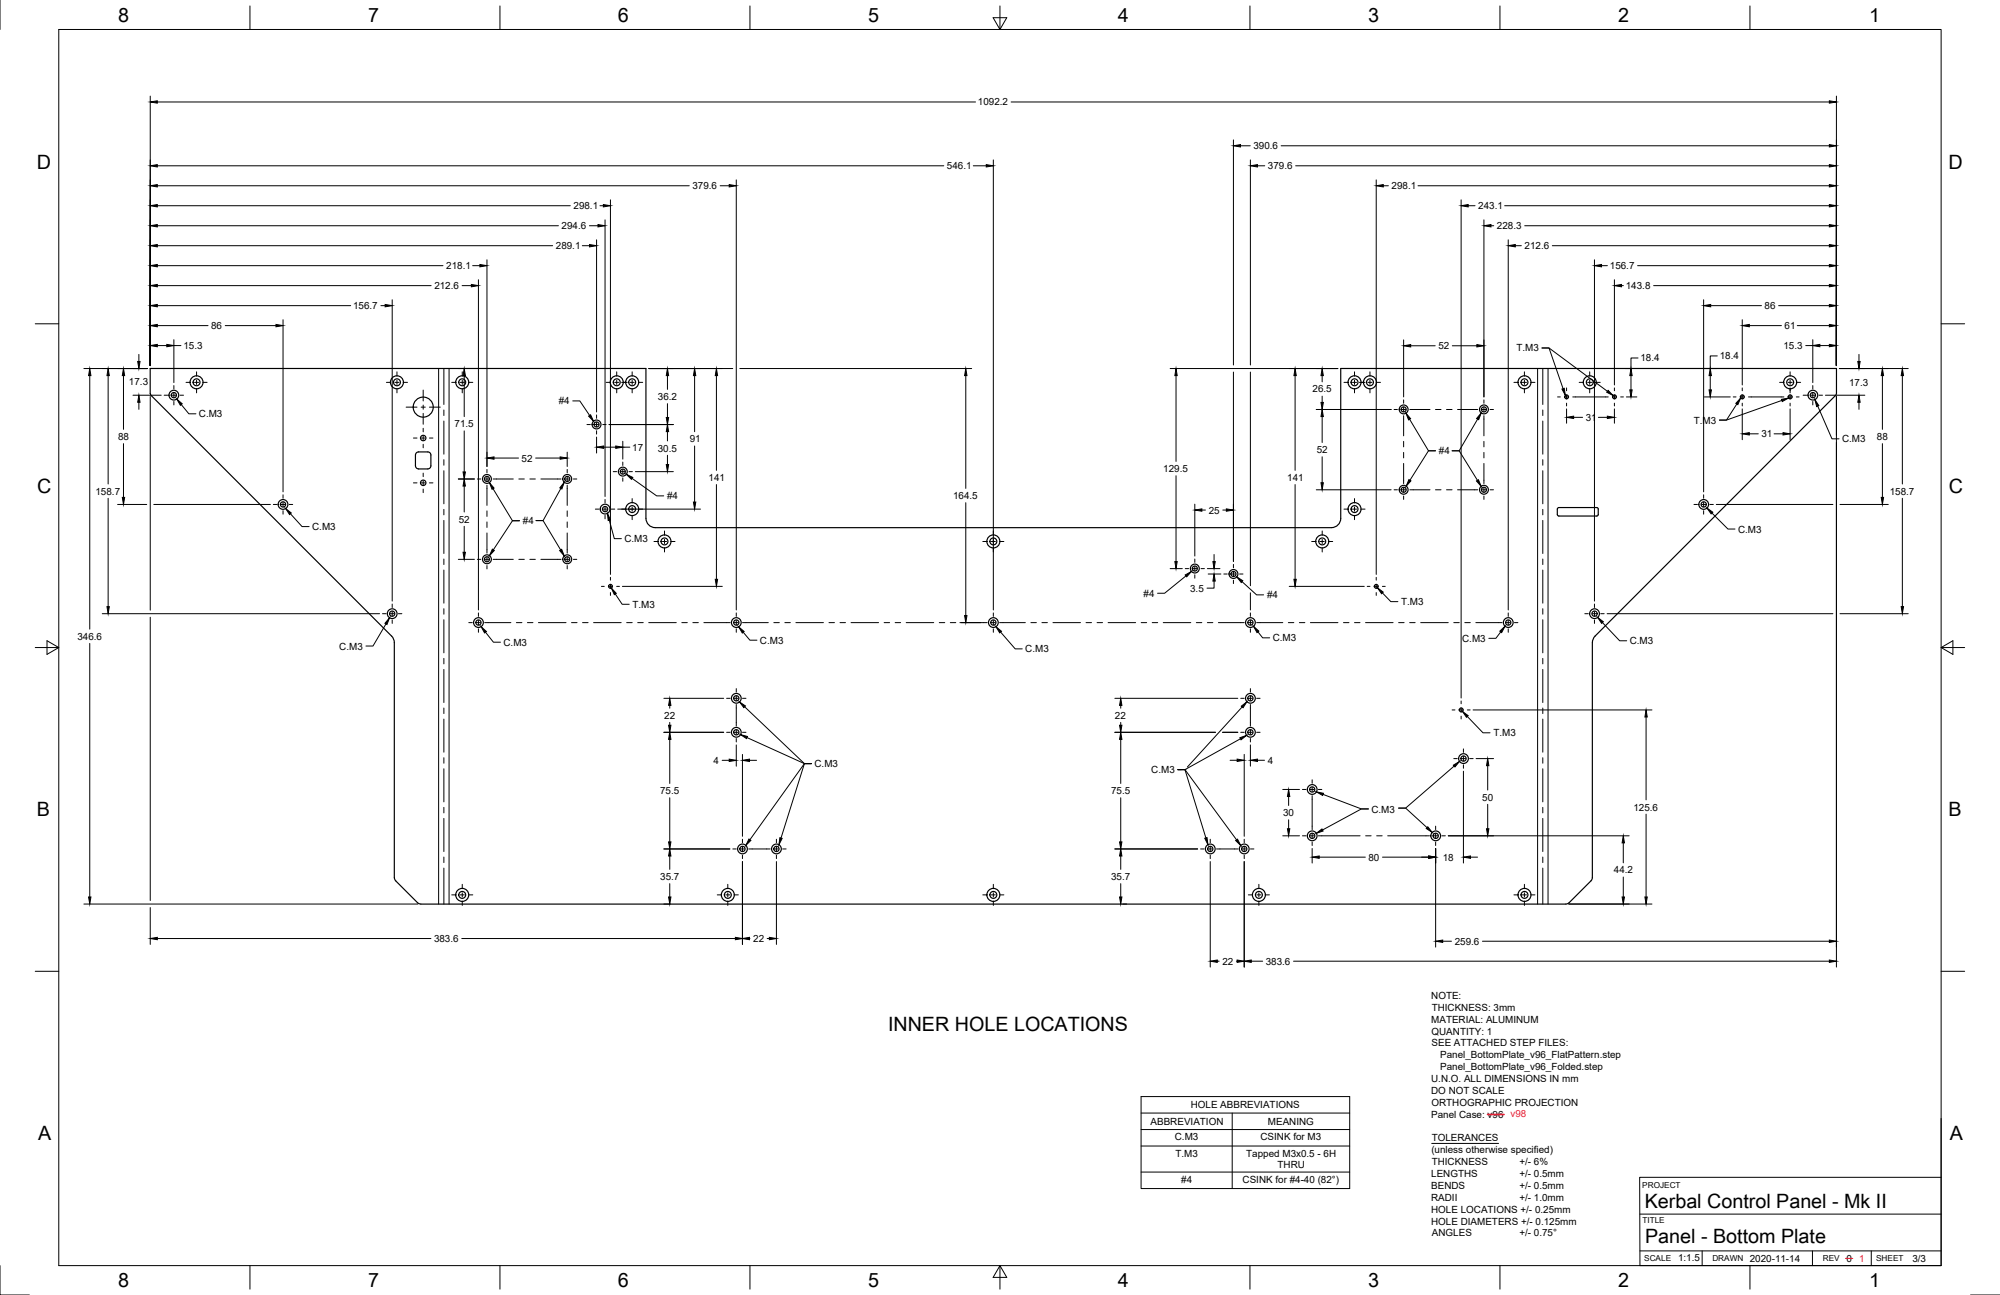
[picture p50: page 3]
SCALE 1:1.5; DRAWN 2020-11-14; REV 0; SHEET 3/3; THICKNESS; LENGTHS; BENDS; RADII; ANGLES; HOLE ABBREVIATIONS

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

INNER HOLE LOCATIONS

ABBREVIATION | MEANING
C.M3 | CSINK for M3
T.M3 | Tapped M3x0.5 - 6H THRU

TOLERANCES
(unless otherwise specified)

#4 | CSINK for #4-40 (82°)

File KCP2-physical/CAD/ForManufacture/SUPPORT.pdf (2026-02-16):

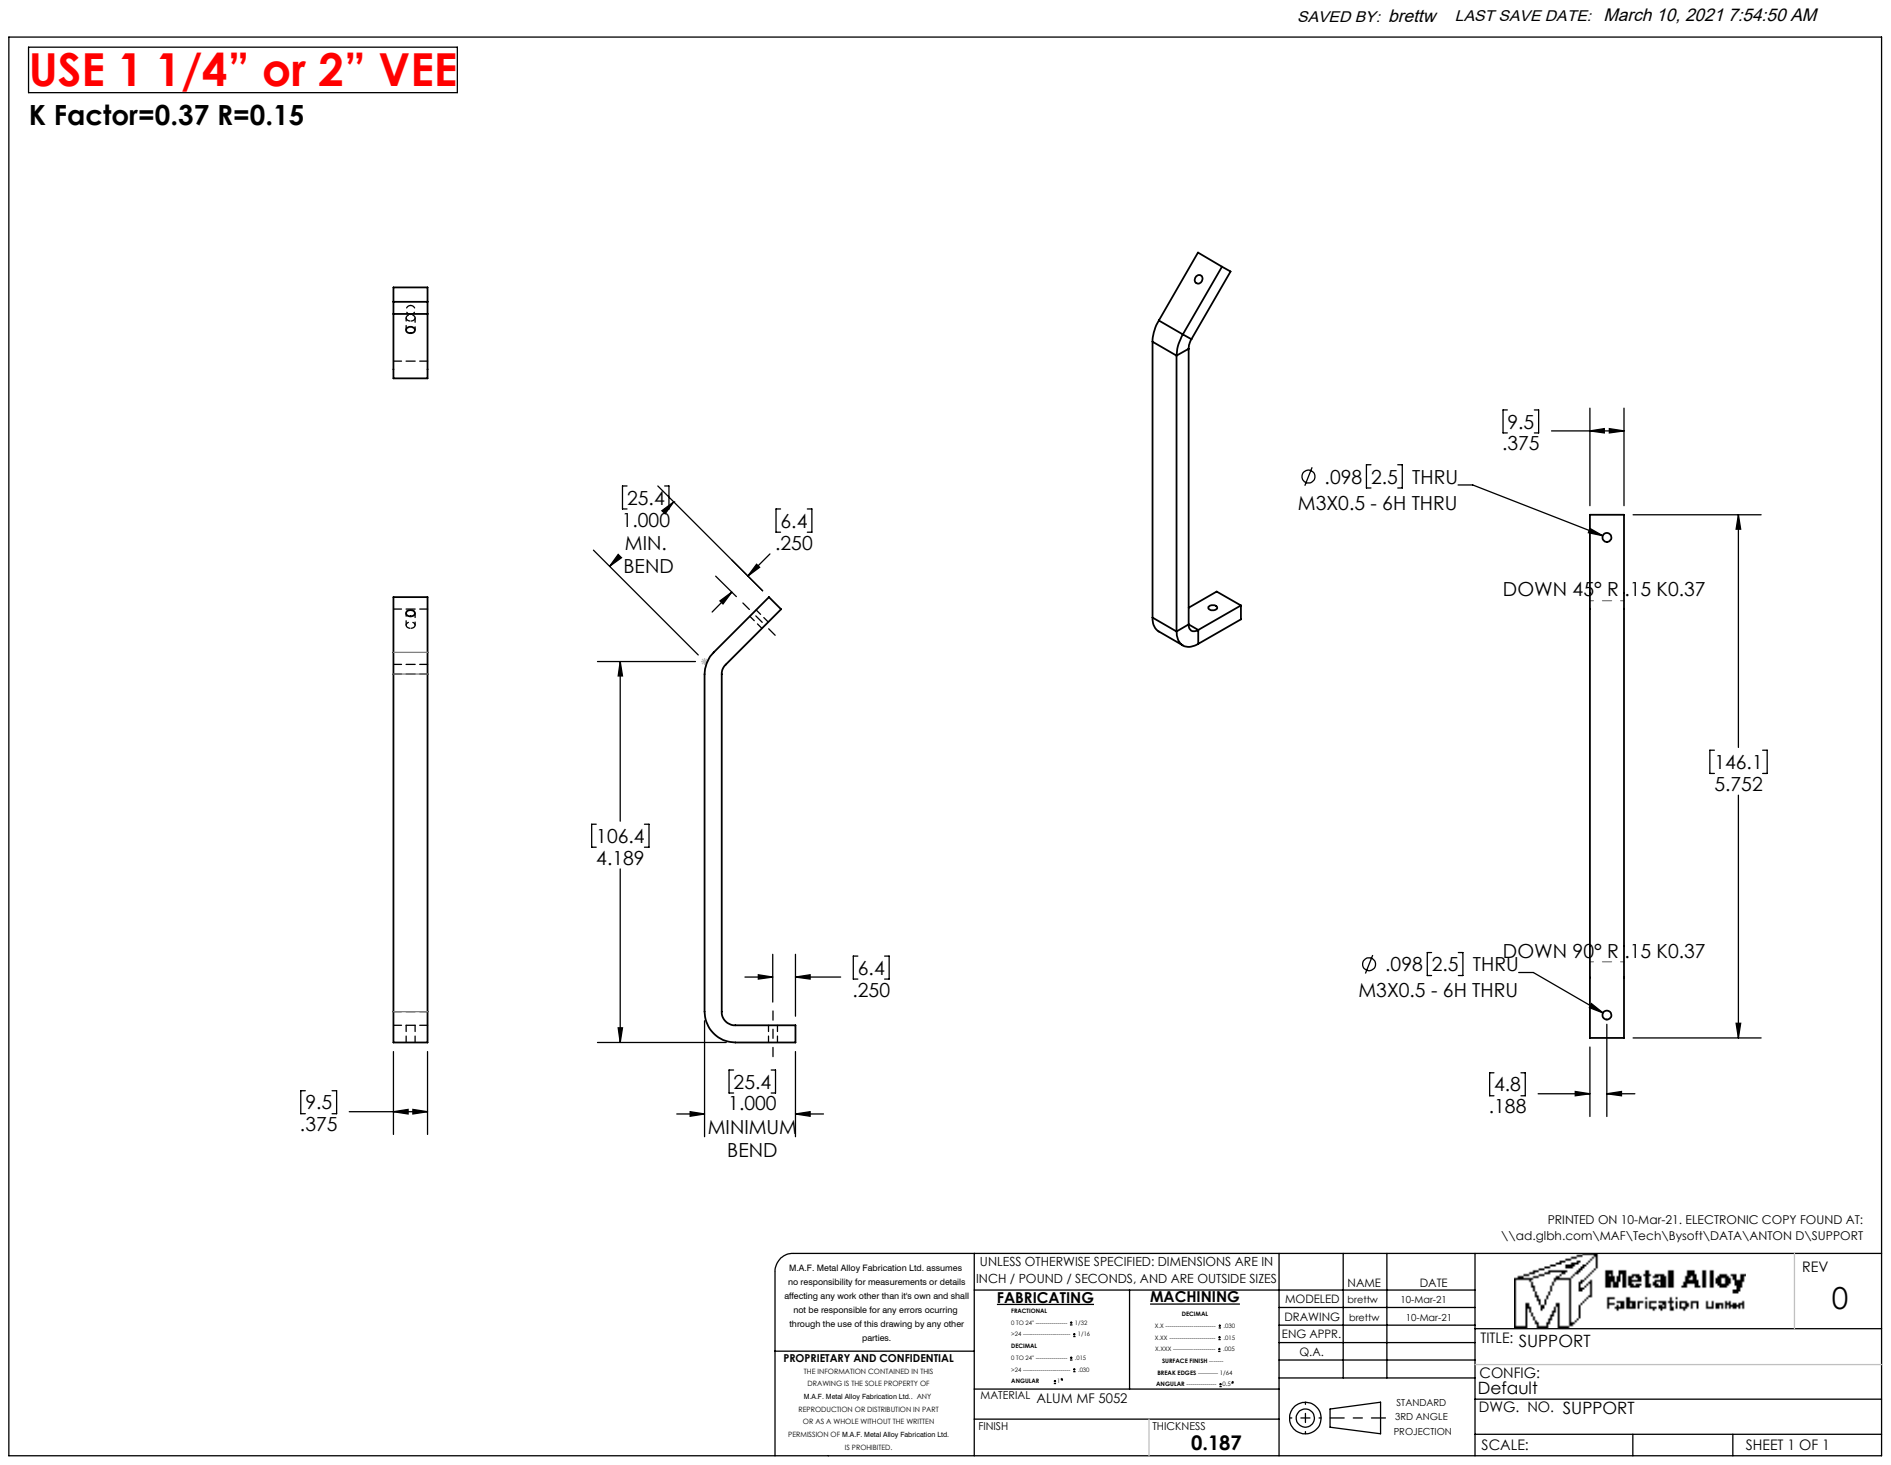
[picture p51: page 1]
.098 2.5 THRU M3X0.5 - 6H THRU; DOWN 45° R .15 K0.37; DOWN 90° R .15 K0.37; 3RD ANGLE; SHEET 1 OF 1; ENG APPR.; ALUM MF 5052; IS PROHIBITED.; MACHINING DECIMAL; X.X ------------------------- .030 X.XX ----------------------- .015 X.XXX --------------------- .005 SURFACE FINISH ------- BREAK EDGES ---------- 1/64 ANGULAR --------------- 0.5; DRAWING brettw; DWG. NO.

SAVED BY: brettw LAST SAVE DATE: March 10, 2021 7:54:50 AM

USE 1 1/4” or 2” VEE
K Factor=0.37 R=0.15

PRINTED ON 10-Mar-21. ELECTRONIC COPY FOUND AT:
\\ad.glbh.com\MAF\Tech\Bysoft\DATA\ANTON D\SUPPORT

M.A.F. Metal Alloy Fabrication Ltd. assumes
no responsibility for measurements or details
affecting any work other than it's own and shall
not be responsible for any errors ocurring
through the use of this drawing by any other

UNLESS OTHERWISE SPECIFIED: DIMENSIONS ARE IN
INCH / POUND / SECONDS, AND ARE OUTSIDE SIZES
FABRICATING FRACTIONAL

PROPRIETARY AND CONFIDENTIAL
THE INFORMATION CONTAINED IN THIS
DRAWING IS THE SOLE PROPERTY OF
M.A.F. Metal Alloy Fabrication Ltd.. ANY
REPRODUCTION OR DISTRIBUTION IN PART
OR AS A WHOLE WITHOUT THE WRITTEN
PERMISSION OF M.A.F. Metal Alloy Fabrication Ltd.

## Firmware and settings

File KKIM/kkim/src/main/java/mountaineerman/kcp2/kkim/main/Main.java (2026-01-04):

package mountaineerman.kcp2.kkim.main;

import mountaineerman.kcp2.kkim.service.KKIMService;


public class Main
{
	public static void main(String[] args)
	{
		System.out.println("=============================================================================================");
		System.out.println("Kerbal Control Panel 2 - Kerbal Kontroller Interface Module (KKIM)");
		System.out.println("=============================================================================================");
		
		KKIMService kkimService = new KKIMService();
		while(true) {
			kkimService.run();
		}
		//System.exit(0);
	}	
}

// import java.io.IOException;
// 
// public class Main {
//     public static void main(String[] args) {
//         System.out.println("Hello world!");
//         System.out.println("this is Anton");
//         System.out.println("java.version: " + System.getProperty("java.version"));
//         System.out.println("this is Anton again");
//     }
// }

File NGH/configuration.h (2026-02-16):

/*
 * NGH Configuration Settings
 */
#ifndef configuration_h
#define configuration_h

#include <Arduino.h>

enum TravelStatus {MOVING, STOPPED};

//===========================================================================================================================================================================
static const bool NGH_A = true;//true == NGH_A; false == NGH_B
//===========================================================================================================================================================================
//KMega Interface
static const int BAUD_RATE = 9600;//Did not work:115200 //Options: (from Arduino IDE Serial Monitor)  300  1,200  2,400  4,800  9,600  19,200  38,400  57,600  74,880  115,200  230,400  250,000  500,000  1,000,000  2,000,000
static const int SERIAL_READ_TIMEOUT_IN_MILLISECONDS = 10000; //The maximum amount of time NGH will wait before timing out during a serial read operation
static const byte PACKET_DELIMITER_BYTE = 0x3C; // 0x3C = '<'
static const int NUMBER_OF_PACKET_DELIMITER_BYTES = 3; //The number of consecutive packet delimiter bytes that mark the beginning of a packet
static const int GAUGE_PACKET_LENGTH_IN_BYTES = 21;//Length of Header + Payload. Does not include Packet Start Delimiter bytes.
static const int MAX_TIME_WITHOUT_PACKET_BEFORE_GAUGE_RESET_IN_MILLISECONDS = 5000;//The length of time without receiving a packet before all Gauges are set to the CCW position

//===========================================================================================================================================================================
//Stepper Motors
static const int STEPPER_MINIMUM_PULSE_WIDTH_IN_MICROSECONDS = 2; //The delay used for the "step" pulse for geared and NEMA17 stepper motors. Affects gauge speed when using StepperMotor2/NEMA17StepperMotor::runStepperIfNecessary().
static const int STEPPER_MINIMUM_WAIT_FOR_DIRECTION_CHANGE_IN_MICROSECONDS = 200;//The delay to re-polarize the coil whenever a Geared or NEMA17 stepper changes direction //TODO Optionally decrease for optimization. Google AI suggested 50 or 100 microseconds initially.
static const int STEPPER_AVERAGE_RUNSTEPPERIFNECESSARY_TIME_IN_MICROSECONDS = 22;
static const int STEPPER_CCW_LIMIT = 0;
static const int STEPPER_CW_LIMIT = 3779;
static const int MAX_GEARED_STEPPER_SPEED = 4000; // The maximum speed of the geared stepper motors (not NEMA17), in steps per second.
static const int MIN_GEARED_STEPPER_SPEED = 400; // The minimum speed of the geared stepper motors (not NEMA17), in steps per second. Also the speed they start with from standstill.
static const int GEARED_STEPPER_ACCELERATION_RATE = 20; //The rate by which the currentSpeed is increased/decreased for each iteration of StepperMotor2::runStepperIfNecessary()
static const int GEARED_STEPPER_DECELERATION_PARAM = 10; //See StepperMotor2::runStepperIfNecessary()
static const int NEMA17_STEPPER_MIN_POSITION = 0;
static const int NEMA17_STEPPER_HALF_OF_POSITIONS = 800;
static const int NEMA17_STEPPER_MAX_POSITION = 1599;
static const int NEMA17_TOTAL_NUMBER_OF_POSITIONS = 1600;
static const int NEMA17_MAX_SPEED = 1600; // The maximum speed of the NEMA17 stepper motor, in steps per second.
static const int NEMA17_MIN_SPEED = 100; // The minimum speed of the NEMA17 stepper motor, in steps per second. Also the speed it starts with from standstill.
static const int NEMA17_ACCELERATION_RATE = 8; //The rate by which the currentSpeed is increased/decreased for each iteration of NEMA17StepperMotor::runStepperIfNecessary()
static const int NEMA17_DECELERATION_PARAM = 4; //See NEMA17StepperMotor::runStepperIfNecessary()

//===========================================================================================================================================================================
//Pins

//[GaugePacketA]
//NGH A RX0 ---	connected to --- Arduino Mega TX2 (pin 16)
//NGH A TX1 ---	connected to --- Arduino Mega RX2 (pin 17)
static const int PIN_EASYDRIVER_SLP = 2;
static const int PIN_EASYDRIVER_MS1 = 3;
static const int PIN_EASYDRIVER_MS2 = 4;
static const int PIN_EASYDRIVER_STEP = 5;
static const int PIN_EASYDRIVER_DIR = 6;
static const int PIN_VID6606_1_FREQUENCY_HEATLIFE = 7;
static const int PIN_VID6606_1_DIRECTION_HEATLIFE = 8;
static const int PIN_VID6606_1_FREQUENCY_GFORCE = 9;
static const int PIN_VID6606_1_DIRECTION_GFORCE = 10;
static const int PIN_VID6606_1_FREQUENCY_MACH = 11;
static const int PIN_VID6606_1_DIRECTION_MACH = 12;
//13 UNASSIGNED
static const int PIN_VID6606_1_FREQUENCY_PITCH = A0;
static const int PIN_VID6606_1_DIRECTION_PITCH = A1;
static const int PIN_VID6606_2_FREQUENCY_FUEL = A2;
static const int PIN_VID6606_2_DIRECTION_FUEL = A3;
//A4 UNASSIGNED
//A5 UNASSIGNED
//A6 UNASSIGNED
//A7 UNASSIGNED
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

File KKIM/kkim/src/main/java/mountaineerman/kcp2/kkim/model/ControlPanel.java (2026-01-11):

package mountaineerman.kcp2.kkim.model;

import krpc.client.services.SpaceCenter.SASMode;
import krpc.client.services.SpaceCenter.VesselSituation;
import mountaineerman.kcp2.kkim.CommonUtilities;
import mountaineerman.kcp2.kkim.IP;
import mountaineerman.kcp2.kkim.KKIMProp;

/* MkII Control Panel
 */
public class ControlPanel implements LEDAggregator, StepperMotorAggregator {

	public ModuleA moduleA = null;
	public ModuleB moduleB = null;
	public ModuleC moduleC = null;
	public ModuleD moduleD = null;
	public ModuleE moduleE = null;
	public ModuleF moduleF = null;
	public ModuleG moduleG = null;
	public ModuleH moduleH = null;
	public ModuleI moduleI = null;
	public ModuleGT moduleGT = null;
	
	// Speed calibration settings:
	//                                                     Previous
	//                                           Stepper   Stepper
	//                             Speed (m/s)   Position  Position
	   private final int speedGauge_position_0 = 80;	// 0
	 private final int speedGauge_position_100 = 1150;	// 1060
	 private final int speedGauge_position_500 = 2210;	// 2130
	private final int speedGauge_position_3000 = 3600;	// 3540
	 private final int speedGauge_position_TRB = 3779;	// 3779
	
	// Vertical Speed calibration settings:
	//                                                             Previous
	//                                                   Stepper   Stepper
	//                            Vertical Speed (m/s)   Position  Position
	private final int vertSpeedGauge_position_minus200 = 0;		// 0       //NOTE: Calibration cannot quite reach the exact -200 mark (but very close)
	 private final int vertSpeedGauge_position_minus50 = 810;	// 835
	  private final int vertSpeedGauge_position_plus50 = 2940;	// 2965
	 private final int vertSpeedGauge_position_plus200 = 3755;	// 3770
	
	// Radar Altitude calibration settings:
	//                                                        Previous
	//                                              Stepper   Stepper
	//                         Radar Altitude (m)   Position  Position: 2025-12-17: No change since last calibration.
	   private final int radarAltGauge_position_0 = 110;	// 110
	 private final int radarAltGauge_position_100 = 1210;	// 1210
	 private final int radarAltGauge_position_500 = 2300;	// 2300
	private final int radarAltGauge_position_5000 = 3365;	// 3365
	 private final int radarAltGauge_position_ATM = 3570;	// 3570
	 private final int radarAltGauge_position_SPC = 3720;	// 3720

	//TODO WRAP IN KMEGA class:
	public SwitchSP2T brake = null;
	public float throttleLever = 0;	 //Range: 0(OFF) to 1(Max Thrust)
	public float joystick_FwdBck = 0;//Range: -1(Back) to 1(Forward)
	public float joystick_LftRgh = 0;//Range: -1(Right) to 1(Left)
	public float joystick_Twist = 0; //Range: -1(CCW) to 1(CW)
	
	//TODO WRAP IN KSP class:
	//TODO double-check variable types in kRPC...
	
	//TODO change comments below to Javadoc format like percentTemperatureHealth
	//TODO convert int percentages to float like percentFuel
	
	/** Health of the hottest part on the vessel. Range: 0 to 100. 0=bad, 100=good. */
	public int percentTemperatureHealth = 0;

	public float currentFood = 0;
	public float maxFood = 0;
	public int percentFood = 0;//Range: 0 to 100
	public float currentWater = 0;
	public float maxWater = 0;
	public int percentWater = 0;//Range: 0 to 100
	public float currentOxygen = 0;
	public float maxOxygen = 0;
	public int percentOxygen = 0;//Range: 0 to 100
	public int percentLifeSupport = 0;//Range: 0 to 100. Worst of Food/Water/Oxygen. Does not include Electric Charge, since it has its own dedicated gauge
	public float gforce = 0;
	public float mach = 0;
	public float pitch = 0;	 //Units: degrees. Range: -90.0 to +90.0
	public float heading = 0;//Units: degrees. Range: 0.0 to 360.0

	public float currentLiquidFuel = 0;
	public float maxLiquidFuel = 0;
	public float currentSolidFuel = 0;
	public float maxSolidFuel = 0;
	/** a) If there is any capacity for Solid Fuel, based on Solid Fuel. Otherwise:
	 *  b) If there is any capacity for Liquid Fuel, based on Liquid Fuel. Otherwise:
	 *  c) Zero. 
	 * 
	 * Range: 0.0 to 100.0 */
	private float percentFuel = 0;

	public float currentElectricCharge = 0;
	private float previousElectricCharge = 0;
	public float maxElectricCharge = 0;
	private int percentElectricCharge = 0;//Range: 0 to 100
	public float currentMonopropellant = 0;
	public float maxMonopropellant = 0;
	private int percentMonopropellant = 0;//Range: 0 to 100
	public float currentIntakeAir = 0;
	public float currentAirDensity = 0;//Units: kg/m^3
	public float maxAirDensity = 0;//Units: kg/m^3. The maximum air density for the object around which the vessel is orbiting.
	private int invertedPercentAirDensity = 0;//Range: 0 to 100. 0 = you are in the thickest part of the atmosphere. 100 = you are in vacuum.
	public double surfaceReferenceFrame_speed = 0;//Units: meters/second.
	public double surfaceReferenceFrame_verticalSpeed = 0;//Units: meters/second.
	public double orbitalReferenceFrame_speed = 0;//Units: meters/second.
	public double orbitalReferenceFrame_verticalSpeed = 0;//Units: meters/second.
	public float speedToDisplay = 0;//Units: meters/second. One of surfaceReferenceFrame_speed & orbitalReferenceFrame_speed, depending on position of SFC/ORB/TGT switch.
	public double altitudeAboveSurface = 0;//Units: meters. Measured from the center of mass of the vessel.
	public double altitudeAboveSeaLevel = 0;//Units: meters. Measured from the center of mass of the vessel.
	public float altitudeToDisplay = 0;//altitudeAboveSurface or altitudeAboveSeaLevel, depending on the position of the SpeedMode SP3T Switch
	public float apoapsis = 0;//Units: meters. Measured from the center of mass of the body being orbited. https://krpc.github.io/krpc/python/api/space-center/orbit.html#SpaceCenter.Orbit.apoapsis
	public float periapsis = 0;//Units: meters. Measured from the center of mass of the body being orbited. https://krpc.github.io/krpc/python/api/space-center/orbit.html#SpaceCenter.Orbit.periapsis
	public float secondsUntilApoapsis = 0;//https://krpc.github.io/krpc/python/api/space-center/orbit.html#SpaceCenter.Orbit.time_to_apoapsis
	public float secondsUntilPeriapsis = 0;//https://krpc.github.io/krpc/python/api/space-center/orbit.html#SpaceCenter.Orbit.time_to_periapsis
	public float secondsUntilApoPeri = 0;//Combination of secondsUntilApoapsis & secondsUntilPeriapsis: the closer of the two. Positive (+) if until Apo, negative (-) if until Peri.
	public short currentDraw = 0;//Units: mA. Based on sensor in ModuleF.
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

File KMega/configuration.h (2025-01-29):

/*
 * KMega Configuration Settings
 */
#ifndef configuration_h
#define configuration_h

#include <Arduino.h>

//===========================================================================================================================================================================
//Common Serial Communication Settings
static const int SERIAL_READ_TIMEOUT_IN_MILLISECONDS = 10000; //The maximum amount of time kMega will wait before timing out during a serial read operation
static const byte PACKET_DELIMITER_BYTE = 0x3C; // 0x3C == '<' == 0d60
static const int NUMBER_OF_PACKET_DELIMITER_BYTES = 3; //The number of consecutive packet delimiter bytes that mark the beginning of a packet
static const int PACKET_HEADER_LENGTH_IN_BYTES = 9;
static const int ARDUINO_SERIAL_WRITE_BUFFER_LENGTH_IN_BYTES = 64;//Note: the Arduino Serial buffer is 64 Bytes long by default. See: https://www.hobbytronics.co.uk/arduino-serial-buffer-size#:~:text=The%20Arduino%20core%20code%20contains,only%2064%20bytes%20in%20size.


//KKIM Interface
static const String COMMUNICATION_PORT = "COM3";
static const unsigned long COMPUTER_BAUD_RATE = 115200; //Options: (from Arduino IDE Serial Monitor)  300  1,200  2,400  4,800  9,600  19,200  38,400  57,600  74,880  115,200  230,400  250,000  500,000  1,000,000  2,000,000
static const int REFRESH_PERIOD_IN_MILLISECONDS = 1;//TODO replace in program...
static const int INPUT_REFRESH_PACKET_SEND_RATE_IN_MILLISECONDS = 100; //100 seems pretty snappy, 500 is noticeably too slow
static const int OUTPUT_REFRESH_PACKET_LENGTH_IN_BYTES = 195;//Length of Header + Payload. Does not include Packet Start Delimiter bytes.
static const int INPUT_REFRESH_PACKET_LENGTH_IN_BYTES = 31;  //Length of Delimiter + Header + Payload.
static const int MAX_TIME_WITHOUT_OUTPUT_REFRESH_PACKET_BEFORE_ERROR_IN_MILLISECONDS = 1000; //The length of time before the controlPanel.moduleG.ledPWM_Comms LED will start flashing, indicating no output packet has been received
static const int MAX_TIME_WITHOUT_OUTPUT_REFRESH_PACKET_BEFORE_IDLE_IN_MILLISECONDS = 5000;  //The length of time before all LEDs are dimmed to "idle" state
static const int MAX_TALLY_TIME_FOR_DIAGNOSTICS_IN_MILLISECONDS = 1000;

//KNano Interface
static const unsigned long KNANO_BAUD_RATE = 9600;
static const int ALTITUDE_PACKET_LENGTH_IN_BYTES = 16;  //Length of Delimiter + Header + Payload.
static const float STARTING_ALTITUDE = -1.0e1;

//NGH A and B Interfaces
static const unsigned long NGH_BAUD_RATE = 9600; //BAUD rate used for communicating with NGH A and B
static const int GAUGE_PACKET_LENGTH_IN_BYTES = 24;  //Length of Gauge Packet A and Gauge Packet B, including Delimiter + Header + Payload.

//===========================================================================================================================================================================
//Multiplexer
static const int MULTIPLEXER_IO_ROW_1 = 1;
static const int MULTIPLEXER_IO_ROW_2 = 2;
static const int MULTIPLEXER_IO_ROW_3 = 3;

//ROW 1 (Input Pullup)
// 0 UNASSIGNED
static const int PIN_MUX_BRAKE_BUTTON = 1;
static const int PIN_MUX_JOYSTICK_BUTTON = 2;
static const int PIN_MUX_BRAKE_SWITCH = 3;
static const int PIN_MUX_AUTOPILOT_HOLD_BUTTON = 4;
static const int PIN_MUX_AUTOPILOT_PROGRADE_BUTTON = 5;
static const int PIN_MUX_AUTOPILOT_RETROGRADE_BUTTON = 6;
static const int PIN_MUX_AUTOPILOT_NORMAL_BUTTON = 7;
static const int PIN_MUX_AUTOPILOT_ANTINORMAL_BUTTON = 8;
static const int PIN_MUX_AUTOPILOT_RADIALIN_BUTTON = 9;
static const int PIN_MUX_AUTOPILOT_RADIALOUT_BUTTON = 10;
static const int PIN_MUX_AUTOPILOT_ANTITARGET_BUTTON = 11;
static const int PIN_MUX_AUTOPILOT_MANEUVER = 12;
static const int PIN_MUX_AUTOPILOT_TARGET_BUTTON = 13;
static const int PIN_MUX_FAIRING_BUTTON = 14;
static const int PIN_MUX_CHUTE_BUTTON = 15;

//ROW 2 (Input)
static const int PIN_MUX_STAGING_BUTTON = 0;
static const int PIN_MUX_ABORT_BUTTON = 1;
static const int PIN_MUX_PITCH_TRIM_SWITCH = 2;
static const int PIN_MUX_YAW_TRIM_SWITCH = 3;
static const int PIN_MUX_ROLL_TRIM_SWITCH = 4;
static const int PIN_MUX_SAS_SWITCH = 5;
static const int PIN_MUX_RCS_SWITCH = 6;
static const int PIN_MUX_LIGHTS_SWITCH = 7;
static const int PIN_MUX_GEAR_SWITCH = 8;
static const int PIN_MUX_MAP_SWITCH = 9;
static const int PIN_MUX_MUTE_SWITCH = 10;
// 11 UNASSIGNED
// 12 UNASSIGNED
static const int PIN_MUX_SFC_SWITCH = 13;
static const int PIN_MUX_TGT_SWITCH = 14;
static const int PIN_MUX_RKT_SWITCH = 15;
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

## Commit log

2020-12-05 Adding KKIM/KMega/KNano skeleton
    [settings.cfg]
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2020-12-31 Corrected AnalogInput exception message brackets: () vs []
    [AnalogInput.java]
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2021-01-04 KMega/KNano - Solved how to include header/cpp files. Created folder structure for Parts classes and LocalArduinoLibraries. Created preliminary configuration files.
    [configuration.h]
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2021-01-09 Added arduino mega pin configs; removed kmega settings from kkim
    [configuration.h]
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2021-01-09 Fixed Mux library include path in SwitchSP2T (relative path issue)
    [SwitchSP2T.cpp]
2021-01-10 Added AltitudeGauge
    [configuration.h]
2021-01-11 Added StepperMotor
    [configuration.h]
2021-01-13 Added StepperMotorNEMA17
    [configuration.h]
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2021-01-17 Added LED
    [configuration.h]
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2021-12-27 Moved "LED" comments out of KMega.cpp and into an inert header, "LED.h"
2021-12-27 Fixed SwitchSP2T::refreshStatus()
2021-12-28 UNCOMPILED: 1) Added Class template file, Name. 2) Created skeleton for Arduino Mega's Control Panel Model (ControlPanel and ModuleX classes). 3) Migrated mux and ledDriverBoards initialization into 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
2022-01-13 1) Updated #include statements to use full paths for local files; 2) Switched from using Eclipse to using Arduino IDE for compilation/deployment.
2022-01-14 Added an arduino project, LibraryExperiment, to test limitations of #include with Arduino. Added LibraryExperiment to gitignore list.
2022-01-14 Fixed libraries per Arduino's limitations (flat folder structure).
2022-01-20 Updated configuration to include: 1) Mux pins, 2) LED Driver Board pins, 3) Clarified Pitch/Yaw/Roll pins, 4) 4POS Switch pins.
    [configuration.h]
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2022-01-21 Added Interface_LEDAggregator. Added Modules D, F, and H.
    [configuration.h]
2022-01-22 Temporary fix for "overflow" error encountered while viewing input status after activating Module H.
    [configuration.h]
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2022-01-22 Added Interface_StepperMotorAggregator and ModuleC. Basic StepperMotor functionality is now functional.
    [configuration.h]
2022-02-22 Created initial version of KNano, capable of testing 7seg display and altitude label wiring, running in a continuous loop. No Serial Comms yet.
    [configuration.h]
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2022-02-24 1) Added instructions for how to switch from knano to kmega. 2) Fixed LED Driver Board 4 pin configuration.
    [configuration.h]
2022-02-27 Module H: Moved PIN_GLASS_COCKPIT_TL_SWITCH from pin 12 to 52. 12 appears faulty.
    [configuration.h]
2022-02-27 Added Module E.
    [configuration.h]
2022-03-03 Added Module G (preliminary).
    [configuration.h]
2022-03-04 Added Module I (untested).
    [configuration.h]
2022-03-06 Fixed Fuel and Charge Stepper Motor inversion. Cleaned up LED Driver Board pin configuration.
    [configuration.h]
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2022-03-10 Forced NEMA17 stepper motor to sleep when not in motion (prevents high pitch buzz).
2022-03-10 Added preliminary code to test Serial connection with KKIM.
    [configuration.h]
2022-03-16 Added initial capability to read an incoming Packet.
    [configuration.h]
2022-03-19 (PARTIAL: 1/3) Moved functionality from KMega.ino to KMegaService.
    [configuration.h]
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2022-03-20 Fixed bug introduced in previous commit, where moduleX.setAllLEDsOff() and moduleX.setAllLEDsOn() were calling LED_PWM.setPWMAndWriteImmediately() instead of LED_PWM.setPWM()
2022-03-21 Added preliminary version of PacketAssembler.
    [configuration.h]
2022-03-21 Added SerialCommunicator.sendInputRefreshPacket() and communications diagnostic information tracking.
    [configuration.h]
2022-03-22 Final KMega cleanup for end-to-end test. Fixed inputRefreshPacket size (28 bytes, not 29). Populated Delimiter and Header in inputRefreshPacket. Fixed SerialCommunicator.timer variable name.
    [configuration.h]
2022-03-24 1) Made Properties globally accessible. 2) Deleted unused LinkedList and Utilities projects. 3) Renamed mountaineerman.kcp2.kkim.app.model to mountaineerman.kcp2.kkim.model 4) Added placeholder for K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
    [settings.cfg]
2022-03-26 1) Slowed refresh rate to 1 second for testing. 2) Fixed size of INPUT_REFRESH_PACKET_LENGTH_IN_BYTES to include the Delimiter. 3) Fixed bug in populating inputRefreshPacket's Header.
    [configuration.h]
2022-03-27 Lowered idle time to 10 seconds.
    [configuration.h]
2022-04-01 Got simultaneous inputRefreshPacket and outputRefreshPacket working. 1) PacketUnpacker.convertTwoBytesInOutputRefreshPacketIntoInteger(): fixed order of smallestByteNum/largestByteNum. 2) PacketAssem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
    [configuration.h]
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2022-04-02 First working end-to-end test from KSP to KMega. Added logic to send an inputRefreshPacket no more frequently than X milliseconds.
    [configuration.h]
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2022-04-07 Re-enabled sending inputRefreshPackets.
    [configuration.h]
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2022-04-08 Raised BAUD RATE to 115200.
    [configuration.h]
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2022-04-12 Replaced ...resetStepperToStartingPosition() with ControlPanel::blockRunAllSteppersToPosition(long position). Simplified ControlPanel::sweepStepperMotorsThroughMaxMinToCalibrate(). Added KMegaService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
    [configuration.h]
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2022-04-14 Added isInverted property to AnalogInputs. Inverted Throttle and MultiPot inputs.
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2022-04-16 Added AltitudePacket and associated processing (KMegaService, ControlPanel, PacketUnpacker, PacketAssembler, SerialCommunicator). Note: code is uncompiled and untested.
    [configuration.h]
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2022-04-16 Brought KNano up-to-date based on KMega, including: KNano.ino, KNanoService, SerialCommunicator, PacketUnpacker. Scrapped GaugeTower. Note: uncompiled, untested.
    [configuration.h]
2022-04-18 Added initial replacement for AccelStepper (temporarily StepperMotor2). Note: untested and uncompiled.
    [configuration.h]
2022-04-18 Preliminary version for controlling KSP via joystick and throttle (uncompiled and untested with known errors).
    [ControlPanel.java]
2022-04-24 Fixed compilation errors introduced in 'Fairmont' commits (a2aba3c to 0fa0115). StepperMotor2 now functional (tested with G-Force gauge in diagnostic mode).
    [configuration.h]
2022-04-24 Got SP4T Sensitivity Switch working (including LEDs). Fixed most compile errors introduced in 'Fairmont' commits (4305951 and 0347bbc).
    [ControlPanel.java, OP.java, PacketAssembler.java]
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2022-04-24 Combined GEARED_STEPPER_CCW_LIMIT and NEMA17_CCW_LIMIT into STEPPER_CCW_LIMIT.
    [configuration.h]
2022-04-24 Combined GEARED_STEPPER_CCW_LIMIT and NEMA17_CCW_LIMIT into STEPPER_CCW_LIMIT (missed some files in previous commit).
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2022-05-05 Altitude Gauge working. Details: 1) Lowered BAUD rate for comms with KNano. 2) Saved constant text to FLASH instead of SRAM using PROGMEM F() macro. 3) Fixed KMega's ability to unpack the altitude fr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
    [configuration.h]
2022-05-05 Altitude Gauge working. Details: 1) Lowered BAUD rate for comms with KMega. 2) Fixed KNano's ability to unpack the altitude from the AltitudePacket. 3) Added conversion from float altitude to what th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
    [configuration.h]
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2024-07-15 kmega: disabled stepper motor functionality until performance issue is resolved
2024-07-15 kmega: added flashing COMMS LED when there are not outputRefreshPackets being received
    [configuration.h]
2024-08-12 Updated launch cmd scripts for convenience; fixed git bash launch command (problem with git switch).
2024-08-13 Fixed communication failure between KKIM and KMega by resetting COM port to COM3
    [configuration.h]
2024-08-13 Replaced separate Red/Green/Blue LEDs with an RGB_PWM_LED (for Fuel lightbox); Organized ControlPanel.refresh(); Updated LED_PWM and LED_PWM_RGB to use OP in constructors; Disabled Fuel Stepper Motor
    [ControlPanel.java, LED_PWM.java, LED_PWM_RGB.java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]
2024-08-13 Added all missing LEDs to OP file
    [OP.java]
2024-08-13 Activated remaining Module I LEDs (Delta Charge, Charge, Monopropellant). Ran into problem with reading Intake Air, will resolve later.
    [ControlPanel.java, LED_PWM_RGB.java, PacketAssembler.java]
2024-08-18 Added KMega logic such that if an outputControlPacket has not been received for a while, all LEDs are set to a 'dim' state.
    [configuration.h]
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2024-12-30 Added time warp button functionality
2024-12-30 Fix: inverted Pitch for Plane mode
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2024-12-31 Added debounce logic to SwitchMom; fixed KKIMProp:settingsFilename
    [ControlPanel.java, KKIMProp.java]
2025-01-02 Added DefaultActionGroups configs (Science, Reset, Solar Panels, Ladders, Fairings, Parachutes)
    [Custom04_ScienceExperiments.cfg, Custom05_ResetScience.cfg, Custom06_SolarPanels.cfg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]
2025-01-02 Fixed fairing/chute LEDs to use raw status instead of debounced
    [ControlPanel.java]
2025-01-02 Fixed SAS autopilot lights starting dimmed instead of On/Off depending on the position of the SAS switch.
2025-01-04 1) Converted all stepper motors from StepperMotor to StepperMotor2 class. 2) Re-enabled geared steppers. 3) Added stepper sweeping to diagnostic mode. 4) Fixed motor direction inversion: Heat/Life, M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
    [configuration.h]
2025-01-06 Enabled Fuel gauge (slow). Added some diagnostic modes for steppers.
    [configuration.h]
2025-01-14 NanoGaugeHelper initial draft (unverified)
    [configuration5.h, configuration6.h]
2025-01-18 NGH: Fixed compilation errors and prepped for gaugePacket6 test; Corrected Pitch gauge direction.
    [configuration.h]
2025-01-18 NGH: Added gauge reset without recent packet (untested)
    [configuration.h, configuration5.h, configuration6.h]
2025-01-18 NGH: Added (NEMA17) Heading Gauge (working)
    [configuration.h, configuration6.h, configurationA.h]
2025-01-18 KMega: Enabled (NEMA17) Heading Gauge; removed AccelStepper library; removed obsolete StepperMotor class
    [configuration.h]
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2025-01-19 Updated architecture diagram based on NGH; minor KKIM gaugePacketA/B fix.
    [ControlPanel.java]
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2025-01-26 NGH: Added A+B pin assignments; switched to NGH B + final cleanup (untested)
    [configuration.h, configurationA.h]
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2025-01-29 NGH: Fixed Serial1 instead of Serial; Added missing charge gauge to blockRunAllGearedSteppersToPosition().
    KMega: Added logic to send gauge packets. Removed Stepper pin information.
    Verified working with KMega and KKIM (2 gauge test).
    [configuration.h]
2025-02-01 KKIM: Fixed vertical speed gauge calculations; added StepperMotor unit test; added StepperMotor exception
    [ControlPanel.java, StepperMotor.java]
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2025-02-03 KKIM: Made KKIM Diagnostic Mode functional - various fixes/improvements (tested)
    [ControlPanel.java, KKIMProp.java]
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2025-02-03 NGH: fixed periodic slips by slowing down runStepperIfNecessary (tested); added support for commands (tested)
    [configuration.h]
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2025-12-16 Re-organized DefaultActionGroups files (WIP)
    [Antennas_in_Custom03.cfg, Collect_Science_in_Custom08.cfg, Custom04_ScienceExperiments.cfg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]
2025-12-16 Fixes for linux: adjusted config.properties path; updated COM port from COM3 to ttyACM0.
    [KKIMProp.java]
2025-12-16 Replaced references to OneNote with Joplin
    [OP.java, PacketAssembler.java]
2025-12-18 KKIM: fixed clearScreen(); disabled (OVER)HEAT.
    [ControlPanel.java]
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2025-12-19 NGH: Split NGH into NGH_A and NGH_B
    [configuration.h]
2025-12-20 NGH: (TESTED:GOOD) Final missed minor changes to NGH repos.
    [configuration.h]
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2025-12-22 KKIM: (UNTESTED) Fixed (visual) MUTE behaviour (actions only on state change, re-enable glass cockpit lights on unmute).
    [ControlPanel.java]
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2025-12-22 NGH: updated notes for linux; fixed stepper decalibration; recombined NGH A/B.
    [configuration.h]
2025-12-22 NGH: (UNTESTED) Completed NGH A/B recombination by renaming NGH_A back to NGH.
    [configuration.h]
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2025-12-22 Created keybindings (including mods); updated settings.
    [1_KeyBindings.ods]
2026-02-16 Added KCP2-physical (drawings, BOM, etc).
    [#3-48 Nut.stp, #3-48x5-8 Flat Head Socket Cap Screw.stp, #4-40x3-16 Hex Socket Head Cap Screw.stp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]
2026-02-16 NGH: (UNTESTED) Updates to NEMA17 to add acceleration logic.
    [configuration.h]
